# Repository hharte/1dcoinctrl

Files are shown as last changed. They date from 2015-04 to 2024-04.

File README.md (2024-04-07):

# 1dcoinctrl - Issue 4

## Western Electric 1D/2D Payphone Controller Interface for Asterisk

# WARNING - This project involves potentially lethal High-Voltage!

**_The coin relay in most payphones operates using +/- 130VDC.  This project uses a DC-DC converter to boost 12VDC to 130VDC.  Construction and operation of this circuit should only be performed by people familiar with best practices when operating with high voltage, and using extreme caution._**

I WILL NOT BE HELD LIABLE FOR INJURY OR DEATH RESULTING FROM BUILDING OR USING THIS CIRCUIT.   BUILD AND USE THIS CIRCUIT AT YOUR OWN RISK.

THIS HARDWARE AND SOFTWARE IS PROVIDED "AS IS", WITHOUT WARRANTY OF ANY KIND, EXPRESS OR IMPLIED, INCLUDING BUT NOT LIMITED TO THE WARRANTIES OF MERCHANTABILITY, FITNESS FOR A PARTICULAR PURPOSE AND NONINFRINGEMENT.  IN NO EVENT SHALL HOWARD M. HARTE BE LIABLE FOR ANY CLAIM, DAMAGES OR OTHER LIABILITY, WHETHER IN AN ACTION OF CONTRACT, TORT OR OTHERWISE, ARISING FROM, OUT OF OR IN CONNECTION WITH THE HARDWARE AND SOFTWARE OR THE USE OR OTHER DEALINGS IN THE HARDWARE AND SOFTWARE. 

# Overview

This project aims to emulate a coin line as required by the older "dumb" (ie, non-COCOT) payphones such as the Western Electric 1D "Fortress" series.  This coin line interface connects in between an Asterisk PBX and the payphone.  It provides the coin control functionality as well as the ability to determine whether an initial rate has been deposited, and can also perform the "stuck coin" test.

This project is based on another open-source project (see References below) and has the following goals:

1. Real coin-line signaling, while preserving the payphone earth ground.  This requires both +130VDC (coin collect) and -130VDC (coin refund) as well as +25VDC for the "stuck coin" test and -25VDC for the "initial rate" test.
2. The ability to provide up to four coin lines in a single unit.
3. The ability to count dial pulses from Rotary payphones and provide the digits out-of-band to Asterisk.
4. The ability to be [red-boxed](http://en.wikipedia.org/wiki/Red_box_(phreaking)).

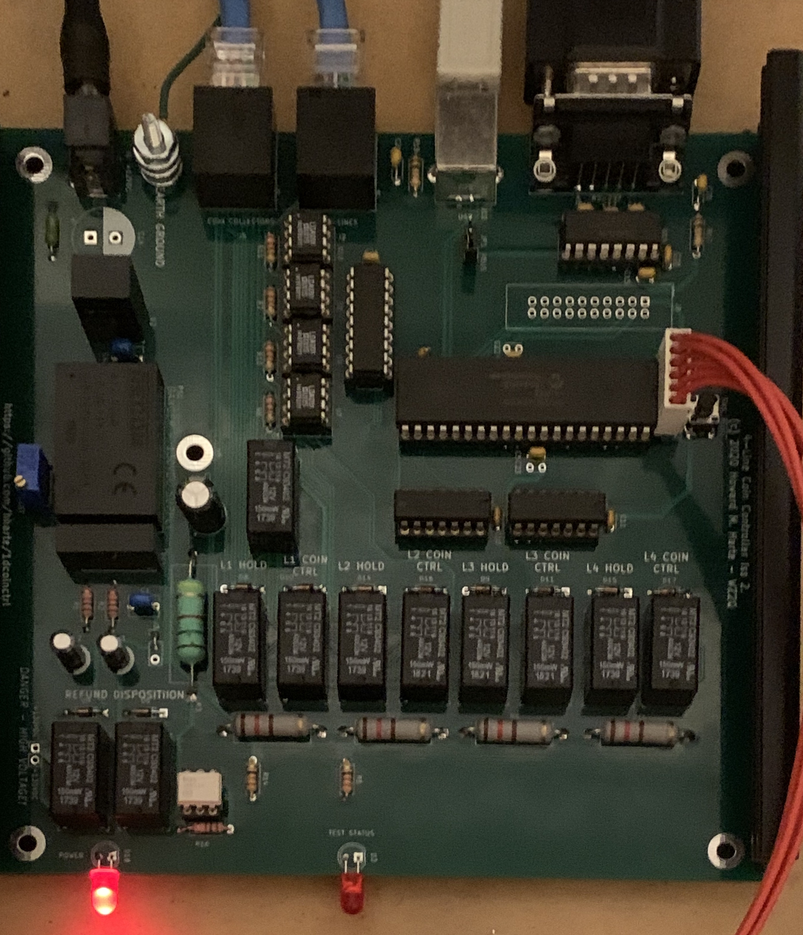
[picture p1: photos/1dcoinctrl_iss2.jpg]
image_tooltip


# Pay phone

The payphone is a standard Western Electric 1D phone with a 32B "dumb" chassis.  I also verified that Western Electric 32A and TeleService 4032C chassis work well with this design.

# Coin Line Signaling

All coin line signaling happens with respect to TIP and Ground with the RING open. For the tests, current flowing when voltage is applied indicates that either a coin is present in the hopper, or the initial rate has been deposited.

<table>
  <tr>
   <td>Voltage
   </td>
   <td>Operation
   </td>
  </tr>
  <tr>
   <td>+130VDC
   </td>
   <td>Collect coins.
   </td>
  </tr>
  <tr>
   <td>-130VDC
   </td>
   <td>Refund coins.
   </td>
  </tr>
  <tr>
   <td>+25VDC
   </td>
   <td>Stuck Coin Test
   </td>
  </tr>
  <tr>
   <td>-25VDC
   </td>
   <td>Initial Rate Test
   </td>
  </tr>
</table>

## Controlling the Coin Line Signaling

Control of the coin lines is handled by a PIC18F47Q84 microcontroller.  This microcontroller can sense the line polarity and ON/OFF hook status, the test status, and can control the relays on the controller.

There are three relays that provide common control, and two additional relays per line.

### Common Control Relays

1. **_REFUND_** Relay: When operated will prepare negative voltage to be applied to the TIP when the selected line's COIN_CONTROL relay is operated.  When this relay is operated, either Coin Refund or Initial Rate Test will be performed based on the state of the DISPOSITION relay.

2. **_DISPOSITION_** Relay: When operated will prepare high voltage (either +130VDC or -130VDC, depending on the state of the REFUND relay) to be applied to the TIP when the selected line's COIN_CONTROL relay is operated.  When the DISPOSITION relay is not operated, low voltage (+25VDC or -25VDC) will be applied in order to perform either the initial rate test or the stuck coin test.

3. **_POLE-CHANGER_** Relay: This relay is used to swap the Vout+ and Vout- on the output of the 130VDC DC-DC converter so that both +130VDC and -130VDC are available depending on whether the coin should be collected or refunded.

### Per-Line Relays, one each per coin line:

1. **_HOLD_** Relay: When operated will shunt the TIP and RING towards the CO (Asterisk PBX in our case) with a 120-ohm resistor.  This will keep the line on hold while coin disposition or rate tests are performed.

2. **_COIN_CONTROL_** Relay: When operated, will apply the coin control voltage to the TIP towards the payphone.  When not operated, the TIP and RING from the CO (Asterisk PBX) will be passed through to the payphone.

### Sensors

There are several opto-isolated sensors in the design to provide status to the microcontroller.

1. **_TEST_STATUS_** sensor will go low when current is flowing during a test.  It will be high when current is not flowing.

2. Per-line **_OFF_HOOK_F and OFF_HOOK_R_** sensors (one per line) will go low when current is flowing through the loop to the CO (Asterisk PBX) and can detect forward and reverse polarity.  This current will be flowing either when the payphone is off-hook or when the line is on hold.  Polarity reversal answer supervision, if provided by your telephone line, can be used to determine whether coins should be collected or refunded.  These LEDs will blink rapidly while a rotary payphone is being dialed.

# Microcontroller Firmware

The microcontroller firmware uses the [Arduino](https://www.arduino.cc/) development environment with the [DxCore library](https://github.com/SpenceKonde/DxCore) for ease of development.  The firmware provides a command-line interface via the serial port that uses a command set modeled after the familiar Hayes AT command set.

The command syntax is AT followed by a single character command, and an optional number [1-4] for the coin line to operate on.  If the coin line is omitted, the previously used coin line is assumed.

Commands are as follows:

<table>
  <tr>
   <td><strong><em>Command</em></strong>
   </td>
   <td><strong><em>Description</em></strong>
   </td>
   <td><strong><em>Response</em></strong>
   </td>
  </tr>
  <tr>
   <td>AT
   </td>
   <td>Attention
   </td>
   <td>OK
   </td>
  </tr>
  <tr>
   <td>ATZ
   </td>
   <td>Reset
   </td>
   <td>OK
   </td>
  </tr>
  <tr>
   <td>ATC
   </td>
   <td>Collect coin
   </td>
   <td>OK
   </td>
  </tr>
  <tr>
   <td>ATR
   </td>
   <td>Refund coin
   </td>
   <td>OK
   </td>
  </tr>
  <tr>
   <td>ATI
   </td>
   <td>Initial rate test
   </td>
   <td>0 = Initial rate not deposited
<p>
1 = Initial rate deposited
   </td>
  </tr>
  <tr>
   <td>ATS
   </td>
   <td>Stuck coin test
   </td>
   <td>0 = No coin in escrow.
<p>
1 = Coin in escrow.
   </td>
  </tr>
  <tr>
   <td>ATQ
   </td>
   <td>Query hook state
   </td>
   <td>0 = On hook
<p>
1 = Off hook (normal polarity)
<p>
2 = Off hook (reversed polarity)
   </td>
  </tr>
  <tr>
   <td>ATL
   </td>
   <td>Query selected coin line
   </td>
   <td>1-4
   </td>
  </tr>
  <tr>
   <td>ATH
   </td>
   <td>Hold CO line
   </td>
   <td>OK
   </td>
  </tr>
  <tr>
   <td>ATU
   </td>
   <td>Un-hold CO line
   </td>
   <td>OK
   </td>
  </tr>
  <tr>
   <td>ATD
   </td>
   <td>Dump current controller state
   </td>
   <td>OK
   </td>
  </tr>
  <tr>
   <td>ATE
   </td>
   <td>Stress test 100 refunds (1s apart)
   </td>
   <td>OK
   </td>
  </tr>
  <tr>
   <td>ATT
   </td>
   <td>Coin line simulation
   </td>
   <td>Need hard reset to exit.
   </td>
  </tr>
  <tr>
   <td>ATV
   </td>
   <td>Display firmware version
   </td>
   <td>OK
   </td>
  </tr>
  <tr>
   <td>AT?
   </td>
   <td>Help
   </td>
   <td>Display command help
   </td>
  </tr>
</table>

# Building the Hardware

## Components

The components for this board can be ordered from Digi-Key using [this parts list](https://www.digikey.com/en/mylists/list/BGQKKBOZGS).  The list includes all components and accessories to build the full board supporting all four coin lines.  The user will need to provide their own 12VDC power supply.

There is an [interactive Bill of Materials here](https://html-preview.github.io/?url=https://github.com/hharte/1dcoinctrl/blob/main/hardware/bom/ibom.html).

## Stuffing Options

### Relay Coil Voltage and DC-DC Converters

The schematic/BOM supports either 5V or 12V coil relays.  Alternatively, the board may be built to support a 24VDC input voltage and the user may use 24V coil relays.  In this case, PS1 and PS2 need to change:

<table>
  <tr>
   <td>Power Supply Voltage
   </td>
   <td>Relay Coil Voltage
   </td>
   <td>J8 Setting
   </td>
   <td>PS1 Part
   </td>
   <td>PS2 Part
   </td>
  </tr>
  <tr>
   <td>+12VDC*
   </td>
   <td>12V*
   </td>
   <td>1-2
   </td>
   <td>R12-100B
   </td>
   <td>IA1224S
   </td>
  </tr>
  <tr>
   <td>+12VDC
   </td>
   <td>5V
   </td>
   <td>2-3
   </td>
   <td>R12-100B
   </td>
   <td>IA1224S
   </td>
  </tr>
  <tr>
   <td>+24VDC
   </td>
   <td>5V
   </td>
   <td>2-3
   </td>
   <td>R24-100B
   </td>
   <td>IA2424S
   </td>
  </tr>
  <tr>
   <td>+24VDC
   </td>
   <td>24V
   </td>
   <td>1-2
   </td>
   <td>R24-100B
   </td>
   <td>IA2424S
   </td>
  </tr>
</table>

### Serial Port - RS-232 or 5V TTL-level UART

Communication with the host computer is either via RS-232 or 5V TTL-level UART.

<table>
  <tr>
   <td><strong><em>Reference Designator</em></strong>
   </td>
   <td><strong><em>RS-232</em></strong>
   </td>
   <td><strong><em>TTL UART </em></strong>
   </td>
   <td><strong><em>Notes</em></strong>
   </td>
  </tr>
  <tr>
   <td>U2
   </td>
   <td>✔
   </td>
   <td>
   </td>
   <td>MAX202 or equivalent.
   </td>
  </tr>
  <tr>
   <td>C3,C4,C5,C6,C8
   </td>
   <td>✔
   </td>
   <td>
   </td>
   <td>0.1uF Capacitor
   </td>
  </tr>
  <tr>
   <td>R2
   </td>
   <td>✔
   </td>
   <td>
   </td>
   <td>
   </td>
  </tr>
  <tr>
   <td>C7
   </td>
   <td>✔
   </td>
   <td>
   </td>
   <td>4700pF Capacitor
   </td>
  </tr>
  <tr>
   <td>JP1
   </td>
   <td>✔
   </td>
   <td>
   </td>
   <td>Programming Enable (to program Microcontroller)
<p>
Remove jumper from JP1 when using a standard FTDI 5V TTL UART cable.
   </td>
  </tr>
  <tr>
   <td>JP2, JP3
   </td>
   <td>1-2
   </td>
   <td>2-3
   </td>
   <td>Jumper 1-2 for RS-232 or 2-3 for TTL UART.
   </td>
  </tr>
  <tr>
   <td>J5
   </td>
   <td>✔
   </td>
   <td>✔
   </td>
   <td>6-pin right angle 0.1” male header.
   </td>
  </tr>
</table>

Note: To switch between RS-232 and TTL UART, U2 can be removed from the socket, and the 5V TTL UART cable attached to J5.  When switching back to the RS-232 port, detach the 5V TTL UART cable from J5 and reinstall U2.  In addition to the TTL UART, J5 is also used to program the microcontroller.

### External +/-130VDC Coin Collect / Refund Supply

The board can accommodate an external +/-130VDC supply with the following assembly changes:

<table>
  <tr>
   <td><strong><em>Reference Designator</em></strong>
   </td>
   <td><strong><em>Populate</em></strong>
   </td>
   <td><strong><em>Do Not Populate</em></strong>
   </td>
   <td><strong><em>Notes</em></strong>
   </td>
  </tr>
  <tr>
   <td>PS1
   </td>
   <td>
   </td>
   <td>✔
   </td>
   <td>
   </td>
  </tr>
  <tr>
   <td>C18
   </td>
   <td>
   </td>
   <td>✔
   </td>
   <td>
   </td>
  </tr>
  <tr>
   <td>D2
   </td>
   <td>
   </td>
   <td>✔
   </td>
   <td>
   </td>
  </tr>
  <tr>
   <td>D1
   </td>
   <td>
   </td>
   <td>✔
   </td>
   <td>V_COIN_RELAY (130VDC) Indicator LED.
   </td>
  </tr>
  <tr>
   <td>K1
   </td>
   <td>
   </td>
   <td>✔
   </td>
   <td>Pole Changer Relay
   </td>
  </tr>
  <tr>
   <td>R15
   </td>
   <td>
   </td>
   <td>✔
   </td>
   <td>
   </td>
  </tr>
  <tr>
   <td>R5
   </td>
   <td>
   </td>
   <td>✔
   </td>
   <td>5K Potentiometer
   </td>
  </tr>
  <tr>
   <td>R9
   </td>
   <td>
   </td>
   <td>✔
   </td>
   <td>V_COIN_RELAY (130VDC) Indicator LED current limit.
   </td>
  </tr>
  <tr>
   <td>F2, F3
   </td>
   <td>✔
   </td>
   <td>
   </td>
   <td>125mA Fuse
   </td>
  </tr>
  <tr>
   <td>R10, R11
   </td>
   <td>✔
   </td>
   <td>
   </td>
   <td>+/- 130VDC LED current limiting.
   </td>
  </tr>
  <tr>
   <td>D3, D13
   </td>
   <td>✔
   </td>
   <td>
   </td>
   <td>+/- 130VDC Indicator LEDs
   </td>
  </tr>
</table>

**_Note:_** To switch between external +/-130 VDC supply and the on-board DC-DC converter:

* At minimum, PS1 and K1 should be removed when using the external supply.  If desired, a socket can be made for PS1 by removing several pins from a 24-pin 0.6” wide, machined-pin DIP socket.  A socket can be made for K1 in a similar fashion, using a 16-pin machined-pin DIP socket.
* At minimum, F2, F3 should be removed when using the on-board DC-DC converter.  This is essential for two reasons:
1. Safety: Prevent V_COIN_RELAY (130VDC) from being present on the +/-130VDC terminals of J1.
2. Protection: to ensure that V_COIN_RELAY is not shorted to the +/-130VDC supply during operation.

**_Warning_**

D1, when illuminated, indicates that 130VDC is present on the board.  While this LED is lit, be very careful not to touch the high-voltage section of the board.

D3, D13, when illuminated, indicates that external +/-130VDC is present on the board.  While either of these LEDs are lit, be very careful not to touch the high-voltage section of the board.

### Less Than Four Coin Lines

The controller can be assembled to support fewer than four pay phones.  If only one pay phone is desired, U3 (7406) can be omitted, as well as components associated with lines 2 through 4.

<table>
  <tr>
   <td><strong><em>Coin Line</em></strong>
   </td>
   <td><strong><em>Reference Designator</em></strong>
   </td>
   <td><strong><em>Do Not Populate</em></strong>
   </td>
   <td><strong><em>Notes</em></strong>
   </td>
  </tr>
  <tr>
   <td rowspan="5" >2
   </td>
   <td>D19
   </td>
   <td>✔
   </td>
   <td>Bi-Color LED
   </td>
  </tr>
  <tr>
   <td>D5, D7
   </td>
   <td>✔
   </td>
   <td>1N4148 Switching Diodes
   </td>
  </tr>
  <tr>
   <td>R4, R16, R24
   </td>
   <td>✔
   </td>
   <td>
   </td>
  </tr>
  <tr>
   <td>K3, K6
   </td>
   <td>✔
   </td>
   <td>Hold / Coin Control Relays
   </td>
  </tr>
  <tr>
   <td>U5
   </td>
   <td>✔
   </td>
   <td>Optoisolator
   </td>
  </tr>
  <tr>
   <td rowspan="5" >3
   </td>
   <td>D20
   </td>
   <td>✔
   </td>
   <td>Bi-Color LED
   </td>
  </tr>
  <tr>
   <td>D8, D10
   </td>
   <td>✔
   </td>
   <td>1N4148 Switching Diodes
   </td>
  </tr>
  <tr>
   <td>R3, R18, R26
   </td>
   <td>✔
   </td>
   <td>
   </td>
  </tr>
  <tr>
   <td>K5, K7
   </td>
   <td>✔
   </td>
   <td>Hold / Coin Control Relays
   </td>
  </tr>
  <tr>
   <td>U4
   </td>
   <td>✔
   </td>
   <td>Optoisolator
   </td>
  </tr>
  <tr>
   <td rowspan="5" >4
   </td>
   <td>D21
   </td>
   <td>✔
   </td>
   <td>Bi-Color LED
   </td>
  </tr>
  <tr>
   <td>D9, D11
   </td>
   <td>✔
   </td>
   <td>1N4148 Switching Diodes
   </td>
  </tr>
  <tr>
   <td>R1, R19, R25
   </td>
   <td>✔
   </td>
   <td>
   </td>
  </tr>
  <tr>
   <td>K8, K9
   </td>
   <td>✔
   </td>
   <td>Hold / Coin Control Relays
   </td>
  </tr>
  <tr>
   <td>U1
   </td>
   <td>✔
   </td>
   <td>Optoisolator
   </td>
  </tr>
</table>

## Enclosure

Included in the parts list is a [Hammond 160mm extruded aluminum enclosure](https://www.hammfg.com/files/parts/pdf/1455R1602BK.pdf).  This enclosure includes end caps that can be cut/drilled for the LEDs in the front of the board, as well as the connectors in the rear.  Alternatively, a design for 3D-printed end caps is included in this project.

## Issue 4 PCB

### Microcontroller Replacement

The PIC microcontroller in previous revisions was replaced with an [AVR128DA28](https://www.microchip.com/en-us/product/avr128da28) in the DIP-28 package.  The firmware uses the [Arduino](https://www.arduino.cc/) development environment with the [DxCore library](https://github.com/SpenceKonde/DxCore) for ease of development and programming.

### Other changes between Issue 3 and Issue 4:

* Additional LED connected to microcontroller pin PA7 under firmware control.

Still need to validate:

1. Coin Lines 2, 3, 4.
2. FTDI 5V TTL UART Connection.
3. 

# Connections

## J3, J4 - Lines

The controller supports four CO lines and four coin collectors via two RJ45 connectors.  Each of these connectors is wired according to [T568A](https://en.wikipedia.org/wiki/ANSI/TIA-568).

<table>
  <tr>
   <td><strong><em>Pin</em></strong>
   </td>
   <td><strong><em>T568A Pair</em></strong>
   </td>
   <td><strong><em>J4</em></strong>
<p>
<strong><em>CO Lines</em></strong>
   </td>
   <td><strong><em>J3</em></strong>
<p>
<strong><em>Coin Phones</em></strong>
   </td>
   <td><strong><em>Color</em></strong>
   </td>
  </tr>
  <tr>
   <td>1
   </td>
   <td>3
   </td>
   <td>L3 Tip
   </td>
   <td>L3 Tip
   </td>
   <td>White/Green
   </td>
  </tr>
  <tr>
   <td>2
   </td>
   <td>3
   </td>
   <td>L3 Ring
   </td>
   <td>L3 Ring
   </td>
   <td>Green/White
   </td>
  </tr>
  <tr>
   <td>3
   </td>
   <td>2
   </td>
   <td>L2 Tip
   </td>
   <td>L2 Tip
   </td>
   <td>White/Orange
   </td>
  </tr>
  <tr>
   <td>4
   </td>
   <td>1
   </td>
   <td>L1 Ring
   </td>
   <td>L1 Ring
   </td>
   <td>Blue/White
   </td>
  </tr>
  <tr>
   <td>5
   </td>
   <td>1
   </td>
   <td>L1 Tip
   </td>
   <td>L1 Tip
   </td>
   <td>White/Blue
   </td>
  </tr>
  <tr>
   <td>6
   </td>
   <td>2
   </td>
   <td>L2 Ring
   </td>
   <td>L2 Ring
   </td>
   <td>Orange/White
   </td>
  </tr>
  <tr>
   <td>7
   </td>
   <td>4
   </td>
   <td>L4 Tip
   </td>
   <td>L4 Tip
   </td>
   <td>White/Brown
   </td>
  </tr>
  <tr>
   <td>8
   </td>
   <td>4
   </td>
   <td>L4 Ring
   </td>
   <td>L4 Ring
   </td>
   <td>Brown/White
   </td>
  </tr>
</table>

## J1 - Power

<table>
  <tr>
   <td>Pin
   </td>
   <td>Description
   </td>
  </tr>
  <tr>
   <td>+12VDC
   </td>
   <td>Positive 12V Input.  This must be positive with respect to GROUND.
   </td>
  </tr>
  <tr>
   <td>GROUND
   </td>
   <td>Power Supply Ground (Must be the same as earth ground.)
   </td>
  </tr>
  <tr>
   <td>+130VDC_IN
   </td>
   <td>Coin voltage + (Optional, board assembly option.)
   </td>
  </tr>
  <tr>
   <td>-130VDC_IN
   </td>
   <td>Coin voltage - (Optional, board assembly option.)
   </td>
  </tr>
</table>

## Earth Ground Lug

Coin control and tests are with respect to earth ground.  All payphones must be grounded and bonded for safety as well as to provide a return path for coin collect/refund as well as the initial rate and stuck coin tests.  If the payphone and coin line controller are not grounded, they will not work properly.

## Serial Port

Communication with the host computer running Asterisk is via an RS-232 serial port at J6.  If the user does not wish to use RS-232 levels to communicate with the computer, then the MAX202 IC at U2 should be removed from the socket.  With the MAX202 removed, a [USB to 5V TTL Serial cable](https://www.digikey.com/en/products/detail/ftdi-future-technology-devices-international-ltd/TTL-232R-5V/2003493) connected to J5 (Ground pin on the left when looking at the rear of the controller) can be used to connect the coin controller to a PC via USB.

# Indicators

The controller includes several indicator LEDs.  Most are on the front panel; however, high-voltage warning LEDs are present inside the enclosure.

<table>
  <tr>
   <td><strong><em>Reference Designator</em></strong>
   </td>
   <td><strong><em>Indicates</em></strong>
   </td>
   <td><strong><em>Notes</em></strong>
   </td>
  </tr>
  <tr>
   <td>D15
   </td>
   <td>Power
   </td>
   <td>Illuminates when +5VDC is present, indicating that the coin controller board is powered.
   </td>
  </tr>
  <tr>
   <td>D16
   </td>
   <td>MCU Status
   </td>
   <td>Illuminated under firmware (PA7) control by the on-board microcontroller.
   </td>
  </tr>
  <tr>
   <td>D17
   </td>
   <td>Test Status
   </td>
   <td>Illuminates during the stuck coin test or the initial rate test if the test result is positive: coin is stuck, initial rate is deposited.  This status is input to the microcontroller on PA6.
   </td>
  </tr>
  <tr>
   <td>D18
   </td>
   <td>L1 Status
   </td>
   <td>Line 1 Hook State:
<ul>

<li>Not illuminated: On-hook

<li>Green: Normal Polarity

<li>Red: Reverse Polarity (Answer supervision.)
</li>
</ul>
   </td>
  </tr>
  <tr>
   <td>D19
   </td>
   <td>L2 Status
   </td>
   <td>Line 2 Hook State
   </td>
  </tr>
  <tr>
   <td>D20
   </td>
   <td>L3 Status
   </td>
   <td>Line 1 Hook State
   </td>
  </tr>
  <tr>
   <td>D21
   </td>
   <td>L4 Status
   </td>
   <td>Line 1 Hook State
   </td>
  </tr>
  <tr>
   <td>D1
   </td>
   <td>V_COIN_RELAY
   </td>
   <td>(Internal) 130VDC produced by the on-board DC-DC converter.
   </td>
  </tr>
  <tr>
   <td>D3
   </td>
   <td>+130VDC
   </td>
   <td>(Internal) Indicates +130VDC from the external supply is present.
   </td>
  </tr>
  <tr>
   <td>D13
   </td>
   <td>-130VDC
   </td>
   <td>(Internal) Indicates -130VDC from the external supply is present.
   </td>
  </tr>
</table>

# Asterisk PBX Modifications

Modifications to Asterisk in order to recognize the 1700/2200Hz coin tones is based on [Joshua Stein's project](https://github.com/jcs/payphone) although I modified them to treat the 1700/2200Hz tones as a 5th row/column in the standard [DTMF](http://en.wikipedia.org/wiki/Dual-tone_multi-frequency_signaling) decoding routine in Asterisk's main/dsp.c.

The Asterisk AGI script is not complete, but at present it will prompt for money and can recognize the coin tones.  It will complete the call after 25 cents has been deposited.

## References

* [https://github.com/jcs/payphone](https://github.com/jcs/payphone)
* [Bell System Public Services Crafts' Manual for Station, Network, and Testboard](http://wedophones.com/TheBellSystem/pdf/bsp/coin/PublicServices1.pdf)

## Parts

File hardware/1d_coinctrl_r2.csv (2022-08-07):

Source: | C:\Users\hharte\source\repos\1dcoinctrl\hardware\1d_coinctrl_r2.kicad_sch
Date: | 8/7/2022 11:28:44 AM
Tool: | Eeschema (6.0.6)
Generator: | C:\Program Files\KiCad\6.0\bin\scripting\plugins/bom_csv_grouped_by_value.py
Component Count: | 100
Individual Components:
Item | Qty | Reference(s) | Value | LibPart | Footprint | Datasheet | Category | DK_Datasheet_Link | DK_Detail_Page | Description | Digi-Key_PN | Family | Field4 | Field5 | Field6 | MANUFACTURER | MPN | Manufacturer | STANDARD | Status
 |  | C1 | 4700pF | Device:C | Capacitor_THT:C_Disc_D4.3mm_W1.9mm_P5.00mm | https://www.digikey.com/product-detail/en/kemet/C317C472K1R5TA7301/399-13937-1-ND/6562530
 |  | C2 | 0.1uF | Device:C | Capacitor_THT:C_Disc_D3.0mm_W2.0mm_P2.50mm | https://www.digikey.com/product-detail/en/vishay-bc-components/K104Z15Y5VE5TL2/BC1148CT-ND/286770
 |  | C3 | 0.1uF | Device:C | Capacitor_THT:C_Disc_D3.0mm_W2.0mm_P2.50mm | https://www.digikey.com/product-detail/en/vishay-bc-components/K104Z15Y5VE5TL2/BC1148CT-ND/286770
 |  | C4 | 0.01uF | Device:C | Capacitor_THT:C_Disc_D3.0mm_W1.6mm_P2.50mm | ~
 |  | C5 | 0.1uF | Device:C | Capacitor_THT:C_Disc_D3.0mm_W2.0mm_P2.50mm | https://www.digikey.com/product-detail/en/vishay-bc-components/K104Z15Y5VE5TL2/BC1148CT-ND/286770
 |  | C6 | 0.1uF | Device:C | Capacitor_THT:C_Disc_D3.0mm_W2.0mm_P2.50mm | https://www.digikey.com/product-detail/en/vishay-bc-components/K104Z15Y5VE5TL2/BC1148CT-ND/286770
 |  | C7 | 0.1uF | Device:C | Capacitor_THT:C_Disc_D3.0mm_W2.0mm_P2.50mm | https://www.digikey.com/product-detail/en/vishay-bc-components/K104Z15Y5VE5TL2/BC1148CT-ND/286770
 |  | C8 | 0.1uF | Device:C | Capacitor_THT:C_Disc_D3.0mm_W2.0mm_P2.50mm | ~
 |  | C9 | 0.001uF | Device:C | Capacitor_THT:C_Disc_D3.0mm_W2.0mm_P2.50mm | ~
 |  | C10 | 0.1uF | Device:C | Capacitor_THT:C_Disc_D3.0mm_W2.0mm_P2.50mm | ~
 |  | C11 | 0.1uF | Device:C | Capacitor_THT:C_Disc_D3.0mm_W2.0mm_P2.50mm | ~
 |  | C12 | 0.001uF | Device:C | Capacitor_THT:C_Disc_D3.0mm_W2.0mm_P2.50mm | ~
 |  | C13 | 0.1uF | Device:C | Capacitor_THT:C_Disc_D3.0mm_W2.0mm_P2.50mm | ~
 |  | C14 | 4.7uF 250V | Device:C_Polarized_US | Capacitor_THT:CP_Radial_D8.0mm_P3.50mm | ~
 |  | C15 | 10uF 25V | Device:C_Polarized_US | Capacitor_THT:C_Disc_D6.0mm_W4.4mm_P5.00mm | ~
 |  | C16 | 1000uF 25V | Device:C_Polarized_US | Capacitor_THT:CP_Radial_D12.5mm_P5.00mm | ~
 |  | C17 | 0.1uF | Device:C | Capacitor_THT:C_Disc_D3.0mm_W2.0mm_P2.50mm | ~
 |  | C18 | 22uF 16V | Device:C_Polarized_US | Capacitor_THT:C_Disc_D6.0mm_W4.4mm_P5.00mm | ~
 |  | C19 | 10uF 25V | Device:C_Polarized_US | Capacitor_THT:C_Disc_D6.0mm_W4.4mm_P5.00mm | ~
 |  | C20 | 10uF 50V | Device:C_Polarized_US | Capacitor_THT:CP_Radial_D6.3mm_P2.50mm | ~
 |  | C21 | 10uF 50V | Device:C_Polarized_US | Capacitor_THT:CP_Radial_D6.3mm_P2.50mm | ~
 |  | D1 | 1N4148 | Diode:1N4148 | Diode_THT:D_DO-35_SOD27_P7.62mm_Horizontal | http://www.nxp.com/documents/data_sheet/1N4148_1N4448.pdf
 |  | D2 | LED_Dual_KAK | Device:LED_Dual_KAK | LED_THT:LED_D5.0mm-3 | https://www.sunledusa.com/products/spec/XLMDKVG59MCA.pdf
 |  | D3 | 1N4148 | Diode:1N4148 | Diode_THT:D_DO-35_SOD27_P7.62mm_Horizontal | http://www.nxp.com/documents/data_sheet/1N4148_1N4448.pdf
 |  | D4 | 1N4148 | Diode:1N4148 | Diode_THT:D_DO-35_SOD27_P7.62mm_Horizontal | http://www.nxp.com/documents/data_sheet/1N4148_1N4448.pdf
 |  | D5 | LED_Dual_KAK | Device:LED_Dual_KAK | LED_THT:LED_D5.0mm-3 | https://www.sunledusa.com/products/spec/XLMDKVG59MCA.pdf
 |  | D6 | LED_Dual_KAK | Device:LED_Dual_KAK | LED_THT:LED_D5.0mm-3 | https://www.sunledusa.com/products/spec/XLMDKVG59MCA.pdf
 |  | D7 | 1N4148 | Diode:1N4148 | Diode_THT:D_DO-35_SOD27_P7.62mm_Horizontal | http://www.nxp.com/documents/data_sheet/1N4148_1N4448.pdf
 |  | D8 | 1N4148 | Diode:1N4148 | Diode_THT:D_DO-35_SOD27_P7.62mm_Horizontal | http://www.nxp.com/documents/data_sheet/1N4148_1N4448.pdf
 |  | D9 | LED_Dual_KAK | Device:LED_Dual_KAK | LED_THT:LED_D5.0mm-3 | https://www.sunledusa.com/products/spec/XLMDKVG59MCA.pdf
 |  | D10 | 1N4148 | Diode:1N4148 | Diode_THT:D_DO-35_SOD27_P7.62mm_Horizontal | http://www.nxp.com/documents/data_sheet/1N4148_1N4448.pdf
 |  | D11 | 1N4148 | Diode:1N4148 | Diode_THT:D_DO-35_SOD27_P7.62mm_Horizontal | http://www.nxp.com/documents/data_sheet/1N4148_1N4448.pdf
 |  | D12 | 1N4148 | Diode:1N4148 | Diode_THT:D_DO-35_SOD27_P7.62mm_Horizontal | http://www.nxp.com/documents/data_sheet/1N4148_1N4448.pdf
 |  | D13 | LED | Device:LED | LED_THT:LED_D5.0mm | ~
 |  | D14 | 1N4148 | Diode:1N4148 | Diode_THT:D_DO-35_SOD27_P7.62mm_Horizontal | http://www.nxp.com/documents/data_sheet/1N4148_1N4448.pdf
 |  | D15 | 1N4148 | Diode:1N4148 | Diode_THT:D_DO-35_SOD27_P7.62mm_Horizontal | http://www.nxp.com/documents/data_sheet/1N4148_1N4448.pdf
 |  | D16 | 1N4148 | Diode:1N4148 | Diode_THT:D_DO-35_SOD27_P7.62mm_Horizontal | http://www.nxp.com/documents/data_sheet/1N4148_1N4448.pdf
 |  | D17 | POWER_LED | Device:LED | LED_THT:LED_D5.0mm | ~
 |  | F1 | Fuse | Device:Fuse | Resistor_THT:R_Axial_DIN0207_L6.3mm_D2.5mm_P10.16mm_Horizontal | ~
 |  | F2 | Fuse 100mA | Device:Fuse | Resistor_THT:R_Axial_DIN0309_L9.0mm_D3.2mm_P12.70mm_Horizontal | https://www.digikey.com/product-detail/en/littelfuse-inc/0251-630MXL/F2312-ND/700711
 |  | F3 | Fuse 100mA | Device:Fuse | Resistor_THT:R_Axial_DIN0309_L9.0mm_D3.2mm_P12.70mm_Horizontal | https://www.digikey.com/product-detail/en/littelfuse-inc/0251-630MXL/F2312-ND/700711
 |  | H1 | MountingHole | Mechanical:MountingHole | MountingHole:MountingHole_3.7mm_Pad | ~
 |  | H2 | MountingHole | Mechanical:MountingHole | MountingHole:MountingHole_3.7mm_Pad | ~
 |  | H3 | MountingHole_Pad | Mechanical:MountingHole_Pad | MountingHole:MountingHole_3.7mm_Pad | ~
 |  | H4 | MountingHole | Mechanical:MountingHole | MountingHole:MountingHole_3.7mm_Pad | ~
 |  | H5 | MountingHole_Pad | Mechanical:MountingHole_Pad | MountingHole:MountingHole_3.7mm_Pad | ~
 |  | H6 | MountingHole | Mechanical:MountingHole | MountingHole:MountingHole_3.7mm_Pad | ~
 |  | J1 | Conn_01x06_Male | Connector:Conn_01x06_Male | Connector_PinHeader_2.54mm:PinHeader_1x06_P2.54mm_Vertical | ~
 |  | J2 | DB9_Female_MountingHoles | Connector:DB9_Female_MountingHoles | Connector_Dsub:DSUB-9_Female_Horizontal_P2.77x2.84mm_EdgePinOffset7.70mm_Housed_MountingHolesOffset9.12mm | ~
 |  | J3 | Conn_02x10_Odd_Even | Connector_Generic:Conn_02x10_Odd_Even | Connector_IDC:IDC-Header_2x10_P2.54mm_Vertical | ~
 |  | J4 | Conn_01x06_Male | Connector:Conn_01x06_Male | Connector_PinHeader_2.54mm:PinHeader_1x06_P2.54mm_Horizontal | ~
 |  | J5 | CO LINE | Connector:8P8C | Connector_RJ:RJ45_Amphenol_54602-x08_Horizontal | ~
 |  | J6 | COIN LINE | Connector:8P8C | Connector_RJ:RJ45_Amphenol_54602-x08_Horizontal | ~
 |  | J7 | V_RLY_SEL | Connector_Generic:Conn_01x03 | Connector_PinHeader_2.54mm:PinHeader_1x03_P2.54mm_Vertical | ~
 |  | J8 | TBP01R1-508-04BE | TBP01R1-508-04BE:TBP01R1-508-04BE | hardware:CUI_TBP01R1-508-04BE |  |  |  |  |  |  |  |  |  |  | CUI |  |  | Manufacturer Recommendations
 |  | K1 | L4_COIN_CTRL | 1d_coinctrl_r2-rescue:G5V-2-DC12-dk_Signal-Relays-Up-to-2-Amps | digikey-footprints:Relay_THT_G5V-2 | http://omronfs.omron.com/en_US/ecb/products/pdf/en-g5v_2.pdf | Relays | http://omronfs.omron.com/en_US/ecb/products/pdf/en-g5v_2.pdf | /product-detail/en/omron-electronics-inc-emc-div/G5V-2-DC12/Z768-ND/87821 | RELAY GEN PURPOSE DPDT 2A 12V | PB1125-ND | Signal Relays, Up to 2 Amps |  |  |  |  | G5V-2-DC12 | Omron Electronics Inc-EMC Div |  | Active
 |  | K2 | L4_HOLD | 1d_coinctrl_r2-rescue:G5V-2-DC12-dk_Signal-Relays-Up-to-2-Amps | digikey-footprints:Relay_THT_G5V-2 | http://omronfs.omron.com/en_US/ecb/products/pdf/en-g5v_2.pdf | Relays | http://omronfs.omron.com/en_US/ecb/products/pdf/en-g5v_2.pdf | /product-detail/en/omron-electronics-inc-emc-div/G5V-2-DC12/Z768-ND/87821 | RELAY GEN PURPOSE DPDT 2A 12V | PB1125-ND | Signal Relays, Up to 2 Amps |  |  |  |  | G5V-2-DC12 | Omron Electronics Inc-EMC Div |  | Active
 |  | K3 | L3_COIN_CTRL | 1d_coinctrl_r2-rescue:G5V-2-DC12-dk_Signal-Relays-Up-to-2-Amps | digikey-footprints:Relay_THT_G5V-2 | http://omronfs.omron.com/en_US/ecb/products/pdf/en-g5v_2.pdf | Relays | http://omronfs.omron.com/en_US/ecb/products/pdf/en-g5v_2.pdf | /product-detail/en/omron-electronics-inc-emc-div/G5V-2-DC12/Z768-ND/87821 | RELAY GEN PURPOSE DPDT 2A 12V | PB1125-ND | Signal Relays, Up to 2 Amps |  |  |  |  | G5V-2-DC12 | Omron Electronics Inc-EMC Div |  | Active
 |  | K4 | L3_HOLD | 1d_coinctrl_r2-rescue:G5V-2-DC12-dk_Signal-Relays-Up-to-2-Amps | digikey-footprints:Relay_THT_G5V-2 | http://omronfs.omron.com/en_US/ecb/products/pdf/en-g5v_2.pdf | Relays | http://omronfs.omron.com/en_US/ecb/products/pdf/en-g5v_2.pdf | /product-detail/en/omron-electronics-inc-emc-div/G5V-2-DC12/Z768-ND/87821 | RELAY GEN PURPOSE DPDT 2A 12V | PB1125-ND | Signal Relays, Up to 2 Amps |  |  |  |  | G5V-2-DC12 | Omron Electronics Inc-EMC Div |  | Active
 |  | K5 | L2_COIN_CTRL | 1d_coinctrl_r2-rescue:G5V-2-DC12-dk_Signal-Relays-Up-to-2-Amps | digikey-footprints:Relay_THT_G5V-2 | http://omronfs.omron.com/en_US/ecb/products/pdf/en-g5v_2.pdf | Relays | http://omronfs.omron.com/en_US/ecb/products/pdf/en-g5v_2.pdf | /product-detail/en/omron-electronics-inc-emc-div/G5V-2-DC12/Z768-ND/87821 | RELAY GEN PURPOSE DPDT 2A 12V | PB1125-ND | Signal Relays, Up to 2 Amps |  |  |  |  | G5V-2-DC12 | Omron Electronics Inc-EMC Div |  | Active
 |  | K6 | L2_HOLD | 1d_coinctrl_r2-rescue:G5V-2-DC12-dk_Signal-Relays-Up-to-2-Amps | digikey-footprints:Relay_THT_G5V-2 | http://omronfs.omron.com/en_US/ecb/products/pdf/en-g5v_2.pdf | Relays | http://omronfs.omron.com/en_US/ecb/products/pdf/en-g5v_2.pdf | /product-detail/en/omron-electronics-inc-emc-div/G5V-2-DC12/Z768-ND/87821 | RELAY GEN PURPOSE DPDT 2A 12V | PB1125-ND | Signal Relays, Up to 2 Amps |  |  |  |  | G5V-2-DC12 | Omron Electronics Inc-EMC Div |  | Active
 |  | K7 | L1_COIN_CTRL | 1d_coinctrl_r2-rescue:G5V-2-DC12-dk_Signal-Relays-Up-to-2-Amps | digikey-footprints:Relay_THT_G5V-2 | http://omronfs.omron.com/en_US/ecb/products/pdf/en-g5v_2.pdf | Relays | http://omronfs.omron.com/en_US/ecb/products/pdf/en-g5v_2.pdf | /product-detail/en/omron-electronics-inc-emc-div/G5V-2-DC12/Z768-ND/87821 | RELAY GEN PURPOSE DPDT 2A 12V | PB1125-ND | Signal Relays, Up to 2 Amps |  |  |  |  | G5V-2-DC12 | Omron Electronics Inc-EMC Div |  | Active
 |  | K8 | G5V-2-DC12 | 1d_coinctrl_r2-rescue:G5V-2-DC12-dk_Signal-Relays-Up-to-2-Amps | digikey-footprints:Relay_THT_G5V-2 | http://omronfs.omron.com/en_US/ecb/products/pdf/en-g5v_2.pdf | Relays | http://omronfs.omron.com/en_US/ecb/products/pdf/en-g5v_2.pdf | /product-detail/en/omron-electronics-inc-emc-div/G5V-2-DC12/Z768-ND/87821 | RELAY GEN PURPOSE DPDT 2A 12V | PB1125-ND | Signal Relays, Up to 2 Amps |  |  |  |  | G5V-2-DC12 | Omron Electronics Inc-EMC Div |  | Active
 |  | K9 | L1_HOLD | 1d_coinctrl_r2-rescue:G5V-2-DC12-dk_Signal-Relays-Up-to-2-Amps | digikey-footprints:Relay_THT_G5V-2 | http://omronfs.omron.com/en_US/ecb/products/pdf/en-g5v_2.pdf | Relays | http://omronfs.omron.com/en_US/ecb/products/pdf/en-g5v_2.pdf | /product-detail/en/omron-electronics-inc-emc-div/G5V-2-DC12/Z768-ND/87821 | RELAY GEN PURPOSE DPDT 2A 12V | PB1125-ND | Signal Relays, Up to 2 Amps |  |  |  |  | G5V-2-DC12 | Omron Electronics Inc-EMC Div |  | Active
 |  | K10 | G5V-2-DC12 | 1d_coinctrl_r2-rescue:G5V-2-DC12-dk_Signal-Relays-Up-to-2-Amps | digikey-footprints:Relay_THT_G5V-2 | http://omronfs.omron.com/en_US/ecb/products/pdf/en-g5v_2.pdf | Relays | http://omronfs.omron.com/en_US/ecb/products/pdf/en-g5v_2.pdf | /product-detail/en/omron-electronics-inc-emc-div/G5V-2-DC12/Z768-ND/87821 | RELAY GEN PURPOSE DPDT 2A 12V | Z768-ND | Signal Relays, Up to 2 Amps |  |  |  |  | G5V-2-DC12 | Omron Electronics Inc-EMC Div |  | Active
 |  | K11 | G5V-2-DC12 | 1d_coinctrl_r2-rescue:G5V-2-DC12-dk_Signal-Relays-Up-to-2-Amps | digikey-footprints:Relay_THT_G5V-2 | http://omronfs.omron.com/en_US/ecb/products/pdf/en-g5v_2.pdf | Relays | http://omronfs.omron.com/en_US/ecb/products/pdf/en-g5v_2.pdf | /product-detail/en/omron-electronics-inc-emc-div/G5V-2-DC12/Z768-ND/87821 | RELAY GEN PURPOSE DPDT 2A 12V | Z768-ND | Signal Relays, Up to 2 Amps |  |  |  |  | G5V-2-DC12 | Omron Electronics Inc-EMC Div |  | Active
 |  | PS1 | IA1224S | 1d_coinctrl_r2-rescue:IA1224S-dk_DC-DC-Converters | 1dcoinctrl_r2:IA1224S | https://www.cui.com/product/resource/digikeypdf/v78-500.pdf | Power Supplies - Board Mount | https://www.cui.com/product/resource/digikeypdf/v78-500.pdf | /product-detail/en/cui-inc/V7805-500/102-1709-ND/1828602 | DC DC CONVERTER 5V 2.5W | 102-1709-ND | DC DC Converters |  |  |  |  | V7805-500 | CUI Inc. |  | Active
 |  | PS2 | R12-100B | 1d_coinctrl_r2-rescue:R12-100B-R12-100B | kicad-snapeda:CONV_R12-100B | 7 |  |  |  |  |  |  | Recom | 9.4mm | Manufacturer Recommendations
 |  | R1 | 1M | Device:R_US | Resistor_THT:R_Axial_DIN0207_L6.3mm_D2.5mm_P7.62mm_Horizontal | ~
 |  | R2 | 10K | Device:R_US | Resistor_THT:R_Axial_DIN0207_L6.3mm_D2.5mm_P7.62mm_Horizontal | ~
 |  | R3 | 120 2W | Device:R_US | Resistor_THT:R_Axial_DIN0516_L15.5mm_D5.0mm_P20.32mm_Horizontal | ~
 |  | R4 | 220 | Device:R_US | Resistor_THT:R_Axial_DIN0207_L6.3mm_D2.5mm_P7.62mm_Horizontal | ~
 |  | R5 | 220 | Device:R_US | Resistor_THT:R_Axial_DIN0207_L6.3mm_D2.5mm_P7.62mm_Horizontal | ~
 |  | R6 | 120 2W | Device:R_US | Resistor_THT:R_Axial_DIN0516_L15.5mm_D5.0mm_P20.32mm_Horizontal | ~
 |  | R7 | 220 | Device:R_US | Resistor_THT:R_Axial_DIN0207_L6.3mm_D2.5mm_P7.62mm_Horizontal | ~
 |  | R8 | 220 | Device:R_US | Resistor_THT:R_Axial_DIN0207_L6.3mm_D2.5mm_P7.62mm_Horizontal | ~
 |  | R9 | 220 | Device:R_US | Resistor_THT:R_Axial_DIN0207_L6.3mm_D2.5mm_P7.62mm_Horizontal | ~
 |  | R10 | 120 2W | Device:R_US | Resistor_THT:R_Axial_DIN0516_L15.5mm_D5.0mm_P20.32mm_Horizontal | ~
 |  | R11 | 120 | Device:R_US | Resistor_THT:R_Axial_DIN0207_L6.3mm_D2.5mm_P7.62mm_Horizontal | ~
 |  | R12 | 120 | Device:R_US | Resistor_THT:R_Axial_DIN0207_L6.3mm_D2.5mm_P7.62mm_Horizontal | ~
 |  | R13 | 120 | Device:R_US | Resistor_THT:R_Axial_DIN0207_L6.3mm_D2.5mm_P7.62mm_Horizontal | ~
 |  | R14 | 120 | Device:R_US | Resistor_THT:R_Axial_DIN0207_L6.3mm_D2.5mm_P7.62mm_Horizontal | ~
 |  | R15 | 120 2W | Device:R_US | Resistor_THT:R_Axial_DIN0516_L15.5mm_D5.0mm_P20.32mm_Horizontal | ~
 |  | R16 | 1.5K 5W | Device:R_US | Resistor_THT:R_Axial_Power_L25.0mm_W9.0mm_P30.48mm | ~
 |  | R17 | 220 | Device:R_US | Resistor_THT:R_Axial_DIN0207_L6.3mm_D2.5mm_P7.62mm_Horizontal | ~
 |  | R18 | 1.5K 1W | Device:R_US | Resistor_THT:R_Axial_DIN0207_L6.3mm_D2.5mm_P10.16mm_Horizontal | ~
 |  | R19 | 5K | Device:R_Potentiometer_US | Potentiometer_THT:Potentiometer_Bourns_3266W_Vertical | ~
 |  | R20 | 1.5K 1W | Device:R_US | Resistor_THT:R_Axial_DIN0207_L6.3mm_D2.5mm_P10.16mm_Horizontal | ~
 |  | R21 | 1.5K 1W | Device:R_US | Resistor_THT:R_Axial_DIN0207_L6.3mm_D2.5mm_P10.16mm_Horizontal | ~
 |  | SW1 | SW_Push | Switch:SW_Push | Button_Switch_THT:SW_PUSH_6mm | ~
 |  | U1 | MAX202 | Interface_UART:MAX202 | Package_DIP:DIP-16_W7.62mm | http://www.ti.com/lit/ds/symlink/max202.pdf
 |  | U2 | PIC18F47Q84-IP | MCU_Microchip_PIC18:PIC18F4550-IP | Package_DIP:DIP-40_W15.24mm | http://ww1.microchip.com/downloads/en/DeviceDoc/39760d.pdf
 |  | U3 | 74LS06 | 74xx:74LS06 | Package_DIP:DIP-14_W7.62mm | http://www.ti.com/lit/gpn/sn74LS06
 |  | U4 | 74LS06 | 74xx:74LS06 | Package_DIP:DIP-14_W7.62mm | http://www.ti.com/lit/gpn/sn74LS06
 |  | U5 | ILD74 | Isolator:ILD74 | Package_DIP:DIP-8_W7.62mm_Socket | https://www.vishay.com/docs/83640/ild74.pdf
 |  | U6 | ILD74 | Isolator:ILD74 | Package_DIP:DIP-8_W7.62mm_Socket | https://www.vishay.com/docs/83640/ild74.pdf
 |  | U7 | ILD74 | Isolator:ILD74 | Package_DIP:DIP-8_W7.62mm_Socket | https://www.vishay.com/docs/83640/ild74.pdf
 |  | U8 | ILD74 | Isolator:ILD74 | Package_DIP:DIP-8_W7.62mm_Socket | https://www.vishay.com/docs/83640/ild74.pdf
 |  | U9 | ILD74 | Isolator:ILD74 | Package_DIP:DIP-8_W7.62mm_Socket | https://www.vishay.com/docs/83640/ild74.pdf
 |  | U10 | V7805-1000 | 1d_coinctrl_r2-rescue:V7805-1000-dk_DC-DC-Converters | digikey-footprints:3-SIP_Module_V7805-1000 | https://www.cui.com/product/resource/digikeypdf/v78xx-1000.pdf | Power Supplies - Board Mount | https://www.cui.com/product/resource/digikeypdf/v78xx-1000.pdf | /product-detail/en/cui-inc/V7805-1000/102-1715-ND/1828608 | DC DC CONVERTER 5V 5W | 102-1715-ND | DC DC Converters |  |  |  |  | V7805-1000 | CUI Inc. |  | Active
Collated Components:
Item | Qty | Reference(s) | Value | LibPart | Footprint | Datasheet | Category | DK_Datasheet_Link | DK_Detail_Page | Description | Digi-Key_PN | Family | Field4 | Field5 | Field6 | MANUFACTURER | MPN | Manufacturer | STANDARD | Status
1 | 1 | C1 | 4700pF | Device:C | Capacitor_THT:C_Disc_D4.3mm_W1.9mm_P5.00mm | https://www.digikey.com/product-detail/en/kemet/C317C472K1R5TA7301/399-13937-1-ND/6562530
2 | 10 | C2, C3, C5, C6, C7, C8, C10, C11, C13, C17 | 0.1uF | Device:C | Capacitor_THT:C_Disc_D3.0mm_W2.0mm_P2.50mm | https://www.digikey.com/product-detail/en/vishay-bc-components/K104Z15Y5VE5TL2/BC1148CT-ND/286770
3 | 1 | C4 | 0.01uF | Device:C | Capacitor_THT:C_Disc_D3.0mm_W1.6mm_P2.50mm | ~
4 | 2 | C9, C12 | 0.001uF | Device:C | Capacitor_THT:C_Disc_D3.0mm_W2.0mm_P2.50mm | ~
5 | 1 | C14 | 4.7uF 250V | Device:C_Polarized_US | Capacitor_THT:CP_Radial_D8.0mm_P3.50mm | ~
6 | 2 | C15, C19 | 10uF 25V | Device:C_Polarized_US | Capacitor_THT:C_Disc_D6.0mm_W4.4mm_P5.00mm | ~
7 | 1 | C16 | 1000uF 25V | Device:C_Polarized_US | Capacitor_THT:CP_Radial_D12.5mm_P5.00mm | ~
8 | 1 | C18 | 22uF 16V | Device:C_Polarized_US | Capacitor_THT:C_Disc_D6.0mm_W4.4mm_P5.00mm | ~
9 | 2 | C20, C21 | 10uF 50V | Device:C_Polarized_US | Capacitor_THT:CP_Radial_D6.3mm_P2.50mm | ~
10 | 11 | D1, D3, D4, D7, D8, D10, D11, D12, D14, D15, D16 | 1N4148 | Diode:1N4148 | Diode_THT:D_DO-35_SOD27_P7.62mm_Horizontal | http://www.nxp.com/documents/data_sheet/1N4148_1N4448.pdf
11 | 4 | D2, D5, D6, D9 | LED_Dual_KAK | Device:LED_Dual_KAK | LED_THT:LED_D5.0mm-3 | https://www.sunledusa.com/products/spec/XLMDKVG59MCA.pdf
12 | 1 | D13 | LED | Device:LED | LED_THT:LED_D5.0mm | ~
13 | 1 | D17 | POWER_LED | Device:LED | LED_THT:LED_D5.0mm | ~
14 | 1 | F1 | Fuse | Device:Fuse | Resistor_THT:R_Axial_DIN0207_L6.3mm_D2.5mm_P10.16mm_Horizontal | ~
15 | 2 | F2, F3 | Fuse 100mA | Device:Fuse | Resistor_THT:R_Axial_DIN0309_L9.0mm_D3.2mm_P12.70mm_Horizontal | https://www.digikey.com/product-detail/en/littelfuse-inc/0251-630MXL/F2312-ND/700711
16 | 4 | H1, H2, H4, H6 | MountingHole | Mechanical:MountingHole | MountingHole:MountingHole_3.7mm_Pad | ~
17 | 2 | H3, H5 | MountingHole_Pad | Mechanical:MountingHole_Pad | MountingHole:MountingHole_3.7mm_Pad | ~
18 | 1 | J1 | Conn_01x06_Male | Connector:Conn_01x06_Male | Connector_PinHeader_2.54mm:PinHeader_1x06_P2.54mm_Vertical | ~
19 | 1 | J2 | DB9_Female_MountingHoles | Connector:DB9_Female_MountingHoles | Connector_Dsub:DSUB-9_Female_Horizontal_P2.77x2.84mm_EdgePinOffset7.70mm_Housed_MountingHolesOffset9.12mm | ~
20 | 1 | J3 | Conn_02x10_Odd_Even | Connector_Generic:Conn_02x10_Odd_Even | Connector_IDC:IDC-Header_2x10_P2.54mm_Vertical | ~
21 | 1 | J4 | Conn_01x06_Male | Connector:Conn_01x06_Male | Connector_PinHeader_2.54mm:PinHeader_1x06_P2.54mm_Horizontal | ~
22 | 1 | J5 | CO LINE | Connector:8P8C | Connector_RJ:RJ45_Amphenol_54602-x08_Horizontal | ~
23 | 1 | J6 | COIN LINE | Connector:8P8C | Connector_RJ:RJ45_Amphenol_54602-x08_Horizontal | ~
24 | 1 | J7 | V_RLY_SEL | Connector_Generic:Conn_01x03 | Connector_PinHeader_2.54mm:PinHeader_1x03_P2.54mm_Vertical | ~
25 | 1 | J8 | TBP01R1-508-04BE | TBP01R1-508-04BE:TBP01R1-508-04BE | hardware:CUI_TBP01R1-508-04BE |  |  |  |  |  |  |  |  |  |  | CUI |  |  | Manufacturer Recommendations
26 | 1 | K1 | L4_COIN_CTRL | 1d_coinctrl_r2-rescue:G5V-2-DC12-dk_Signal-Relays-Up-to-2-Amps | digikey-footprints:Relay_THT_G5V-2 | http://omronfs.omron.com/en_US/ecb/products/pdf/en-g5v_2.pdf | Relays | http://omronfs.omron.com/en_US/ecb/products/pdf/en-g5v_2.pdf | /product-detail/en/omron-electronics-inc-emc-div/G5V-2-DC12/Z768-ND/87821 | RELAY GEN PURPOSE DPDT 2A 12V | PB1125-ND | Signal Relays, Up to 2 Amps |  |  |  |  | G5V-2-DC12 | Omron Electronics Inc-EMC Div |  | Active
27 | 1 | K2 | L4_HOLD | 1d_coinctrl_r2-rescue:G5V-2-DC12-dk_Signal-Relays-Up-to-2-Amps | digikey-footprints:Relay_THT_G5V-2 | http://omronfs.omron.com/en_US/ecb/products/pdf/en-g5v_2.pdf | Relays | http://omronfs.omron.com/en_US/ecb/products/pdf/en-g5v_2.pdf | /product-detail/en/omron-electronics-inc-emc-div/G5V-2-DC12/Z768-ND/87821 | RELAY GEN PURPOSE DPDT 2A 12V | PB1125-ND | Signal Relays, Up to 2 Amps |  |  |  |  | G5V-2-DC12 | Omron Electronics Inc-EMC Div |  | Active
28 | 1 | K3 | L3_COIN_CTRL | 1d_coinctrl_r2-rescue:G5V-2-DC12-dk_Signal-Relays-Up-to-2-Amps | digikey-footprints:Relay_THT_G5V-2 | http://omronfs.omron.com/en_US/ecb/products/pdf/en-g5v_2.pdf | Relays | http://omronfs.omron.com/en_US/ecb/products/pdf/en-g5v_2.pdf | /product-detail/en/omron-electronics-inc-emc-div/G5V-2-DC12/Z768-ND/87821 | RELAY GEN PURPOSE DPDT 2A 12V | PB1125-ND | Signal Relays, Up to 2 Amps |  |  |  |  | G5V-2-DC12 | Omron Electronics Inc-EMC Div |  | Active
29 | 1 | K4 | L3_HOLD | 1d_coinctrl_r2-rescue:G5V-2-DC12-dk_Signal-Relays-Up-to-2-Amps | digikey-footprints:Relay_THT_G5V-2 | http://omronfs.omron.com/en_US/ecb/products/pdf/en-g5v_2.pdf | Relays | http://omronfs.omron.com/en_US/ecb/products/pdf/en-g5v_2.pdf | /product-detail/en/omron-electronics-inc-emc-div/G5V-2-DC12/Z768-ND/87821 | RELAY GEN PURPOSE DPDT 2A 12V | PB1125-ND | Signal Relays, Up to 2 Amps |  |  |  |  | G5V-2-DC12 | Omron Electronics Inc-EMC Div |  | Active
30 | 1 | K5 | L2_COIN_CTRL | 1d_coinctrl_r2-rescue:G5V-2-DC12-dk_Signal-Relays-Up-to-2-Amps | digikey-footprints:Relay_THT_G5V-2 | http://omronfs.omron.com/en_US/ecb/products/pdf/en-g5v_2.pdf | Relays | http://omronfs.omron.com/en_US/ecb/products/pdf/en-g5v_2.pdf | /product-detail/en/omron-electronics-inc-emc-div/G5V-2-DC12/Z768-ND/87821 | RELAY GEN PURPOSE DPDT 2A 12V | PB1125-ND | Signal Relays, Up to 2 Amps |  |  |  |  | G5V-2-DC12 | Omron Electronics Inc-EMC Div |  | Active
31 | 1 | K6 | L2_HOLD | 1d_coinctrl_r2-rescue:G5V-2-DC12-dk_Signal-Relays-Up-to-2-Amps | digikey-footprints:Relay_THT_G5V-2 | http://omronfs.omron.com/en_US/ecb/products/pdf/en-g5v_2.pdf | Relays | http://omronfs.omron.com/en_US/ecb/products/pdf/en-g5v_2.pdf | /product-detail/en/omron-electronics-inc-emc-div/G5V-2-DC12/Z768-ND/87821 | RELAY GEN PURPOSE DPDT 2A 12V | PB1125-ND | Signal Relays, Up to 2 Amps |  |  |  |  | G5V-2-DC12 | Omron Electronics Inc-EMC Div |  | Active
32 | 1 | K7 | L1_COIN_CTRL | 1d_coinctrl_r2-rescue:G5V-2-DC12-dk_Signal-Relays-Up-to-2-Amps | digikey-footprints:Relay_THT_G5V-2 | http://omronfs.omron.com/en_US/ecb/products/pdf/en-g5v_2.pdf | Relays | http://omronfs.omron.com/en_US/ecb/products/pdf/en-g5v_2.pdf | /product-detail/en/omron-electronics-inc-emc-div/G5V-2-DC12/Z768-ND/87821 | RELAY GEN PURPOSE DPDT 2A 12V | PB1125-ND | Signal Relays, Up to 2 Amps |  |  |  |  | G5V-2-DC12 | Omron Electronics Inc-EMC Div |  | Active
33 | 3 | K8, K10, K11 | G5V-2-DC12 | 1d_coinctrl_r2-rescue:G5V-2-DC12-dk_Signal-Relays-Up-to-2-Amps | digikey-footprints:Relay_THT_G5V-2 | http://omronfs.omron.com/en_US/ecb/products/pdf/en-g5v_2.pdf | Relays | http://omronfs.omron.com/en_US/ecb/products/pdf/en-g5v_2.pdf | /product-detail/en/omron-electronics-inc-emc-div/G5V-2-DC12/Z768-ND/87821 | RELAY GEN PURPOSE DPDT 2A 12V | PB1125-ND | Signal Relays, Up to 2 Amps |  |  |  |  | G5V-2-DC12 | Omron Electronics Inc-EMC Div |  | Active
34 | 1 | K9 | L1_HOLD | 1d_coinctrl_r2-rescue:G5V-2-DC12-dk_Signal-Relays-Up-to-2-Amps | digikey-footprints:Relay_THT_G5V-2 | http://omronfs.omron.com/en_US/ecb/products/pdf/en-g5v_2.pdf | Relays | http://omronfs.omron.com/en_US/ecb/products/pdf/en-g5v_2.pdf | /product-detail/en/omron-electronics-inc-emc-div/G5V-2-DC12/Z768-ND/87821 | RELAY GEN PURPOSE DPDT 2A 12V | PB1125-ND | Signal Relays, Up to 2 Amps |  |  |  |  | G5V-2-DC12 | Omron Electronics Inc-EMC Div |  | Active
35 | 1 | PS1 | IA1224S | 1d_coinctrl_r2-rescue:IA1224S-dk_DC-DC-Converters | 1dcoinctrl_r2:IA1224S | https://www.cui.com/product/resource/digikeypdf/v78-500.pdf | Power Supplies - Board Mount | https://www.cui.com/product/resource/digikeypdf/v78-500.pdf | /product-detail/en/cui-inc/V7805-500/102-1709-ND/1828602 | DC DC CONVERTER 5V 2.5W | 102-1709-ND | DC DC Converters |  |  |  |  | V7805-500 | CUI Inc. |  | Active
36 | 1 | PS2 | R12-100B | 1d_coinctrl_r2-rescue:R12-100B-R12-100B | kicad-snapeda:CONV_R12-100B | 7 |  |  |  |  |  |  | Recom | 9.4mm | Manufacturer Recommendations
37 | 1 | R1 | 1M | Device:R_US | Resistor_THT:R_Axial_DIN0207_L6.3mm_D2.5mm_P7.62mm_Horizontal | ~
38 | 1 | R2 | 10K | Device:R_US | Resistor_THT:R_Axial_DIN0207_L6.3mm_D2.5mm_P7.62mm_Horizontal | ~
39 | 4 | R3, R6, R10, R15 | 120 2W | Device:R_US | Resistor_THT:R_Axial_DIN0516_L15.5mm_D5.0mm_P20.32mm_Horizontal | ~
40 | 6 | R4, R5, R7, R8, R9, R17 | 220 | Device:R_US | Resistor_THT:R_Axial_DIN0207_L6.3mm_D2.5mm_P7.62mm_Horizontal | ~
41 | 4 | R11, R12, R13, R14 | 120 | Device:R_US | Resistor_THT:R_Axial_DIN0207_L6.3mm_D2.5mm_P7.62mm_Horizontal | ~
42 | 1 | R16 | 1.5K 5W | Device:R_US | Resistor_THT:R_Axial_Power_L25.0mm_W9.0mm_P30.48mm | ~
43 | 3 | R18, R20, R21 | 1.5K 1W | Device:R_US | Resistor_THT:R_Axial_DIN0207_L6.3mm_D2.5mm_P10.16mm_Horizontal | ~
44 | 1 | R19 | 5K | Device:R_Potentiometer_US | Potentiometer_THT:Potentiometer_Bourns_3266W_Vertical | ~
45 | 1 | SW1 | SW_Push | Switch:SW_Push | Button_Switch_THT:SW_PUSH_6mm | ~
46 | 1 | U1 | MAX202 | Interface_UART:MAX202 | Package_DIP:DIP-16_W7.62mm | http://www.ti.com/lit/ds/symlink/max202.pdf
47 | 1 | U2 | PIC18F47Q84-IP | MCU_Microchip_PIC18:PIC18F4550-IP | Package_DIP:DIP-40_W15.24mm | http://ww1.microchip.com/downloads/en/DeviceDoc/39760d.pdf
48 | 2 | U3, U4 | 74LS06 | 74xx:74LS06 | Package_DIP:DIP-14_W7.62mm | http://www.ti.com/lit/gpn/sn74LS06
49 | 5 | U5, U6, U7, U8, U9 | ILD74 | Isolator:ILD74 | Package_DIP:DIP-8_W7.62mm_Socket | https://www.vishay.com/docs/83640/ild74.pdf
50 | 1 | U10 | V7805-1000 | 1d_coinctrl_r2-rescue:V7805-1000-dk_DC-DC-Converters | digikey-footprints:3-SIP_Module_V7805-1000 | https://www.cui.com/product/resource/digikeypdf/v78xx-1000.pdf | Power Supplies - Board Mount | https://www.cui.com/product/resource/digikeypdf/v78xx-1000.pdf | /product-detail/en/cui-inc/V7805-1000/102-1715-ND/1828608 | DC DC CONVERTER 5V 5W | 102-1715-ND | DC DC Converters |  |  |  |  | V7805-1000 | CUI Inc. |  | Active

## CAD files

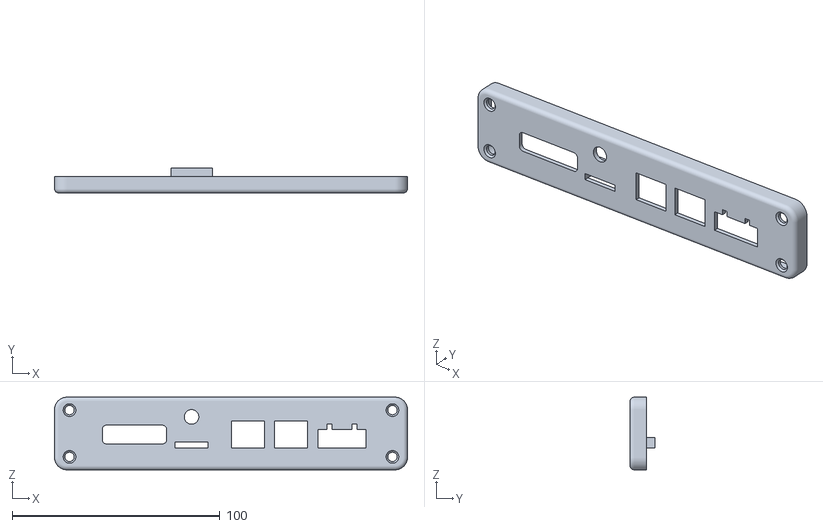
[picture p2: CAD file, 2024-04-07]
enclosure/Hammond_160mm_Extrusion_Rear_Panel.stl
170.0 x 12.0 x 35.0

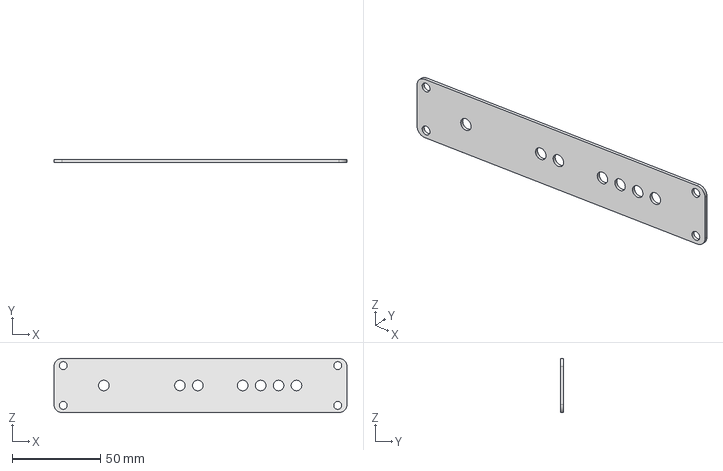
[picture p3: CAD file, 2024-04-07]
enclosure/Hammond_End_Panel.FCStd
166.0 x 1.50 x 30.6 mm

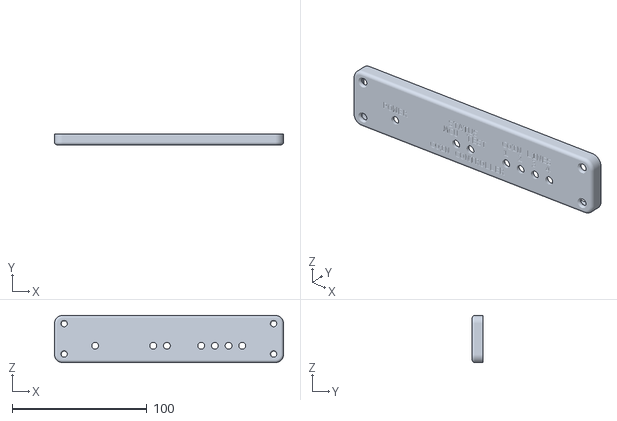
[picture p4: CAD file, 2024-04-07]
enclosure/Hammond_160mm_Extrusion_Front_Panel.stl
170.0 x 8.00 x 35.0

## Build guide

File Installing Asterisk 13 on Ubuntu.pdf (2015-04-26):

# Installing Asterisk 13 from source (Ubuntu 15.04)

## Prerequisites

Install Ubuntu 15.04 LTS

If unstalling on a virtual machine, make sure the network adapter is configured in “Bridged” mode.

Enable SSH remote access into your Ubuntu system:
sudo aptget install opensshserver

## Build and Install iksemel (if you want to support Google Voice)

### Prerequisites for iksemel

iksemel requires the gnutlsdev package.
sudo aptget install libgnutlsdev

gnutlsconfig is no longer distributed with Ubuntu, but you can make one as follows (reference: https://code.google.com/p/iksemel/issues/detail?id=29):

sudo cat > /usr/bin/libgnutlsconfig
#!/bin/bash

if [ "$1" == "version" ]; then pkgconfig modversion gnutls else
pkgconfig $1 gnutls
fi
^D
sudo chmod 755 /usr/bin/libgnutlsconfig

### Download and install iksemel

sudo wget https://iksemel.googlecode.com/files/iksemel-1.4.tar.gz sudo tar xfvz iksemel-1.4.tar.gz
cd iksemel-1.4/
./configure
make
sudo make install

## Build and Install pjsip

Download pjsip v2.4:
http://www.pjsip.org/download.htm

./configure prefix=/usr enableshared disablesound disableresample disablevideo disableopencoreamr CFLAGS='-O2 -DNDEBUG'
make dep
make
sudo make install
sudo ldconfig
sudo ldconfig p|grep pj

## Build and Install jansson

git clone https://github.com/akheron/jansson.git autoreconf i
cd jansson/
autoreconf i
./configure
make
sudo make install

## Build and Install Asterisk 13:

Download Asterisk 13
http://www.asterisk.org/downloads/asterisk/allasteriskversions

tar xfvz ~/Downloads/asterisk-13-current.tar.gz cd asterisk-13.3.2/
sudo aptget install uuiddev
sudo aptget install libjanssondev
sudo aptget install libncursesdev sudo aptget install libxml2-dev sudo aptget install libsqlite3-dev sudo aptget install subversion
./configure
make menuselect (Note: If you want MP3 support, you need to manually turn on 'format_mp3' on the first page)
contrib/scripts/get_mp3_source.sh
make
sudo make install
sudo make samples
sudo make config
sudo make installlogrotate

## Install Extra Sounds

cd /var/lib/asterisk/sounds
sudo wget http://downloads.asterisk.org/pub/telephony/sounds/asteriskextrasoundsenwavcurrent.tar.gz sudo tar xfz asteriskextrasoundsenwavcurrent.tar.gz
sudo rm f asteriskextrasoundsenwavcurrent.tar.gz
# Wideband Audio download

sudo wget http://downloads.asterisk.org/pub/telephony/sounds/asteriskextrasoundseng722-current.tar.gz sudo tar xfz asteriskextrasoundseng722-current.tar.gz
sudo rm f asteriskextrasoundseng722-current.tar.gz

Configure
http://<server_ip>:<bindport>/static/docs/index.html sudo vi /etc/asterisk/http.conf
sudo /etc/init.d/asterisk status
sudo asterisk r

Build and Install FreePBX: http://wiki.freepbx.org/display/HTGS/Installing+FreePBX+12+on+Ubuntu+Server+14.04+LTS

sudo aptget install y buildessential linuxheaders`uname r` opensshserver apache2 mysqlserver\
mysqlclient bison flex php5 php5-curl php5-cli php5-mysql phppear phpdb php5-gd curl sox\ libncurses5-dev libssldev libmysqlclientdev mpg123 libxml2-dev libnewtdev sqlite3\ libsqlite3-dev pkgconfig automake libtool autoconf git subversion unixodbcdev uuid uuiddev\
libasound2-dev liboggdev libvorbisdev libcurl4-openssldev libicaldev libneon27-dev libsrtp0-dev\
libspandspdev libiksemeldev libiksemelutils libiksemel3

Set password for mysql server root user.

sudo wget http://mirror.freepbx.org/freepbx-12.0.43.tgz sudo tar vxfz freepbx-12.0.43.tgz

sudo i
useradd m asterisk
chown asterisk. /var/run/asterisk
chown -R asterisk. /etc/asterisk
chown -R asterisk. /var/{lib,log,spool}/asterisk chown -R asterisk. /usr/lib/asterisk
rm rf /var/www/html

sed i 's/\(^upload_max_filesize = \).*/\120M/' /etc/php5/apache2/php.ini cp /etc/apache2/apache2.conf /etc/apache2/apache2.conf_orig
sed i 's/^\(User\|Group\).*/\1 asterisk/' /etc/apache2/apache2.conf
service apache2 restart
export ASTERISK_DB_PW=`dd if=/dev/urandom bs=1 count=32 2>/dev/null | base64 | cut
c2-18`
mysqladmin p u root create asterisk
mysqladmin p u root create asteriskcdrdb
mysql p u root e "GRANT ALL PRIVILEGES ON asterisk.* TO asteriskuser@localhost IDENTIFIED BY '${ASTERISK_DB_PW}';"
mysql p u root e "GRANT ALL PRIVILEGES ON asteriskcdrdb.* TO asteriskuser@localhost IDENTIFIED BY '${ASTERISK_DB_PW}';"
mysql p u root e "flush privileges;"

./start_asterisk start
./install_amp installdb username=asteriskuser password=${ASTERISK_DB_PW} amportal chown
amportal a ma installall
amportal a reload
amportal a ma refreshsignatures amportal chown

## Ubuntu Firewall Configuration

sudo ufw allow 5060/tcp
sudo ufw allow 5060/udp
sudo ufw allow 5061/tcp
sudo ufw allow 5061/udp

## Custom Extensions

### Map 555-xxxx, etc to PBX extensions 6xxx

:/etc/asterisk# cat extensions_custom.conf [voicemenuanac-1]
exten = s,1,NoOp(ANI)
exten = s,2,Answer()
exten = s,3,Wait(1)
exten = s,4,SayDigits(555)
exten = s,5,SayDigits(${CALLERID(num)}) exten = s,6,Wait(5)
exten = s,7,SayDigits(555)
exten = s,8,SayDigits(${CALLERID(num)}) exten = s,9,Wait(5)
exten = s,10,Busy()

[frominternalcustom]
exten = _92555599XX,1,Goto(default,60${EXTEN:8},1) exten = _192555599XX,1,Goto(default,60${EXTEN:9},1) exten = _55599XX,1,Goto(default,60${EXTEN:5},1) exten = _925555XXXX,1,Goto(default,${EXTEN:6},1) exten = _1925555XXXX,1,Goto(default,${EXTEN:7},1) exten = _555XXXX,1,Goto(default,${EXTEN:3},1) exten = 9581111,1,Goto(voicemenuanac-1,s,1) exten = 7958,1,Goto(voicemenuanac-1,s,1)
exten = 958,1,Goto(voicemenuanac-1,s,1)

## Securing Asterisk and FreePBX

1. Enable .htaccess: http://wiki.freepbx.org/display/F2/Webserver+Overrides
2. Change Asterisk Manager password (FreePBX->Settings>Advanced)

## Protect your System

### Install fail2ban

sudo aptget install fail2ban https://www.digitalocean.com/community/tutorials/howtoinstallandusefail2banonubuntu-1 4-04 (https://www.digitalocean.com/community/tutorials/how-to-install-and-use-fail2ban-on-ubuntu-14-04)

Install email server and client for Fail2Ban:
sudo aptget install sendmail
sudo aptget install mailutils

Check to make sure fail2ban is working properly:
In one terminal: sudo tail f /var/log/fail2ban.log In another: sudo fail2banclient reload

## Sendmail through gmail

http://linuxconfig.org/configuringgmailassendmailemailrelay (http://linuxconfig.org/configuring-gmail-as-sendmail-email-relay)

## Google Voice Setup

Install Motif module from FreePBX Admin page:
Module Admin, select the “Unsupported” repository and scroll down to install “Google Voice/Chan Motif” from the “Connectivity” section.

### Enable Less Secure Apps

https://www.google.com/settings/u/1/security/lesssecureapps

Make sure you have a Google Voice number associated with your Google Voice account. If you don’t, the caller ID will come up as “GOOGLE,GUY”

## Setting up Asterisk to Work with ACTS Payphones

Common Bell System payphones are of the Automated Coin Toll Service (ACTS) type, and require a special coin line in order for the phone to collect money. Joshua Stein created an interesting project on GitHub by jcs that allows Asterisk to recognize the coin tones. https://github.com/jcs/payphone. I started my own project to add full coin control using a hardware interface between Asterisk and the payphone: https://github.com/hharte/1dcoinctrl

### Install Asterisk-perl

Asteriskperl 1.03 is needed by the AGI scripts in order to support Perl. Information about Asteriskperl can be found here: http://asterisk.gnuinter.net/

Install as follows:
wget http://asterisk.gnuinter.net/files/asteriskperl-1.03.tar.gz tar xfvz asteriskperl-1.03.tar.gz
cd asteriskperl-1.03/
perl Makefile.PL
make all
sudo make install

### Modifying Asterisk to Recognize Coin Tones

Patch per:
https://github.com/hharte/1dcoinctrl/blob/master/asterisk/main/dsp.cpatch

Then rebuild Asterisk:
make
sudo make install
sudo service asterisk restart

### Installing Payphone AGI Script

git clone https://github.com/hharte/1dcoinctrl
cd 1dcoinctrl
sudo cp asterisk/agibin/payphone.agi /var/lib/asterisk/agibin sudo cp asterisk/agibin/invalid_number.sln /var/lib/asterisk/agibin sudo cp asterisk/agibin/not_deposited.sln /var/lib/asterisk/agibin sudo cp asterisk/sounds/* /var/lib/asterisk/agibin/
sudo chown asterisk.asterisk /var/lib/asterisk/agibin/payphone.agi sudo chown asterisk.asterisk /var/lib/asterisk/agibin/invalid_number.sln
sudo chown asterisk.asterisk /var/lib/asterisk/agibin/not_deposited.sln
sudo chmod 744 /var/lib/asterisk/agibin/payphone.agi
sudo chown asterisk.asterisk /var/lib/asterisk/agibin/*.wav

in /etc/asterisk/extensions_custom.conf:
[payphonetotalizer]
exten => 6200,1,Answer
exten => 6200,2,AGI(payphone.agi) exten => 6200,3,Hangup

#include pjsip.endpoint_custom.conf

[6001]
type=endpoint
aors=6001
auth=6001-auth
disallow=all
allow=ulaw,alaw
dtmf_mode=inband
context=payphonetotalizer callerid=device <6001>
mailboxes=6001@device
use_avpf=no
ice_support=no
media_use_received_transport=no trust_id_inbound=yes
rtp_symmetric=yes
rewrite_contact=yes

### Coin Collect / Refund Controller Interface

In order to actually collect and refund coins deposited into the coin hopper, a hardware interface is required to supply +130VDC and -130VDC to the coin relay at the appropriate times.

1D Coin Controller Project
https://github.com/hharte/1dcoinctrl

Coin Control details:

+/-130VDC minimum 41mA (Collect/Refund)
+/-48VDC maximum 20mA (Stuck Coin/Initial Rate Tests)

+48VDC also for 5c overtime test (same as stuck coin test.)

Coin Relay operate pulse is 600ms.
After coin control function is complete, the system will make one recycle attempt if coin ground (stuck coin test) is still present.

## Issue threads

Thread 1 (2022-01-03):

typographical error on board

MadManMarkAu, 2022-01-03:
"REFUND DISPOSITIION" has a doubled "I".
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

hharte, 2022-08-06:
Thank you, fixed in the iss2 branch.

Closed 2022-08-06.

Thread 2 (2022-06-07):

Anyone have a Mouser/Digikey parts list for this?

timmerk, 2022-06-07:
I didn't see a parts list in the hardware folder, but if anyone can share a Mouser/Digikey parts list, I'd appreciate it!

rpk2012, 2022-09-27:
Same, looking for more information on this as well.

rpk2012, 2022-09-27:
Just saw it, 1d_coinctrl_r2.csv has it

timmerk, 2022-09-27:
> Just saw it, 1d_coinctrl_r2.csv has it

Thank you!

hharte, 2024-03-24:
For issue 4, there is an interactive BOM, and a fairly complete Digi-Key parts list: https://github.com/hharte/1dcoinctrl/tree/main?tab=readme-ov-file#components

timmerk, 2024-03-24:
Thank you, this is great!

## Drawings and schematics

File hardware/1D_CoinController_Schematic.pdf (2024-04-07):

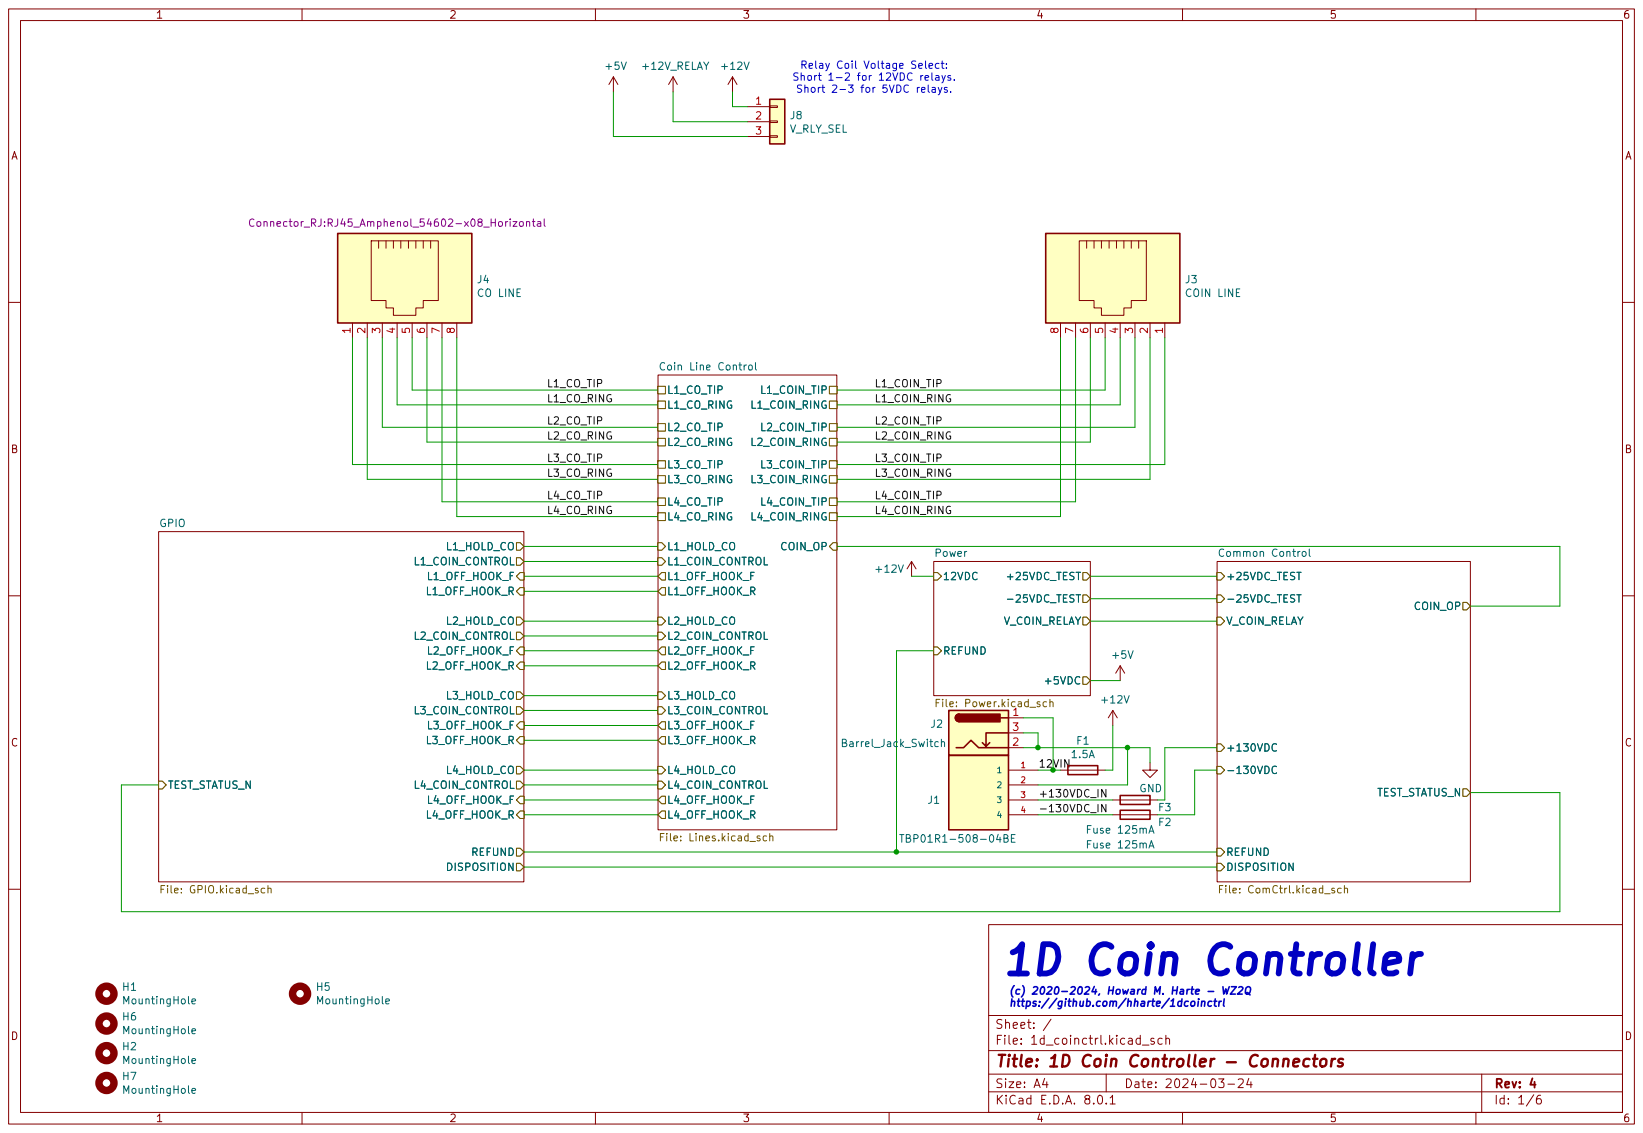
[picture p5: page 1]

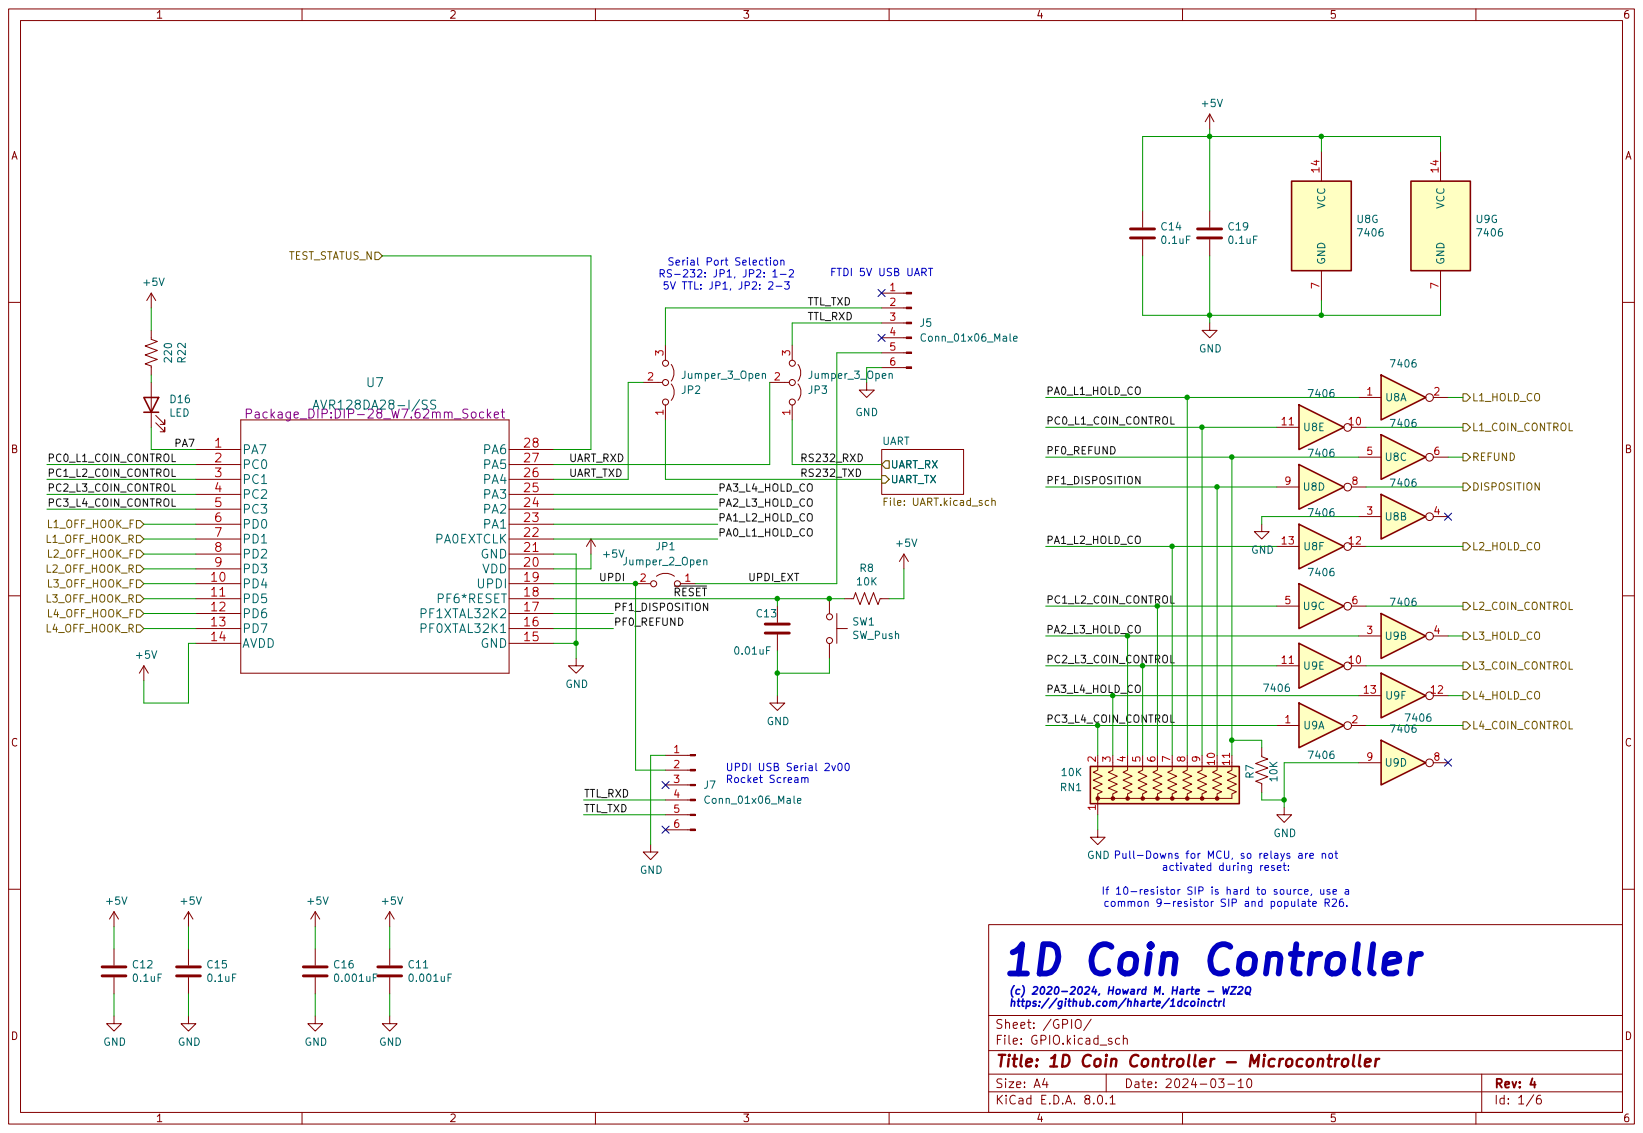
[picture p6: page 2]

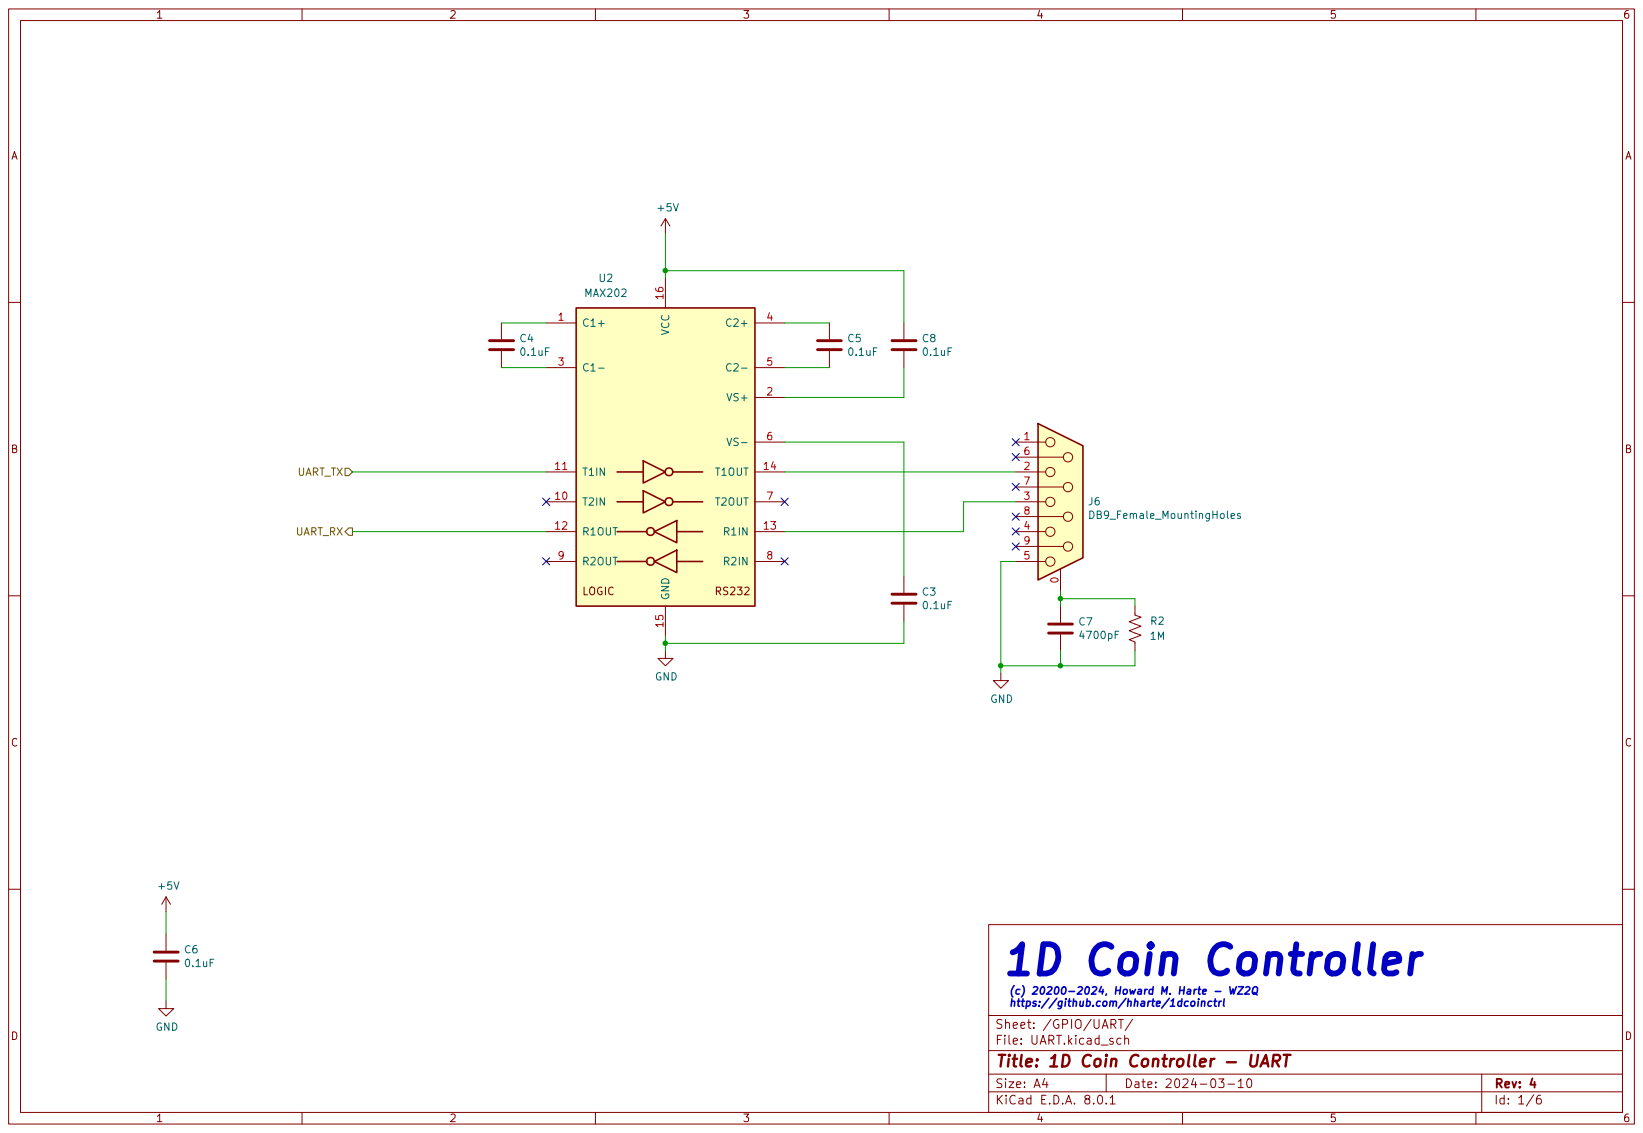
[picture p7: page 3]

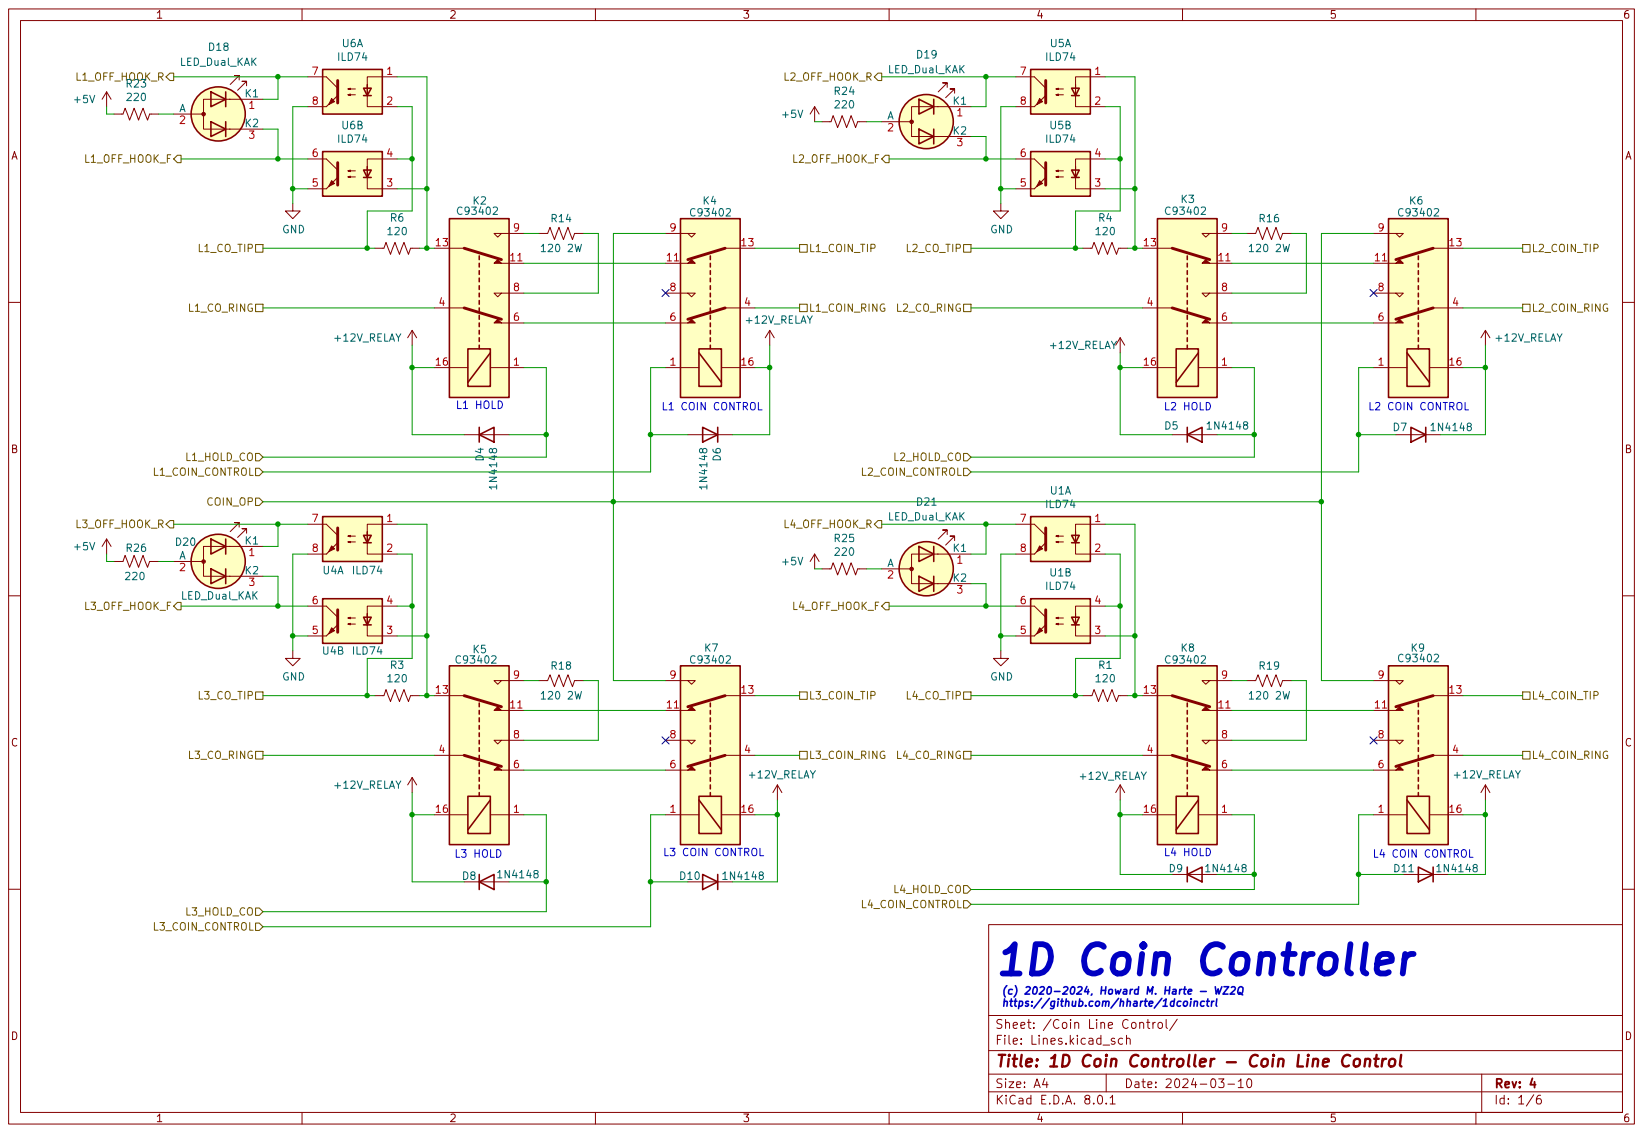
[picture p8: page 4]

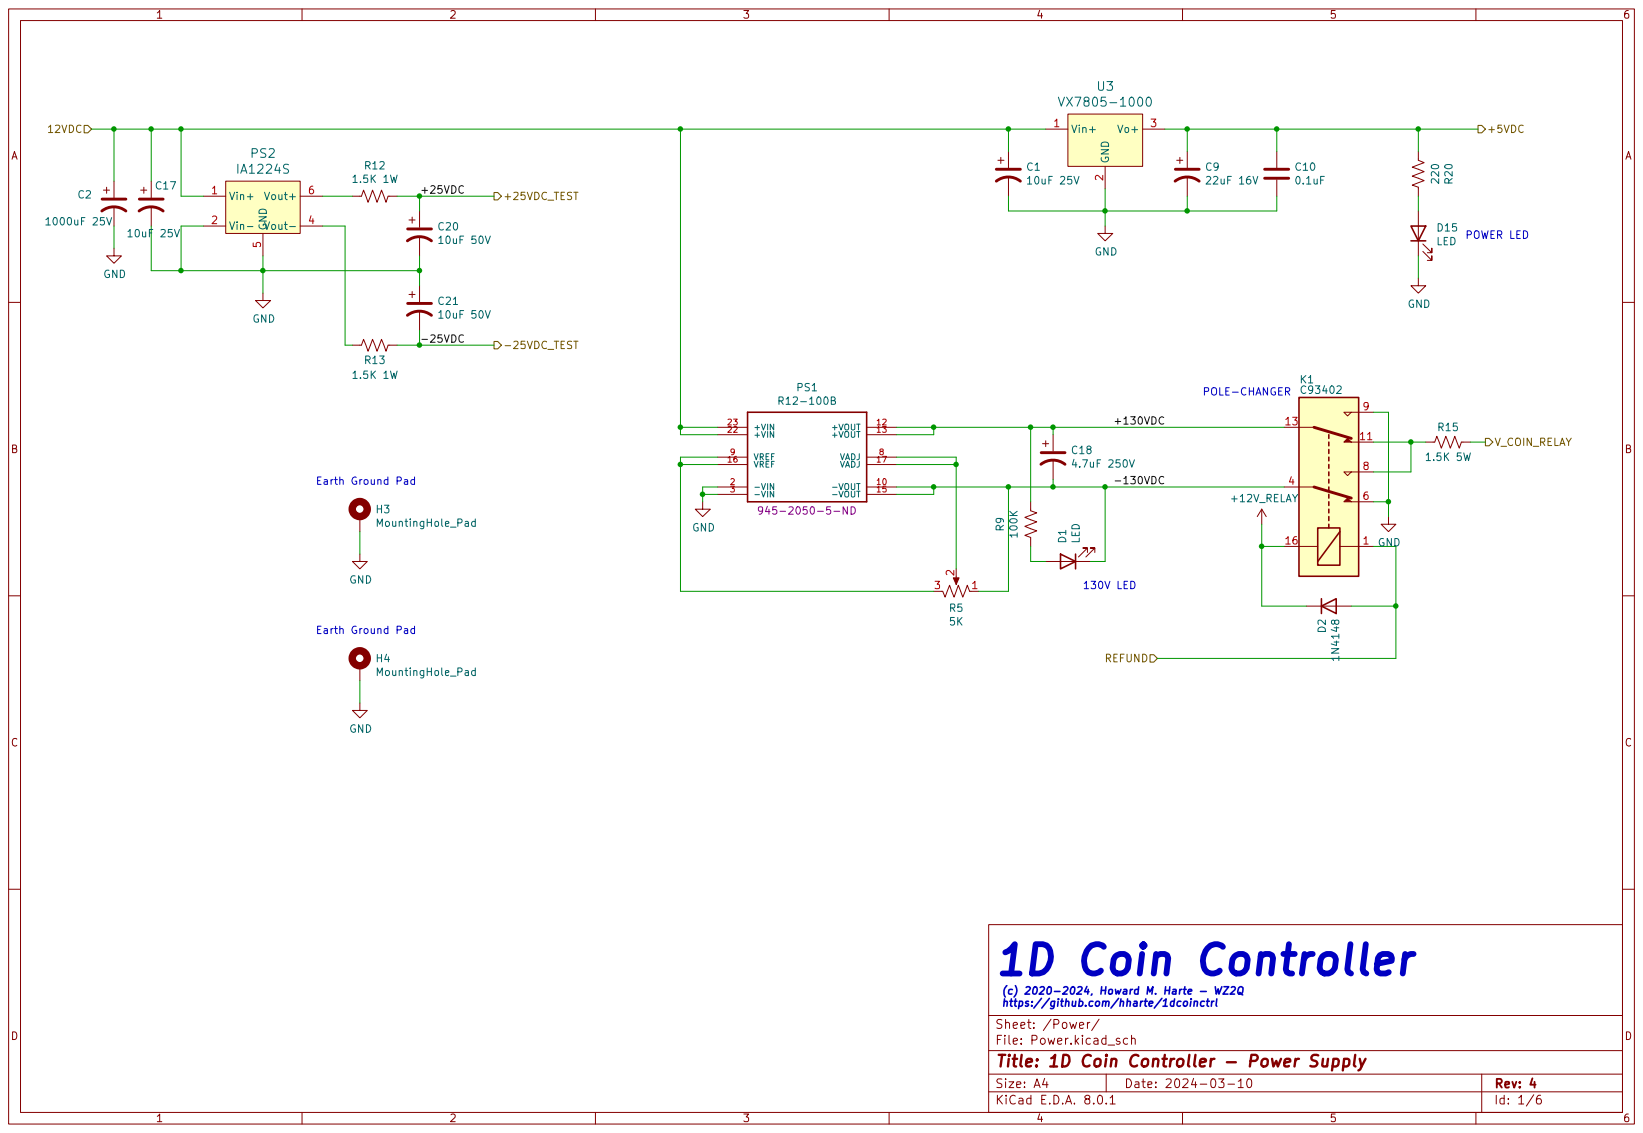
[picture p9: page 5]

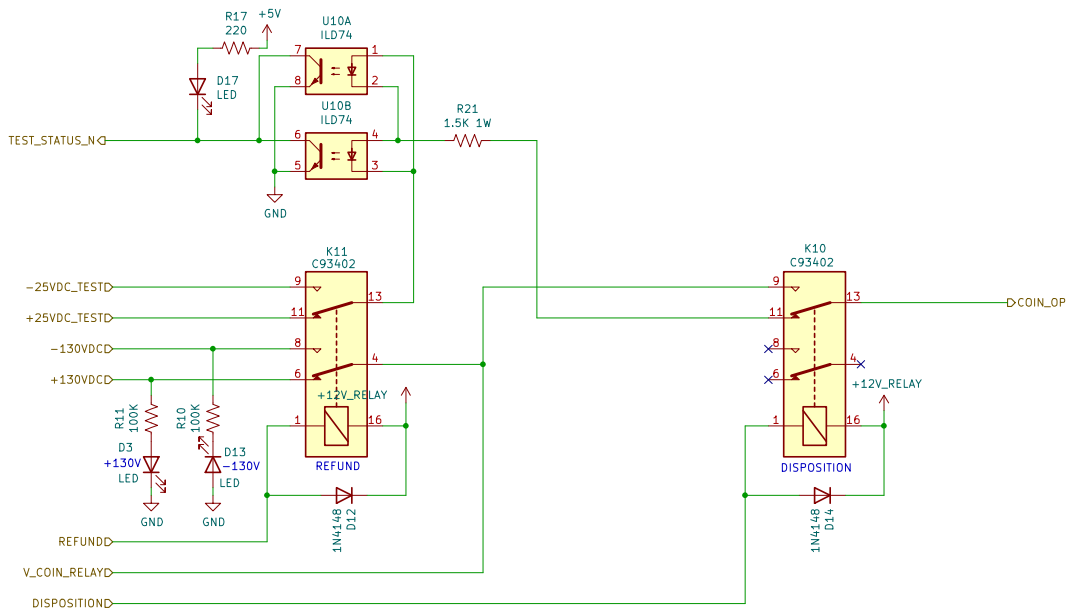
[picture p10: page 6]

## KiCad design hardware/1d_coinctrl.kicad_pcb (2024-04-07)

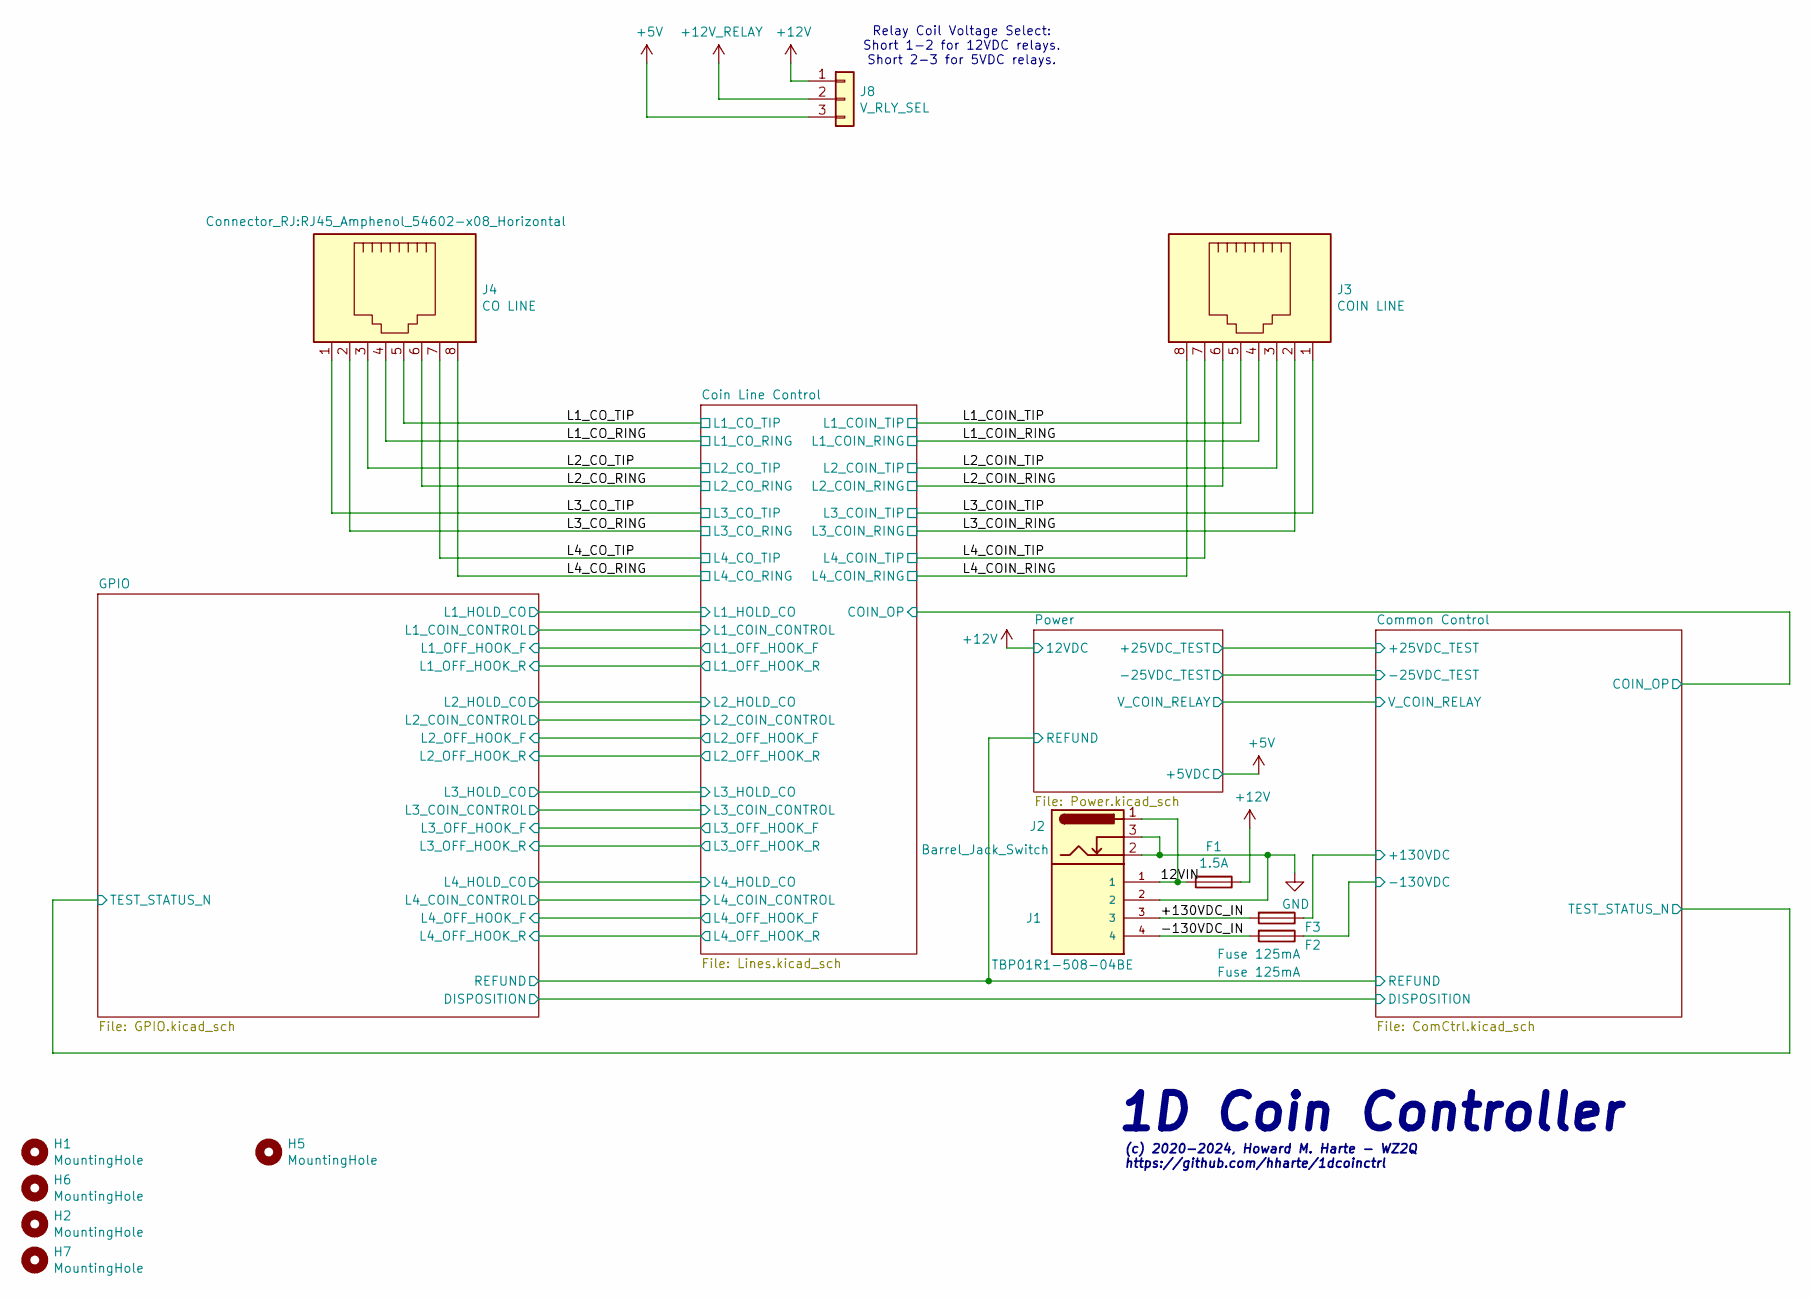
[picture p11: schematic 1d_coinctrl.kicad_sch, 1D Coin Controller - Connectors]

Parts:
F1: 1.5A; R_Axial_DIN0207_L6.3mm_D2.5mm_P10.16mm_Horizontal; MPN 025101.5MXL; Digi-Key_PN F2319-ND
F2, F3: Fuse 125mA; R_Axial_DIN0207_L6.3mm_D2.5mm_P10.16mm_Horizontal; MPN 0251.125NAT1L; Digi-Key_PN F10763CT-ND
H1, H2, H5, H6, H7: MountingHole; MountingHole_3.7mm_Pad
J1: TBP01R1-508-04BE; CUI_TBP01R1-508-04BE; MPN TBP01R1-508-04BE; Digi-Key_PN 102-6408-ND
J2: Barrel_Jack_Switch; BarrelJack_Horizontal; MPN RAPC722BK
J3: COIN LINE; RJ45_Amphenol_54602-x08_Horizontal; MPN 54602-908LF; Digi-Key_PN 609-1046-ND
J4: CO LINE; RJ45_Amphenol_54602-x08_Horizontal; MPN 54602-908LF; Digi-Key_PN 609-1046-ND
J8: V_RLY_SEL; PinHeader_1x03_P2.54mm_Vertical

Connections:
+5V: J8.3; also elsewhere on the board
+12V: F1.1, J8.1; also elsewhere on the board
+12V_RELAY: J8.2; also elsewhere on the board
/12VIN: F1.2, J1.1, J2.1
/+130VDC_IN: F3.2, J1.3
/-130VDC_IN: F2.2, J1.4
/Common Control/+130VDC: F3.1; also elsewhere on the board
/Common Control/-130VDC: F2.1; also elsewhere on the board
/L1_COIN_RING: J3.4; also elsewhere on the board
/L1_COIN_TIP: J3.5; also elsewhere on the board
/L1_CO_RING: J4.4; also elsewhere on the board
/L1_CO_TIP: J4.5; also elsewhere on the board
/L2_COIN_RING: J3.6; also elsewhere on the board
/L2_COIN_TIP: J3.3; also elsewhere on the board
/L2_CO_RING: J4.6; also elsewhere on the board
/L2_CO_TIP: J4.3; also elsewhere on the board
/L3_COIN_RING: J3.2; also elsewhere on the board
/L3_COIN_TIP: J3.1; also elsewhere on the board
/L3_CO_RING: J4.2; also elsewhere on the board
/L3_CO_TIP: J4.1; also elsewhere on the board
/L4_COIN_RING: J3.8; also elsewhere on the board
/L4_COIN_TIP: J3.7; also elsewhere on the board
/L4_CO_RING: J4.8; also elsewhere on the board
/L4_CO_TIP: J4.7; also elsewhere on the board
GND: J1.2, J2.2, J2.3; also elsewhere on the board

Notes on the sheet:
(c) 2020-2024, Howard M. Harte - WZ2Q https://github.com/hharte/1dcoinctrl
Relay Coil Voltage Select: Short 1-2 for 12VDC relays. Short 2-3 for 5VDC relays.
1D Coin Controller

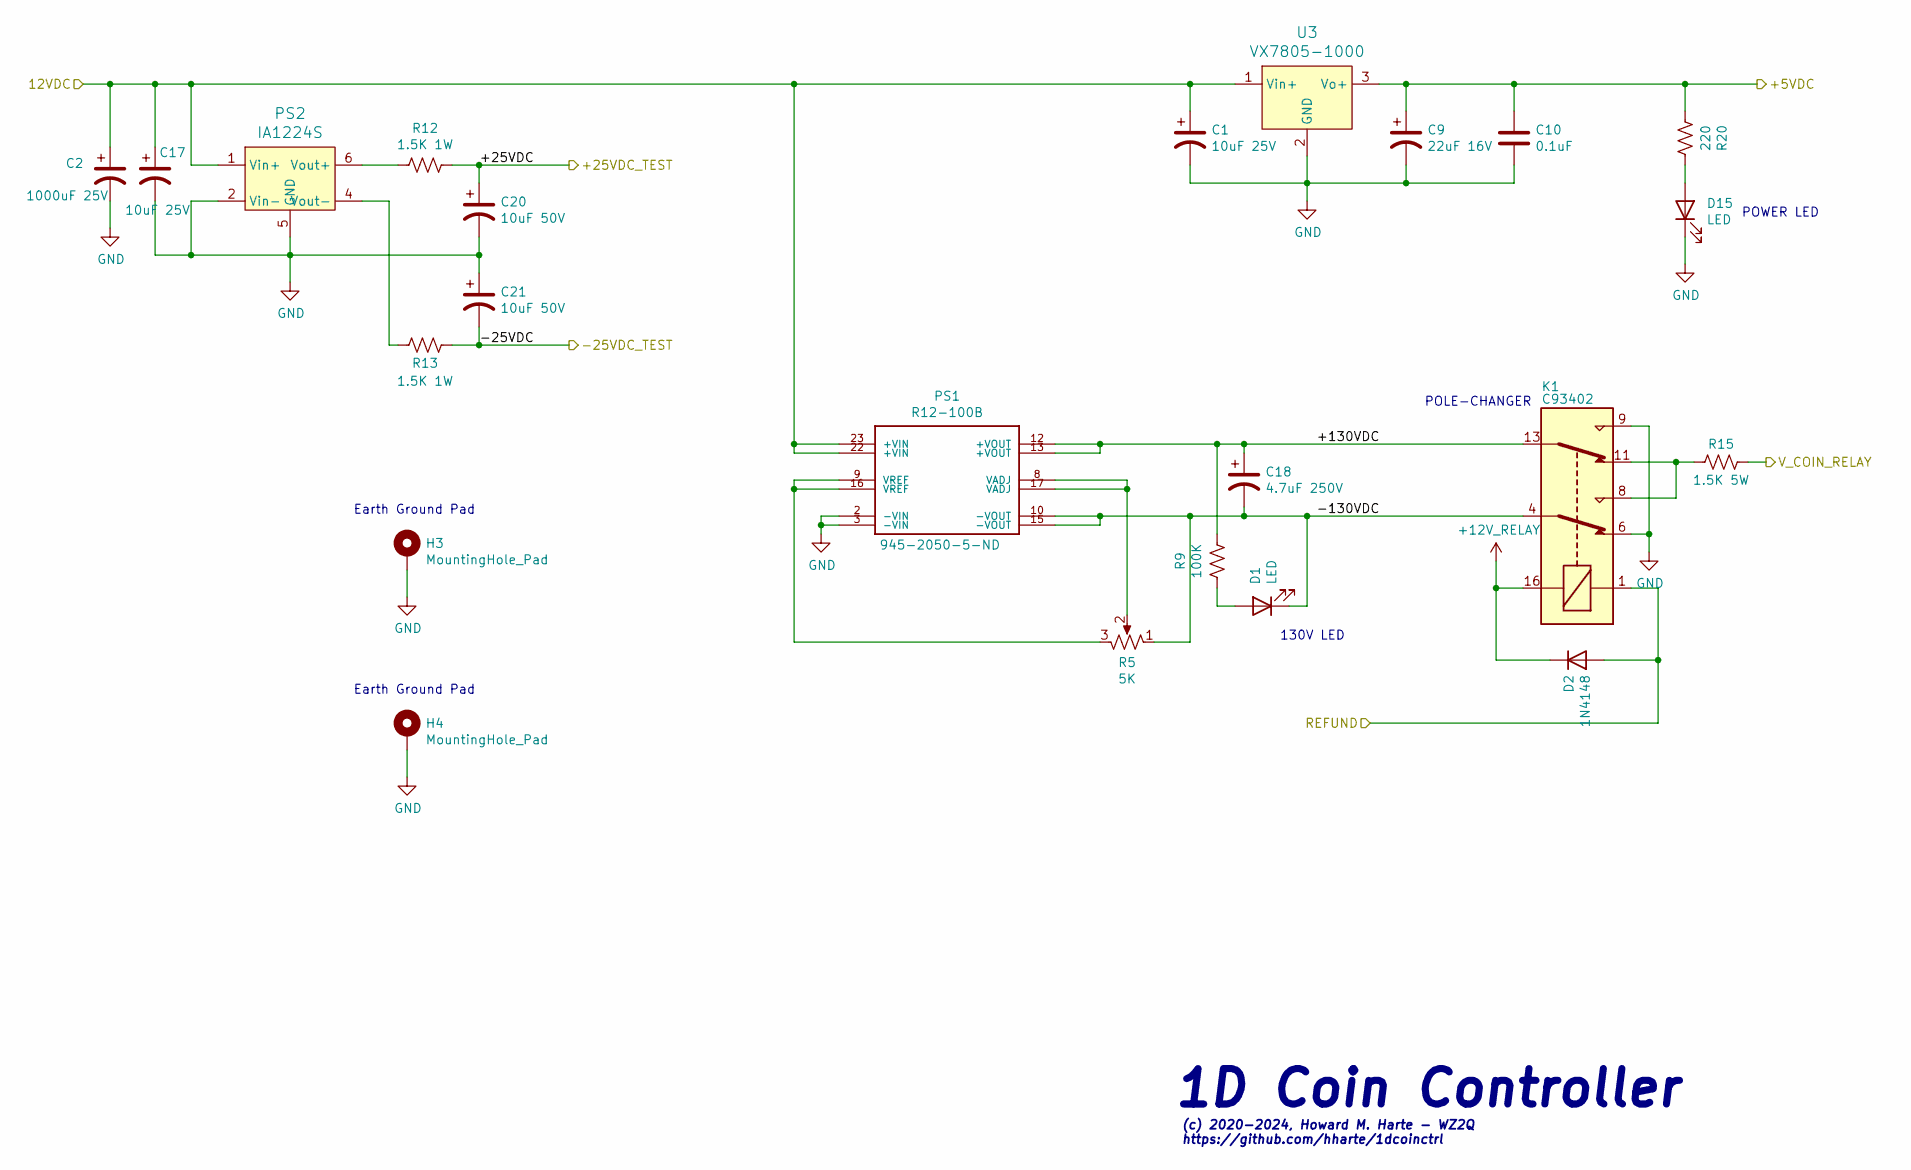
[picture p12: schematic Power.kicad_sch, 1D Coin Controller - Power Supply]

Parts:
C1, C17: 10uF 25V; C_Disc_D6.0mm_W4.4mm_P5.00mm; MPN FA26X7R1E106KRU06; Digi-Key_PN 445-180683-1-ND
C2: 1000uF 25V; CP_Radial_D12.5mm_P5.00mm; MPN ECA-1HHG102; Digi-Key_PN P5575-ND
C9: 22uF 16V; C_Disc_D6.0mm_W4.4mm_P5.00mm; MPN FK20X7R1C226MR000; Digi-Key_PN 445-FK20X7R1C226MR000-ND
C10: 0.1uF; C_Disc_D3.0mm_W2.0mm_P2.50mm; MPN K104M15X7RF5TL2; Digi-Key_PN 56-K104M15X7RF5TL2CT-ND
C18: 4.7uF 250V; CP_Radial_D8.0mm_P3.50mm; MPN SEK4R7M250ST; Digi-Key_PN 338-2361-ND
C20, C21: 10uF 50V; CP_Radial_D6.3mm_P2.50mm; MPN ECA-1JM100I; Digi-Key_PN P19534CT-ND
D1, D15: LED; LED_D5.0mm; MPN XLUR12D; Digi-Key_PN 1497-1031-ND
D2: 1N4148; D_DO-35_SOD27_P7.62mm_Horizontal; MPN 1N4148TA; Digi-Key_PN 1N4148TACT-ND
H3, H4: MountingHole_Pad; MountingHole_3.7mm_Pad
K1: C93402; Relay_DPDT_Omron_G5V-2; MPN C93402; Digi-Key_PN PB1125-ND
PS1: R12-100B; CONV_R12-100B; MPN R12-100B; Digi-Key_PN 945-2050-5-ND
PS2: IA1224S; MPN IA1224S; Digi-Key_PN 1470-1364-5-ND
R5: 5K; Potentiometer_Bourns_3266W_Vertical; MPN 64WR5KLF; Digi-Key_PN 987-1067-ND
R9: 100K; R_Axial_DIN0207_L6.3mm_D2.5mm_P7.62mm_Horizontal; MPN CFM12JT100K; Digi-Key_PN S100KHCT-ND
R12, R13: 1.5K 1W; R_Axial_DIN0207_L6.3mm_D2.5mm_P10.16mm_Horizontal; MPN PR01000101501JR500; Digi-Key_PN PPC1.5KW-1CT-ND
R15: 1.5K 5W; R_Axial_Power_L25.0mm_W9.0mm_P30.48mm; MPN EP5WS1K5J; Digi-Key_PN A131371CT-ND
R20: 220; R_Axial_DIN0207_L6.3mm_D2.5mm_P7.62mm_Horizontal; MPN CFM12JT220R; Digi-Key_PN S220HCT-ND
U3: VX7805-1000; MPN VX7805-1000; Digi-Key_PN 102-4253-ND

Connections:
+5V: C9.1, C10.1, R20.2, U3.3 (Vo+); also elsewhere on the board
+12V: C1.1, C2.1, C17.1, PS1.22 (+VIN), PS1.23 (+VIN), PS2.1 (Vin+), U3.1 (Vin+); also elsewhere on the board
+12V_RELAY: D2.1 (K), K1.16; also elsewhere on the board
/Common Control/REFUND: D2.2 (A), K1.1; also elsewhere on the board
/Common Control/V_COIN_RELAY: R15.1; also elsewhere on the board
/Power/+25VDC: C20.1, R12.1; also elsewhere on the board
/Power/+130VDC: C18.1, K1.13, PS1.12 (+VOUT), PS1.13 (+VOUT), R9.1
/Power/-25VDC: C21.2, R13.1; also elsewhere on the board
/Power/-130VDC: C18.2, D1.1 (K), K1.4, PS1.10 (-VOUT), PS1.15 (-VOUT), R5.1
GND: C1.2, C2.2, C9.2, C10.2, C17.2, C20.2, C21.1, D15.1 (K), H3.1, H4.1, K1.6, K1.9, PS1.2 (-VIN), PS1.3 (-VIN), PS2.2 (Vin-), PS2.5 (GND), U3.2 (GND); also elsewhere on the board
unnamed: D1.2 (A), R9.2
unnamed: D15.2 (A), R20.1
unnamed: K1.8, K1.11, R15.2
unnamed: PS1.8 (VADJ), PS1.17 (VADJ), R5.2
unnamed: PS1.9 (VREF), PS1.16 (VREF), R5.3
unnamed: PS2.6 (Vout+), R12.2
unnamed: PS2.4 (Vout-), R13.2

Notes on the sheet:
(c) 2020-2024, Howard M. Harte - WZ2Q https://github.com/hharte/1dcoinctrl
POLE-CHANGER
Earth Ground Pad
1D Coin Controller
130V LED
POWER LED

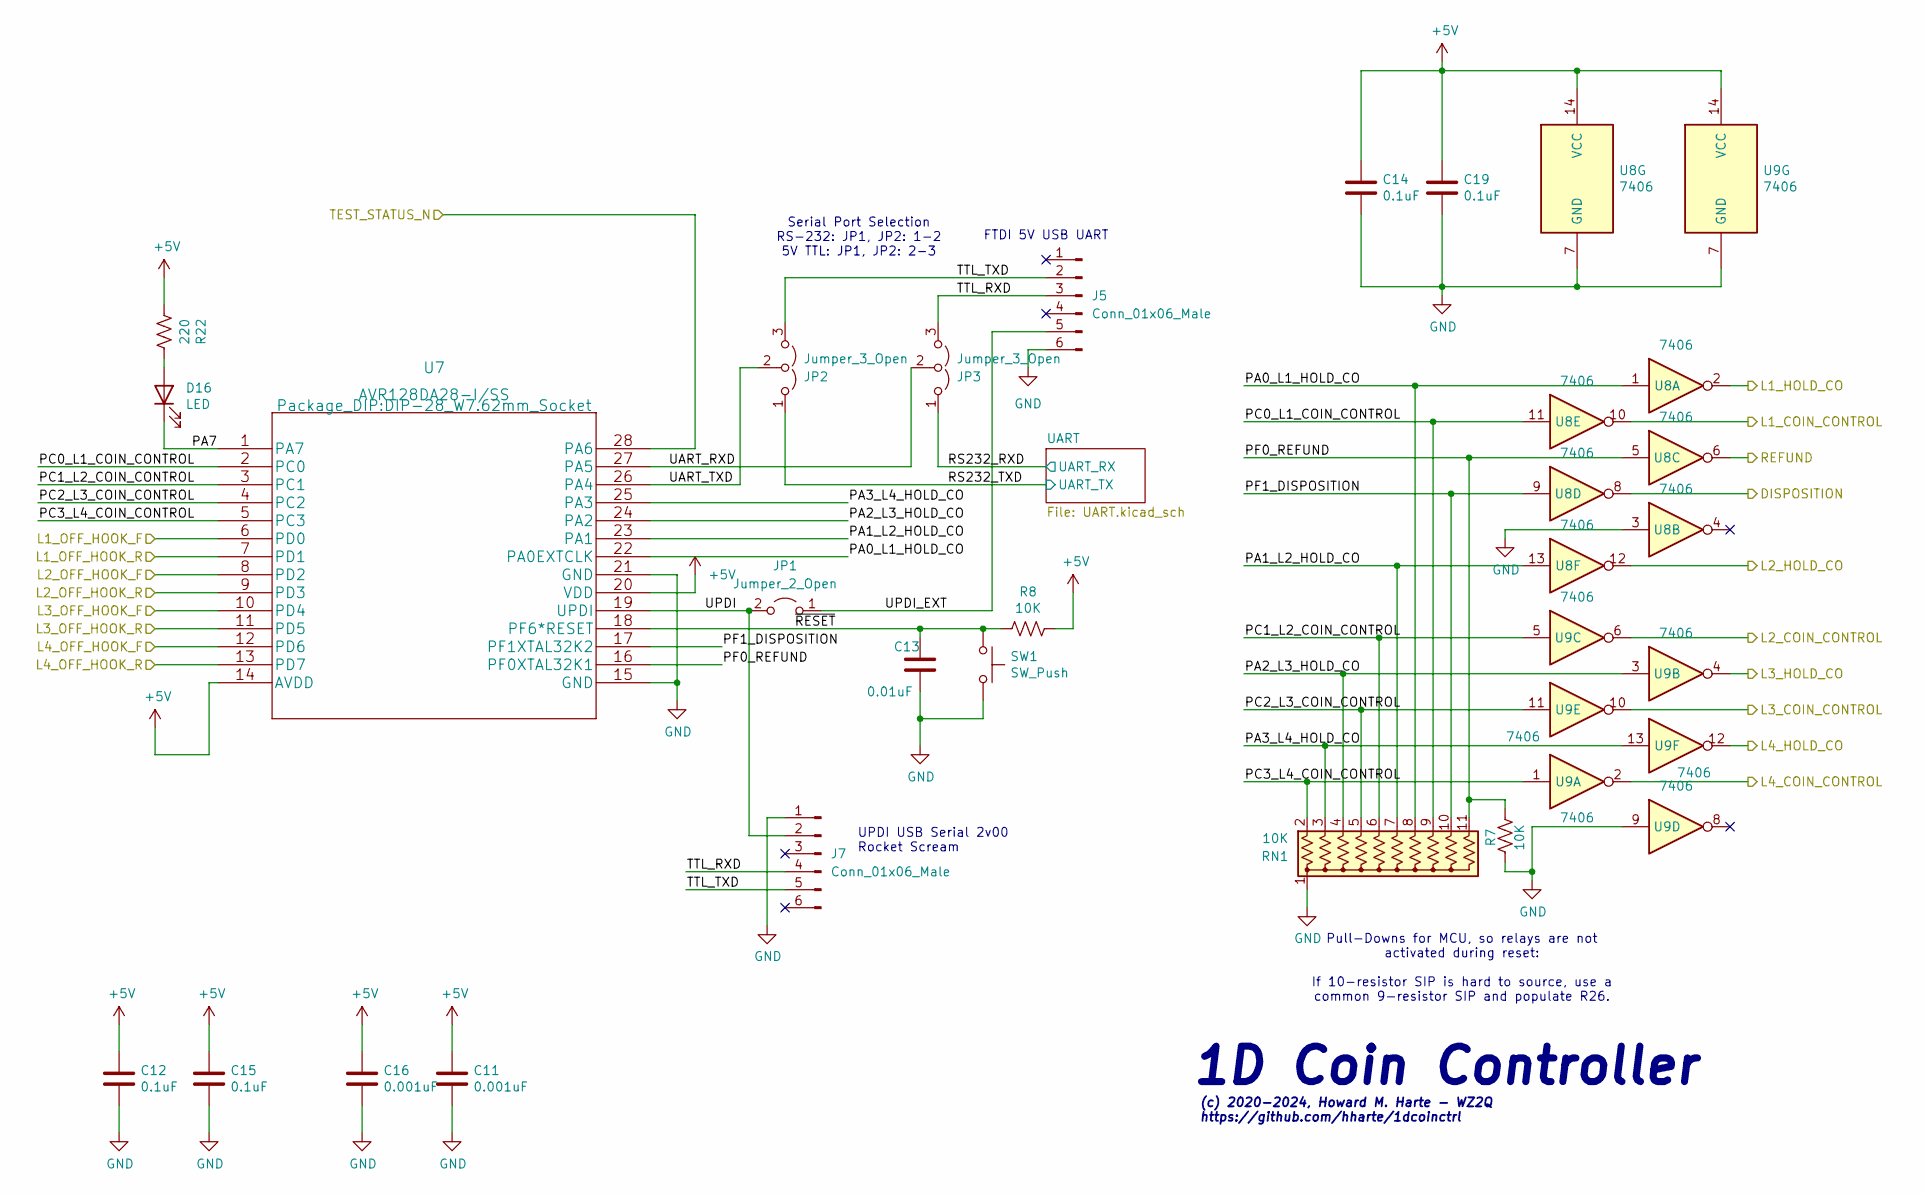
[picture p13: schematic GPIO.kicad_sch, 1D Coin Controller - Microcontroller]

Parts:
C11, C16: 0.001uF; C_Disc_D3.0mm_W2.0mm_P2.50mm; MPN K102M15X7RF5UL2; Digi-Key_PN 56-K102M15X7RF5UL2CT-ND
C12, C14, C15, C19: 0.1uF; C_Disc_D3.0mm_W2.0mm_P2.50mm; MPN K104M15X7RF5TL2; Digi-Key_PN 56-K104M15X7RF5TL2CT-ND
C13: 0.01uF; C_Disc_D3.0mm_W1.6mm_P2.50mm; MPN K103K15X7RF5UL2; Digi-Key_PN BC5227CT-ND
D16: LED; LED_D5.0mm; MPN XLUR12D; Digi-Key_PN 1497-1031-ND
J5: Conn_01x06_Male; PinHeader_1x06_P2.54mm_Horizontal; MPN 61300611021; Digi-Key_PN 732-5339-ND
J7: Conn_01x06_Male; PinHeader_1x06_P2.54mm_Vertical; MPN 61300611121; Digi-Key_PN 732-5319-ND
JP1: Jumper_2_Open; PinHeader_1x02_P2.54mm_Vertical
JP2, JP3: Jumper_3_Open; PinHeader_1x03_P2.54mm_Vertical
R7, R8: 10K; R_Axial_DIN0207_L6.3mm_D2.5mm_P7.62mm_Horizontal; MPN CFM12JT10K0; Digi-Key_PN S10KHCT-ND
R22: 220; R_Axial_DIN0207_L6.3mm_D2.5mm_P7.62mm_Horizontal; MPN CFM12JT220R; Digi-Key_PN S220HCT-ND
RN1: 10K; R_Array_SIP11; MPN 4611X-101-103LF; Digi-Key_PN 4611X-101-103LF-ND
SW1: SW_Push; SW_PUSH_6mm; MPN 1301.9302; Digi-Key_PN 486-3458-ND
U7: AVR128DA28-I/SS; DIP-28_W7.62mm_Socket; MPN AVR128DA28-E/SP; Digi-Key_PN 150-AVR128DA28-E/SP-ND
U8, U9: 7406; DIP-14_W7.62mm; MPN SN7406N; Digi-Key_PN 296-1435-5-ND

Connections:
+5V: C11.1, C12.1, C14.1, C15.1, C16.1, C19.1, R8.1, R22.2, U7.14 (AVDD), U7.20 (VDD), U8.14 (VCC), U9.14 (VCC); also elsewhere on the board
/Coin Line Control/L1_COIN_CONTROL: U8.10; also elsewhere on the board
/Coin Line Control/L1_HOLD_CO: U8.2; also elsewhere on the board
/Coin Line Control/L1_OFF_HOOK_F: U7.6 (PD0); also elsewhere on the board
/Coin Line Control/L1_OFF_HOOK_R: U7.7 (PD1); also elsewhere on the board
/Coin Line Control/L2_COIN_CONTROL: U9.6; also elsewhere on the board
/Coin Line Control/L2_HOLD_CO: U8.12; also elsewhere on the board
/Coin Line Control/L2_OFF_HOOK_F: U7.8 (PD2); also elsewhere on the board
/Coin Line Control/L2_OFF_HOOK_R: U7.9 (PD3); also elsewhere on the board
/Coin Line Control/L3_COIN_CONTROL: U9.10; also elsewhere on the board
/Coin Line Control/L3_HOLD_CO: U9.4; also elsewhere on the board
/Coin Line Control/L3_OFF_HOOK_F: U7.10 (PD4); also elsewhere on the board
/Coin Line Control/L3_OFF_HOOK_R: U7.11 (PD5); also elsewhere on the board
/Coin Line Control/L4_COIN_CONTROL: U9.2; also elsewhere on the board
/Coin Line Control/L4_HOLD_CO: U9.12; also elsewhere on the board
/Coin Line Control/L4_OFF_HOOK_F: U7.12 (PD6); also elsewhere on the board
/Coin Line Control/L4_OFF_HOOK_R: U7.13 (PD7); also elsewhere on the board
/Common Control/DISPOSITION: U8.8; also elsewhere on the board
/Common Control/REFUND: U8.6; also elsewhere on the board
/Common Control/TEST_STATUS_N: U7.28 (PA6); also elsewhere on the board
/GPIO/PA0_L1_HOLD_CO: RN1.8 (R7), U7.22 (PA0EXTCLK), U8.1
/GPIO/PA1_L2_HOLD_CO: RN1.7 (R6), U7.23 (PA1), U8.13
/GPIO/PA2_L3_HOLD_CO: RN1.4 (R3), U7.24 (PA2), U9.3
/GPIO/PA3_L4_HOLD_CO: RN1.3 (R2), U7.25 (PA3), U9.13
/GPIO/PA7: D16.1 (K), U7.1 (PA7)
/GPIO/PC0_L1_COIN_CONTROL: RN1.9 (R8), U7.2 (PC0), U8.11
/GPIO/PC1_L2_COIN_CONTROL: RN1.6 (R5), U7.3 (PC1), U9.5
/GPIO/PC2_L3_COIN_CONTROL: RN1.5 (R4), U7.4 (PC2), U9.11
/GPIO/PC3_L4_COIN_CONTROL: RN1.2 (R1), U7.5 (PC3), U9.1
/GPIO/PF0_REFUND: R7.1, RN1.11 (R10), U7.16 (PF0XTAL32K1), U8.5
/GPIO/PF1_DISPOSITION: RN1.10 (R9), U7.17 (PF1XTAL32K2), U8.9
/GPIO/RS232_RXD: JP3.1 (A); also elsewhere on the board
/GPIO/RS232_TXD: JP2.1 (A); also elsewhere on the board
/GPIO/TTL_RXD: J5.3, J7.4, JP3.3 (B)
/GPIO/TTL_TXD: J5.2, J7.5, JP2.3 (B)
/GPIO/UART_RXD: JP3.2 (C), U7.27 (PA5)
/GPIO/UART_TXD: JP2.2 (C), U7.26 (PA4)
/GPIO/UPDI: J7.2, JP1.2 (B), U7.19 (UPDI)
/GPIO/UPDI_EXT: J5.5, JP1.1 (A)
/GPIO/~RESET: C13.1, R8.2, SW1.1, U7.18 (PF6*RESET)
GND: C11.2, C12.2, C13.2, C14.2, C15.2, C16.2, C19.2, J5.6, J7.1, R7.2, RN1.1 (common), SW1.2, U7.15 (GND), U7.21 (GND), U8.3, U8.7 (GND), U9.7 (GND), U9.9; also elsewhere on the board
unnamed: D16.2 (A), R22.1

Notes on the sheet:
UPDI USB Serial 2v00 Rocket Scream
Serial Port Selection RS-232: JP1, JP2: 1-2 5V TTL: JP1, JP2: 2-3
1D Coin Controller
(c) 2020-2024, Howard M. Harte - WZ2Q https://github.com/hharte/1dcoinctrl
FTDI 5V USB UART
Pull-Downs for MCU, so relays are not activated during reset: If 10-resistor SIP is hard to source, use a common 9-resistor SIP and populate R26.

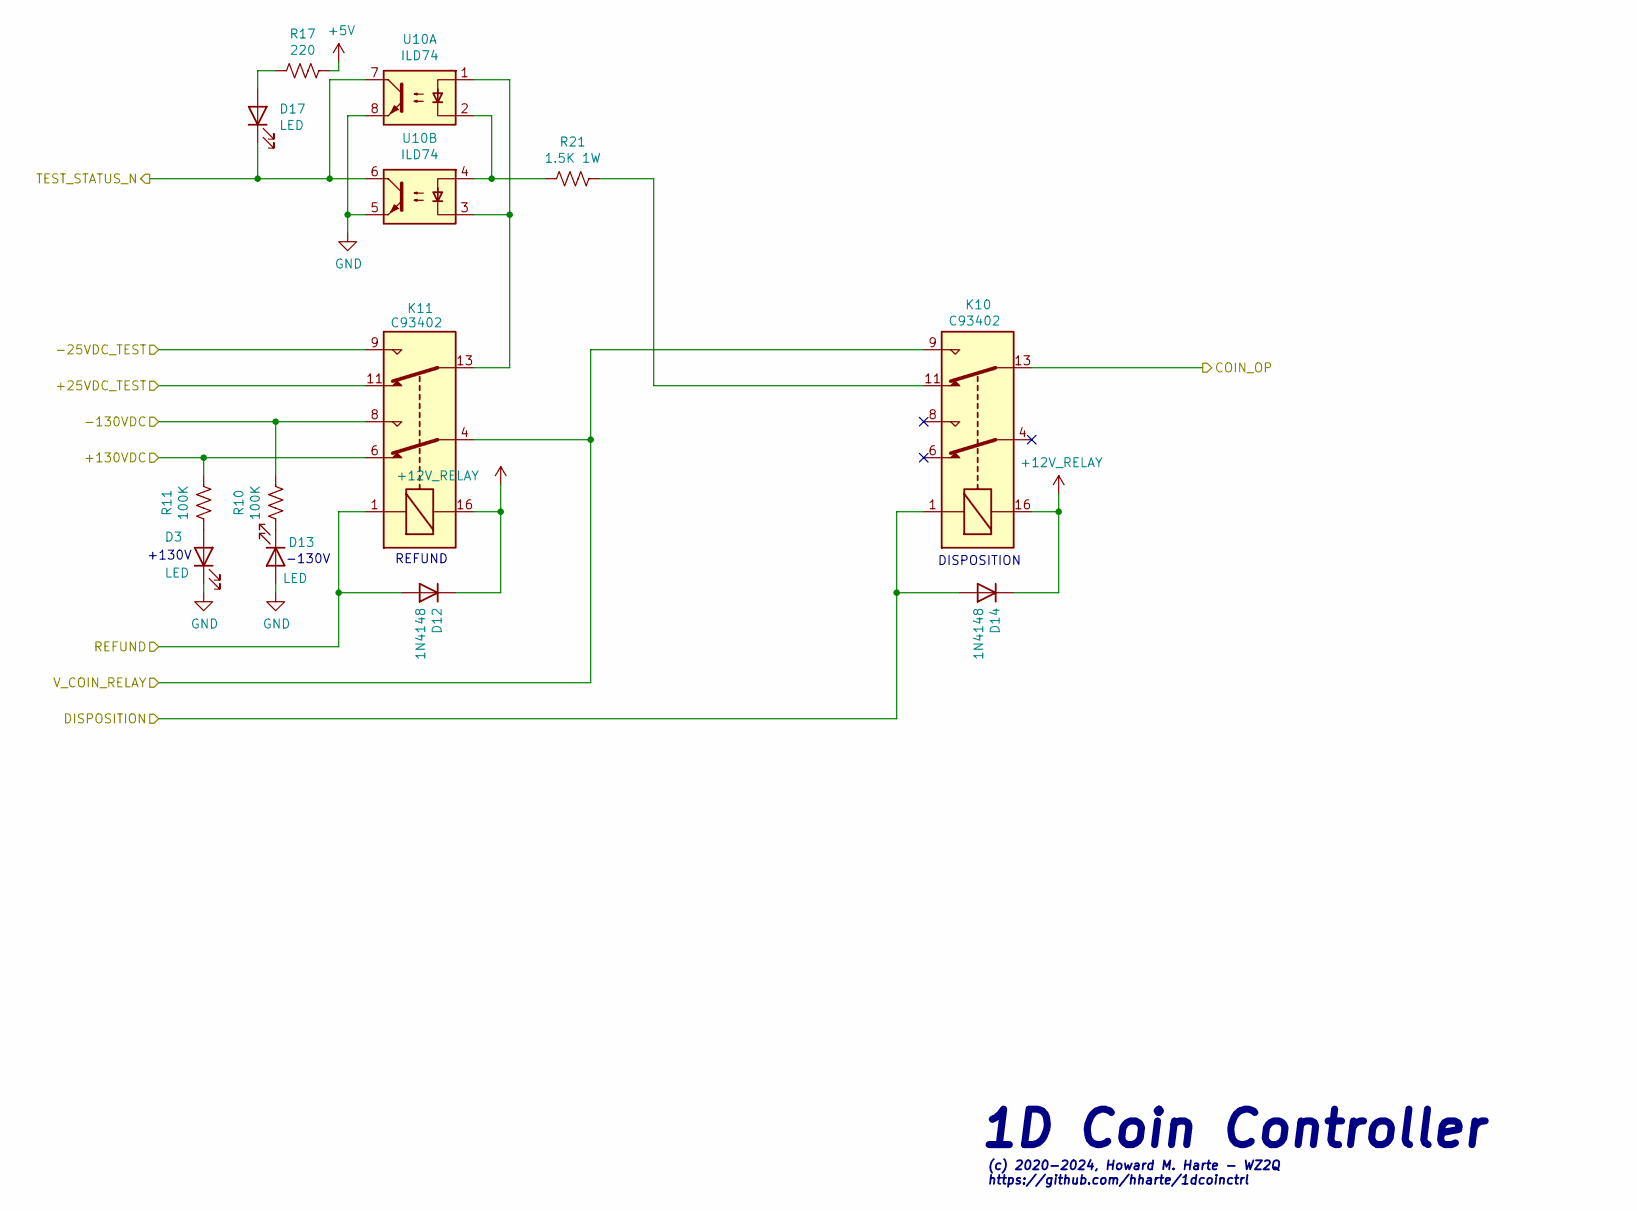
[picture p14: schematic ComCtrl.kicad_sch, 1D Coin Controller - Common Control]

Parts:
D3, D13, D17: LED; LED_D5.0mm; MPN XLUR12D; Digi-Key_PN 1497-1031-ND
D12, D14: 1N4148; D_DO-35_SOD27_P7.62mm_Horizontal; MPN 1N4148TA; Digi-Key_PN 1N4148TACT-ND
K10, K11: C93402; Relay_DPDT_Omron_G5V-2; MPN C93402; Digi-Key_PN PB1125-ND
R10, R11: 100K; R_Axial_DIN0207_L6.3mm_D2.5mm_P7.62mm_Horizontal; MPN CFM12JT100K; Digi-Key_PN S100KHCT-ND
R17: 220; R_Axial_DIN0207_L6.3mm_D2.5mm_P7.62mm_Horizontal; MPN CFM12JT220R; Digi-Key_PN S220HCT-ND
R21: 1.5K 1W; R_Axial_DIN0207_L6.3mm_D2.5mm_P10.16mm_Horizontal; MPN PR01000101501JR500; Digi-Key_PN PPC1.5KW-1CT-ND
U10: ILD74; DIP-8_W7.62mm_Socket; MPN CNY74-2H; Digi-Key_PN CNY74-2H-ND

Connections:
+5V: R17.1; also elsewhere on the board
+12V_RELAY: D12.1 (K), D14.1 (K), K10.16, K11.16; also elsewhere on the board
/Coin Line Control/COIN_OP: K10.13; also elsewhere on the board
/Common Control/+130VDC: K11.6, R11.1; also elsewhere on the board
/Common Control/-130VDC: K11.8, R10.1; also elsewhere on the board
/Common Control/DISPOSITION: D14.2 (A), K10.1; also elsewhere on the board
/Common Control/REFUND: D12.2 (A), K11.1; also elsewhere on the board
/Common Control/TEST_STATUS_N: D17.1 (K), U10.6, U10.7; also elsewhere on the board
/Common Control/V_COIN_RELAY: K10.9, K11.4; also elsewhere on the board
/Power/+25VDC: K11.11; also elsewhere on the board
/Power/-25VDC: K11.9; also elsewhere on the board
GND: D3.1 (K), D13.2 (A), U10.5, U10.8; also elsewhere on the board
unnamed: D3.2 (A), R11.2
unnamed: D13.1 (K), R10.2
unnamed: D17.2 (A), R17.2
unnamed: K10.11, R21.1
unnamed: K11.13, U10.1, U10.3
unnamed: R21.2, U10.2, U10.4

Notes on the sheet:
1D Coin Controller
DISPOSITION
+130V
REFUND
(c) 2020-2024, Howard M. Harte - WZ2Q https://github.com/hharte/1dcoinctrl
-130V

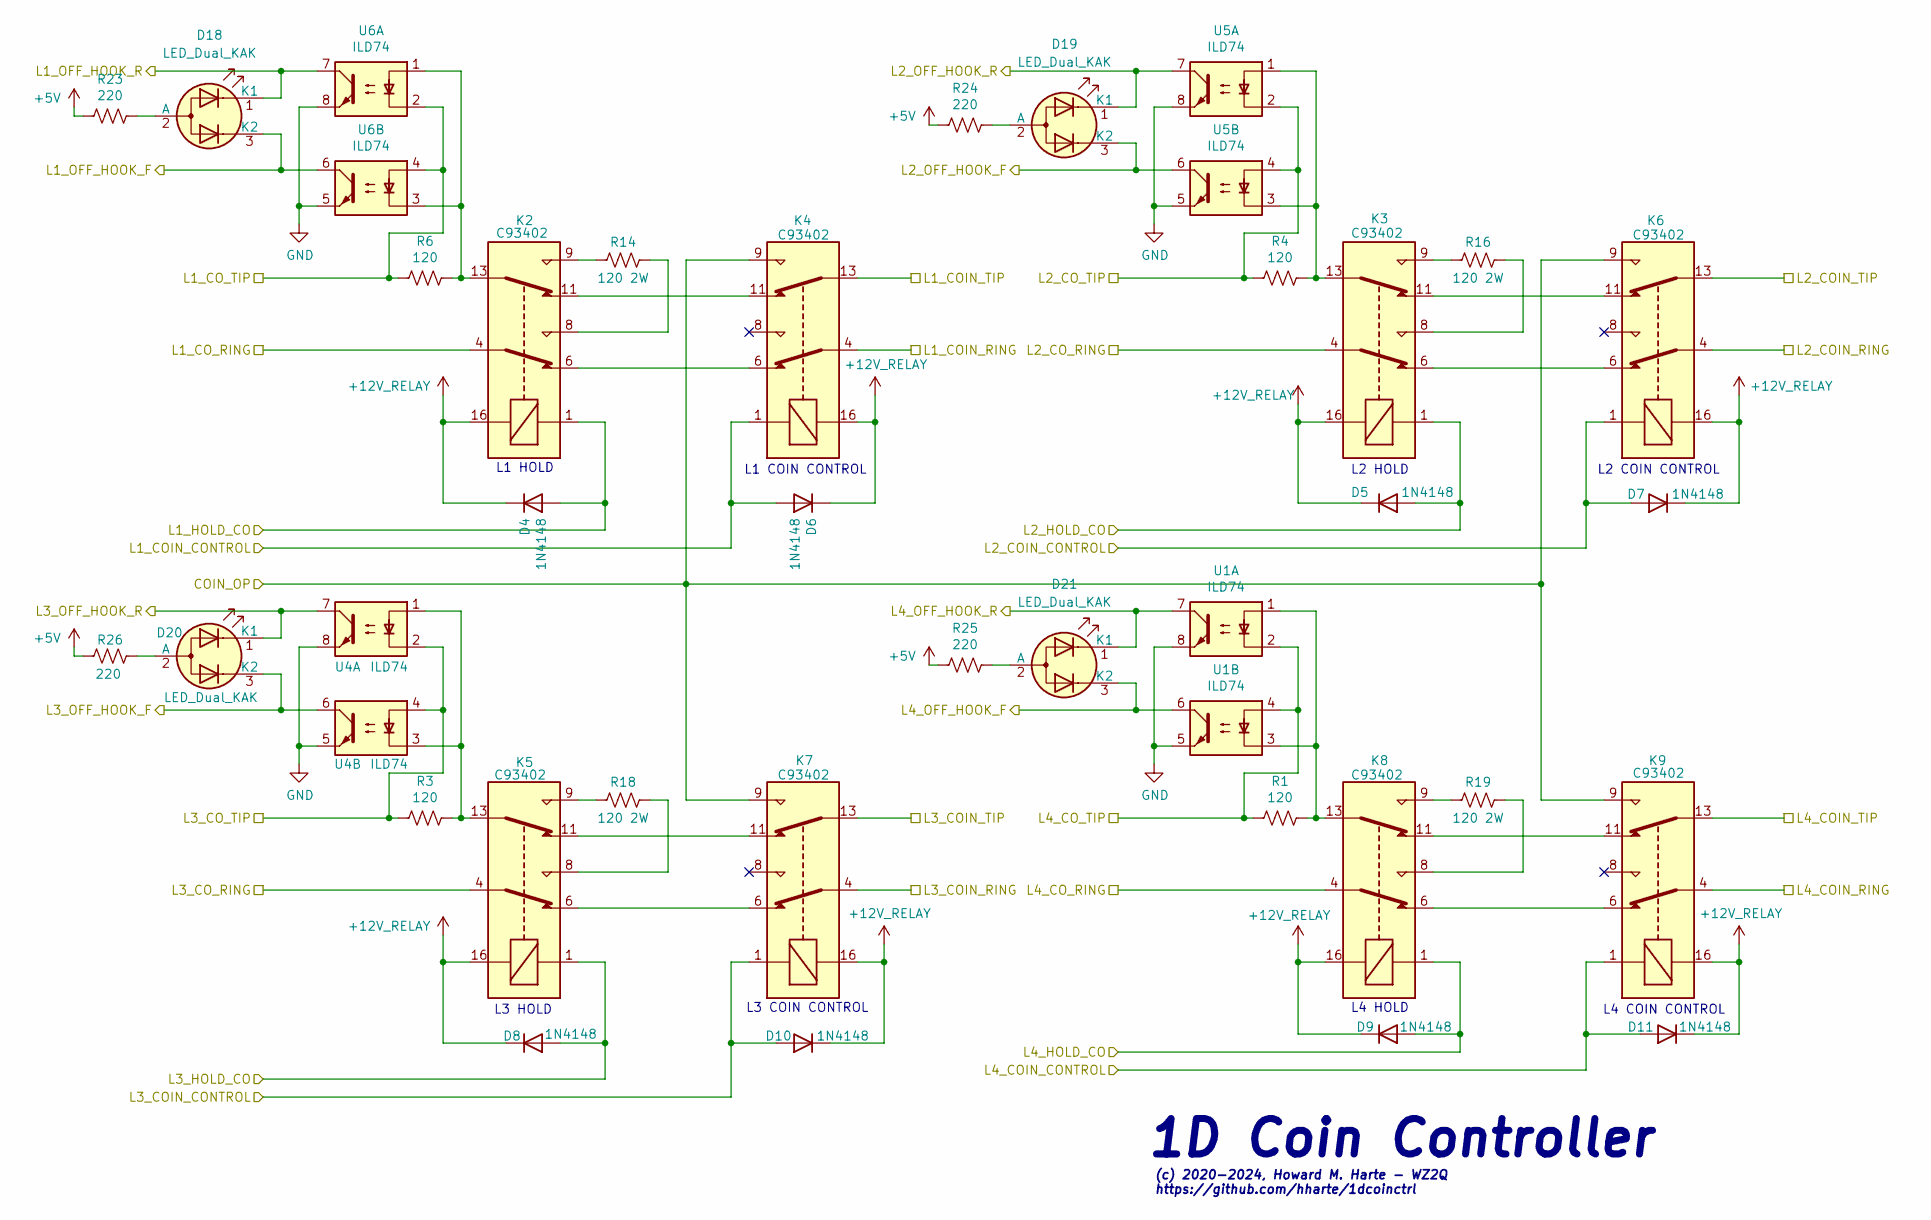
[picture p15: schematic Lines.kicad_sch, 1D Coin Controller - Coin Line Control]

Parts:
D4, D5, D6, D7, D8, D9, D10, D11: 1N4148; D_DO-35_SOD27_P7.62mm_Horizontal; MPN 1N4148TA; Digi-Key_PN 1N4148TACT-ND
D18, D19, D20, D21: LED_Dual_KAK; LED_D5.0mm-3; MPN XLMDKVG59MCA; Digi-Key_PN 1497-1357-ND
K2, K3, K4, K5, K6, K7, K8, K9: C93402; Relay_DPDT_Omron_G5V-2; MPN C93402; Digi-Key_PN PB1125-ND
R1, R3, R4, R6: 120; R_Axial_DIN0207_L6.3mm_D2.5mm_P7.62mm_Horizontal; MPN CFM12JT120R; Digi-Key_PN S120HCT-ND
R14, R16, R18, R19: 120 2W; R_Axial_DIN0516_L15.5mm_D5.0mm_P20.32mm_Horizontal; MPN FMP200JR-52-120R; Digi-Key_PN 120ZCT-ND
R23, R24, R25, R26: 220; R_Axial_DIN0207_L6.3mm_D2.5mm_P7.62mm_Horizontal; MPN CFM12JT220R; Digi-Key_PN S220HCT-ND
U1, U4, U5, U6: ILD74; DIP-8_W7.62mm_Socket; MPN CNY74-2H; Digi-Key_PN CNY74-2H-ND

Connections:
+5V: R23.2, R24.2, R25.2, R26.2; also elsewhere on the board
+12V_RELAY: D4.1 (K), D5.1 (K), D6.1 (K), D7.1 (K), D8.1 (K), D9.1 (K), D10.1 (K), D11.1 (K), K2.16, K3.16, K4.16, K5.16, K6.16, K7.16, K8.16, K9.16; also elsewhere on the board
/Coin Line Control/COIN_OP: K4.9, K6.9, K7.9, K9.9; also elsewhere on the board
/Coin Line Control/L1_COIN_CONTROL: D6.2 (A), K4.1; also elsewhere on the board
/Coin Line Control/L1_HOLD_CO: D4.2 (A), K2.1; also elsewhere on the board
/Coin Line Control/L1_OFF_HOOK_F: D18.3 (K2), U6.6; also elsewhere on the board
/Coin Line Control/L1_OFF_HOOK_R: D18.1 (K1), U6.7; also elsewhere on the board
/Coin Line Control/L2_COIN_CONTROL: D7.2 (A), K6.1; also elsewhere on the board
/Coin Line Control/L2_HOLD_CO: D5.2 (A), K3.1; also elsewhere on the board
/Coin Line Control/L2_OFF_HOOK_F: D19.3 (K2), U5.6; also elsewhere on the board
/Coin Line Control/L2_OFF_HOOK_R: D19.1 (K1), U5.7; also elsewhere on the board
/Coin Line Control/L3_COIN_CONTROL: D10.2 (A), K7.1; also elsewhere on the board
/Coin Line Control/L3_HOLD_CO: D8.2 (A), K5.1; also elsewhere on the board
/Coin Line Control/L3_OFF_HOOK_F: D20.3 (K2), U4.6; also elsewhere on the board
/Coin Line Control/L3_OFF_HOOK_R: D20.1 (K1), U4.7; also elsewhere on the board
/Coin Line Control/L4_COIN_CONTROL: D11.2 (A), K9.1; also elsewhere on the board
/Coin Line Control/L4_HOLD_CO: D9.2 (A), K8.1; also elsewhere on the board
/Coin Line Control/L4_OFF_HOOK_F: D21.3 (K2), U1.6; also elsewhere on the board
/Coin Line Control/L4_OFF_HOOK_R: D21.1 (K1), U1.7; also elsewhere on the board
/L1_COIN_RING: K4.4; also elsewhere on the board
/L1_COIN_TIP: K4.13; also elsewhere on the board
/L1_CO_RING: K2.4; also elsewhere on the board
/L1_CO_TIP: R6.2, U6.2, U6.4; also elsewhere on the board
/L2_COIN_RING: K6.4; also elsewhere on the board
/L2_COIN_TIP: K6.13; also elsewhere on the board
/L2_CO_RING: K3.4; also elsewhere on the board
/L2_CO_TIP: R4.2, U5.2, U5.4; also elsewhere on the board
/L3_COIN_RING: K7.4; also elsewhere on the board
/L3_COIN_TIP: K7.13; also elsewhere on the board
/L3_CO_RING: K5.4; also elsewhere on the board
/L3_CO_TIP: R3.2, U4.2, U4.4; also elsewhere on the board
/L4_COIN_RING: K9.4; also elsewhere on the board
/L4_COIN_TIP: K9.13; also elsewhere on the board
/L4_CO_RING: K8.4; also elsewhere on the board
/L4_CO_TIP: R1.2, U1.2, U1.4; also elsewhere on the board
GND: U1.5, U1.8, U4.5, U4.8, U5.5, U5.8, U6.5, U6.8; also elsewhere on the board
unnamed: D18.2 (A), R23.1
unnamed: D19.2 (A), R24.1
unnamed: D20.2 (A), R26.1
unnamed: D21.2 (A), R25.1
unnamed: K2.6, K4.6
unnamed: K2.8, R14.1
unnamed: K2.9, R14.2
unnamed: K2.11, K4.11
unnamed: K2.13, R6.1, U6.1, U6.3
unnamed: K3.6, K6.6
unnamed: K3.8, R16.1
unnamed: K3.9, R16.2
unnamed: K3.11, K6.11
unnamed: K3.13, R4.1, U5.1, U5.3
unnamed: K5.6, K7.6
unnamed: K5.8, R18.1
unnamed: K5.9, R18.2
unnamed: K5.11, K7.11
unnamed: K5.13, R3.1, U4.1, U4.3
unnamed: K8.6, K9.6
unnamed: K8.8, R19.1
unnamed: K8.9, R19.2
unnamed: K8.11, K9.11
unnamed: K8.13, R1.1, U1.1, U1.3

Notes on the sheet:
L2 HOLD
L4 COIN CONTROL
L1 COIN CONTROL
L2 COIN CONTROL
L3 HOLD
1D Coin Controller
L1 HOLD
L3 COIN CONTROL
L4 HOLD
(c) 2020-2024, Howard M. Harte - WZ2Q https://github.com/hharte/1dcoinctrl

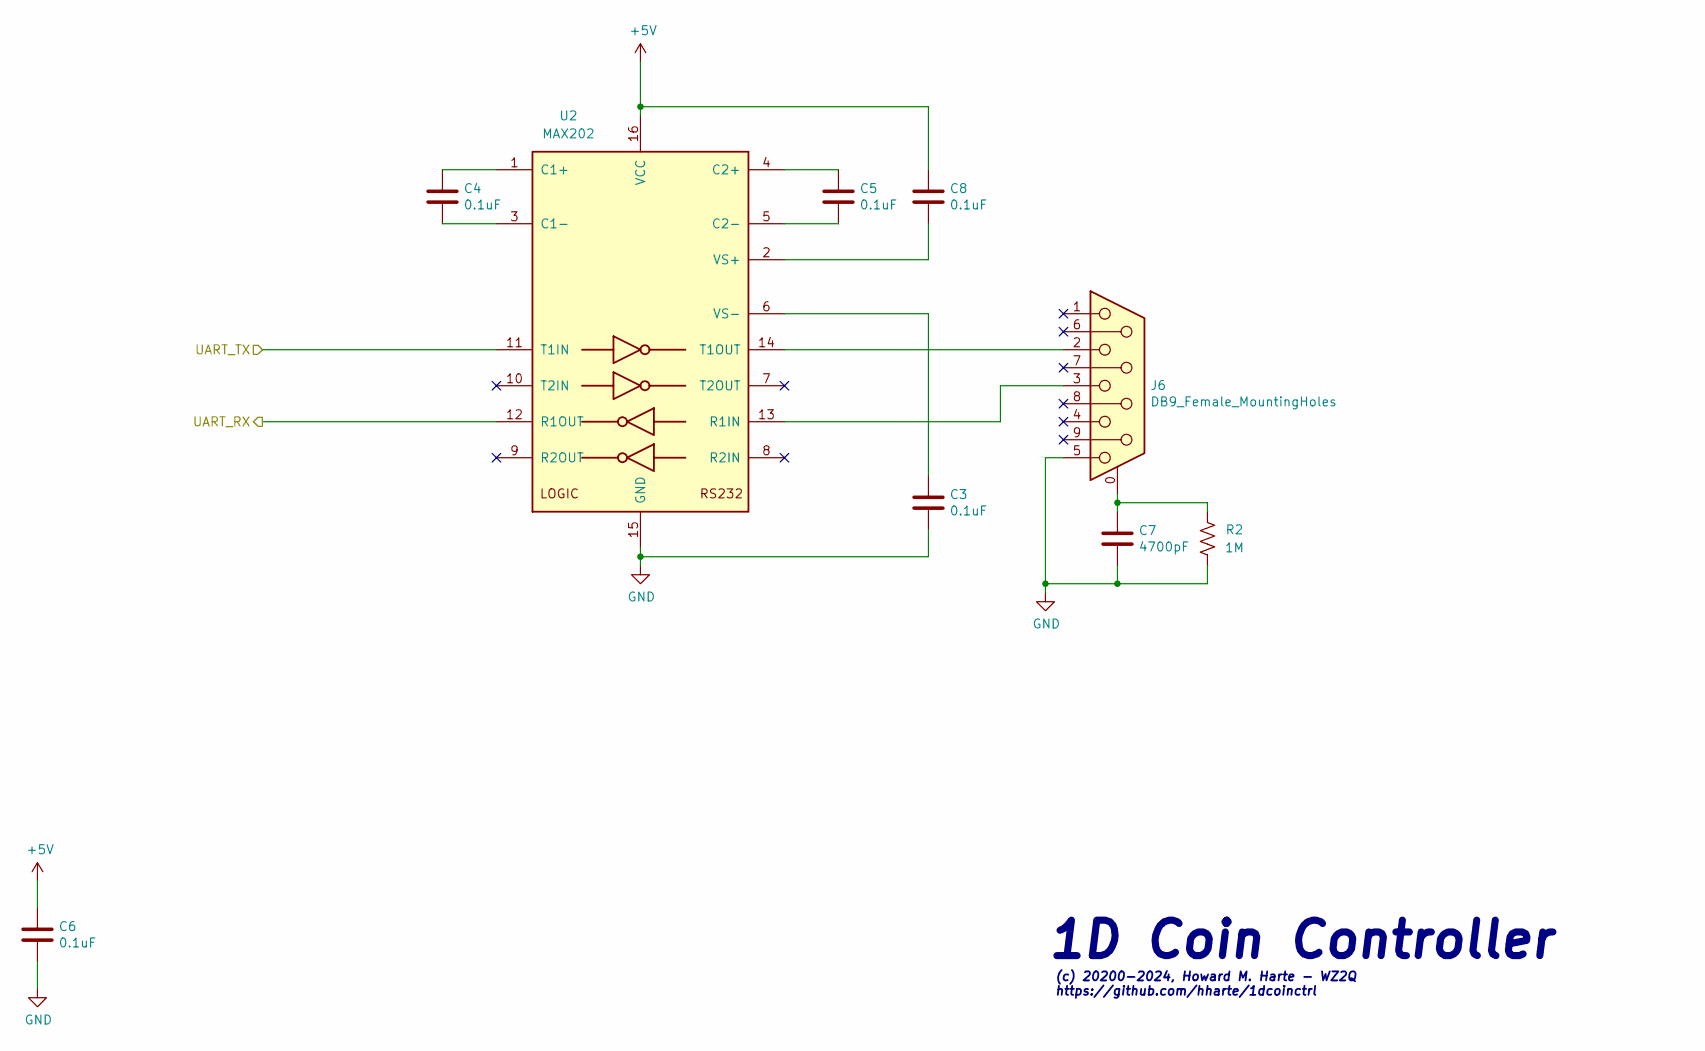
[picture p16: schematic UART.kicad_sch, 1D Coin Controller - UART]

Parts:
C3, C4, C5, C6, C8: 0.1uF; C_Disc_D3.0mm_W2.0mm_P2.50mm; MPN K104M15X7RF5TL2; Digi-Key_PN 56-K104M15X7RF5TL2CT-ND
C7: 4700pF; C_Disc_D4.3mm_W1.9mm_P5.00mm; MPN S472M39Z5UN63J5R; Digi-Key_PN 1288PH-ND
J6: DB9_Female_MountingHoles; DSUB-9_Female_Horizontal_P2.77x2.84mm_EdgePinOffset7.70mm_H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; MPN 747844-4; Digi-Key_PN A23303-ND
R2: 1M; R_Axial_DIN0207_L6.3mm_D2.5mm_P7.62mm_Horizontal; MPN CFM12JT1M00; Digi-Key_PN S1MHCT-ND
U2: MAX202; DIP-16_W7.62mm; MPN HIN232CPZ; Digi-Key_PN HIN232CPZ-ND

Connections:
+5V: C6.1, C8.1, U2.16 (VCC); also elsewhere on the board
/GPIO/RS232_RXD: U2.12 (R1OUT); also elsewhere on the board
/GPIO/RS232_TXD: U2.11 (T1IN); also elsewhere on the board
GND: C3.2, C6.2, C7.2, J6.5, R2.2, U2.15 (GND); also elsewhere on the board
unnamed: C7.1, J6.0 (PAD), R2.1
unnamed: C4.1, U2.1 (C1+)
unnamed: C4.2, U2.3 (C1-)
unnamed: C5.1, U2.4 (C2+)
unnamed: C5.2, U2.5 (C2-)
unnamed: J6.3, U2.13 (R1IN)
unnamed: J6.2, U2.14 (T1OUT)
unnamed: C8.2, U2.2 (VS+)
unnamed: C3.1, U2.6 (VS-)

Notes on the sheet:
(c) 20200-2024, Howard M. Harte - WZ2Q https://github.com/hharte/1dcoinctrl
1D Coin Controller

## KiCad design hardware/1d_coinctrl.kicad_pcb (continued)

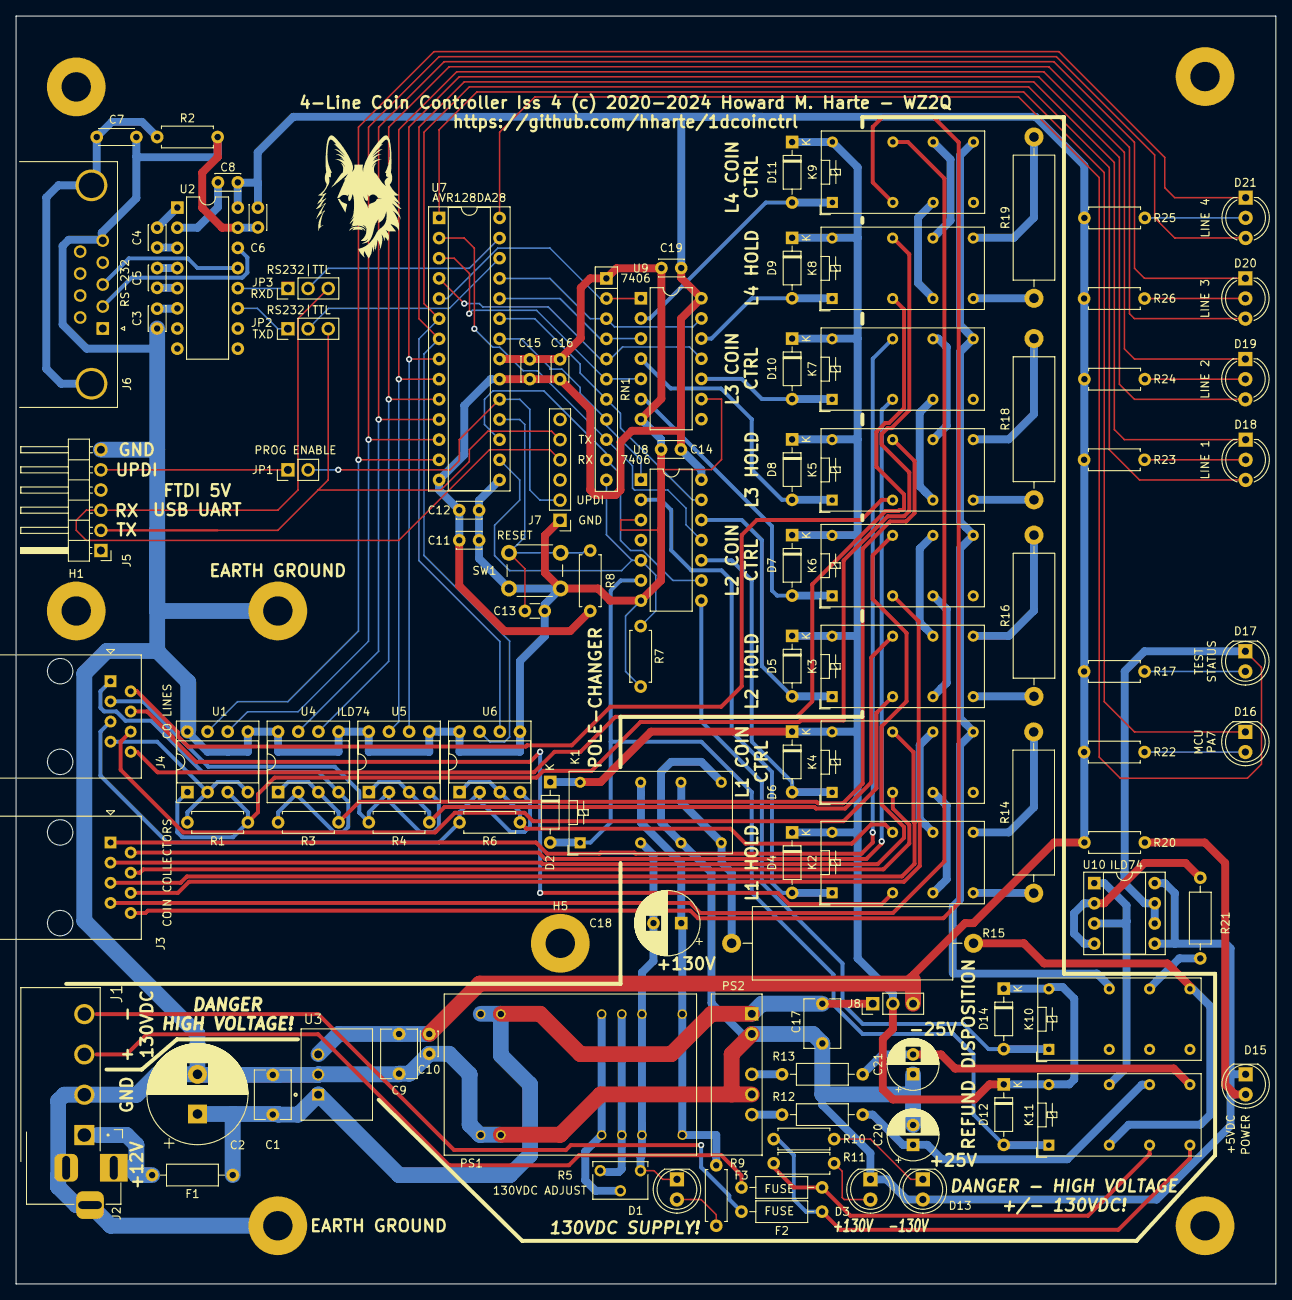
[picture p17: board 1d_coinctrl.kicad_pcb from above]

Board: 2 copper layers, 158.8 x 159.8 mm, 115 parts (0 on the bottom side), 117 nets.

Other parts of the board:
Deena: LOGO; Deena

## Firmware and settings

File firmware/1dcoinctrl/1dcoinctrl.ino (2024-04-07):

/*************************************************************************
 *                                                                       *
 * https://github.com/hharte/ky11lb                                      *
 *                                                                       *
 * MIT License                                                           *
 *                                                                       *
 * Copyright (c) 2024 Howard M. Harte                                    *
 *                                                                       *
 * Permission is hereby granted, free of charge, to any person obtaining *
 * a copy of this software and associated documentation files (the       *
 * "Software"), to deal in the Software without restriction, including   *
 * without limitation the rights to use, copy, modify, merge, publish,   *
 * distribute, sublicense, and/or sell copies of the Software, and to    *
 * permit persons to whom the Software is furnished to do so, subject    *
 * to the following conditions:                                          *
 *                                                                       *
 * The above copyright notice and this permission notice shall be        *
 * included in all copies or substantial portions of the Software.       *
 *                                                                       *
 * THE SOFTWARE IS PROVIDED "AS IS", WITHOUT WARRANTY OF ANY KIND,       *
 * EXPRESS OR IMPLIED, INCLUDING BUT NOT LIMITED TO THE WARRANTIES OF    *
 * MERCHANTABILITY, FITNESS FOR A PARTICULAR PURPOSE AND                 *
 * NONINFRINGEMENT. IN NO EVENT SHALL THE AUTHORS OR COPYRIGHT HOLDERS   *
 * BE LIABLE FOR ANY CLAIM, DAMAGES OR OTHER LIABILITY, WHETHER IN AN    *
 * ACTION OF CONTRACT, TORT OR OTHERWISE, ARISING FROM, OUT OF OR IN     *
 * CONNECTION WITH THE SOFTWARE OR THE USE OR OTHER DEALINGS IN THE      *
 * SOFTWARE.                                                             *
 *                                                                       *
 * Module Description:                                                   *
 * Coin Controller for Single-slot payphones.                            *
 *                                                                       *
 * Arduino 1.8.19 or later with DxCore 1.5.11.                           *
 *                                                                       *
 *************************************************************************/

#include <stdarg.h>

#define BAUD_RATE           115200
#define MS_PER_TICK         1
#define COUNT_PER_MS        93.6

#define COIN_LINE_MAX       4 /* Number of coin lines */

/* Pin assignments:
 * ref: https://github.com/SpenceKonde/DxCore/blob/master/megaavr/extras/DA28.md
 */

/* Port A */
#define L1_HOLD_CO          0   /* PA0 L1_HOLD_CO */
#define L2_HOLD_CO          1   /* PA1 L2_HOLD_CO */
#define L3_HOLD_CO          2   /* PA2 L3_HOLD_CO */
#define L4_HOLD_CO          3   /* PA3 L4_HOLD_CO */
//#define UART_TXD          4   /* PA4 UART TXD */
//#define UART_RXD          5   /* PA5 UART RXD */
#define TEST_STATUS_IN      6   /* PA6 */
#define STATUS_LED          7   /* PA7 */
#define STATUS_LED_B        (1 << 7)  /* PA7 */

/* Port C */
#define L1_COIN_CONTROL     8   /* PC0 */
#define L2_COIN_CONTROL     9   /* PC1 */
#define L3_COIN_CONTROL     10  /* PC2 */
#define L4_COIN_CONTROL     11  /* PC3 */

/* Port D: Hook State Inputs */
#define L1_OFF_HOOK_F       12  /* PD0 */
#define L1_OFF_HOOK_R       13  /* PD1 */
#define L2_OFF_HOOK_F       14  /* PD2 */
#define L2_OFF_HOOK_R       15  /* PD3 */
#define L3_OFF_HOOK_F       16  /* PD4 */
#define L3_OFF_HOOK_R       17  /* PD5 */
#define L4_OFF_HOOK_F       18  /* PD6 */
#define L4_OFF_HOOK_R       19  /* PD7 */

/* Port F: REFUND and DISPOSITION relay control. */
#define REFUND              20  /* PF0 */
#define DISPOSITION         21  /* PF1 */

#define LED_ON(x)           VPORTA.OUT &= ~STATUS_LED_B;
#define LED_OFF(x)          VPORTA.OUT |=  STATUS_LED_B;

#define RELEASE             false
#define HOLD                true
#define REFUND_COINS        false
#define COLLECT_COINS       true
#define INITIAL_RATE        true
#define STUCK_COIN          false

#define ON_HOOK             (0)
#define OFF_HOOK_F          (1)
#define OFF_HOOK_R          (2)

#define REFUND_ON           digitalWrite(REFUND, HIGH)
#define REFUND_OFF          digitalWrite(REFUND, LOW)
#define DISPOSITION_ON      digitalWrite(DISPOSITION, HIGH)
#define DISPOSITION_OFF     digitalWrite(DISPOSITION, LOW)
#define L1_HOLD_ON          digitalWrite(L1_HOLD_CO, HIGH)
#define L1_HOLD_OFF         digitalWrite(L1_HOLD_CO, LOW)
#define L2_HOLD_ON          digitalWrite(L2_HOLD_CO, HIGH)
#define L2_HOLD_OFF         digitalWrite(L2_HOLD_CO, LOW)
#define L3_HOLD_ON          digitalWrite(L3_HOLD_CO, HIGH)
#define L3_HOLD_OFF         digitalWrite(L3_HOLD_CO, LOW)
#define L4_HOLD_ON          digitalWrite(L4_HOLD_CO, HIGH)
#define L4_HOLD_OFF         digitalWrite(L4_HOLD_CO, LOW)

#define L1_COIN_CTRL_ON     digitalWrite(L1_COIN_CONTROL, HIGH)
#define L1_COIN_CTRL_OFF    digitalWrite(L1_COIN_CONTROL, LOW)
#define L2_COIN_CTRL_ON     digitalWrite(L2_COIN_CONTROL, HIGH)
#define L2_COIN_CTRL_OFF    digitalWrite(L2_COIN_CONTROL, LOW)
#define L3_COIN_CTRL_ON     digitalWrite(L3_COIN_CONTROL, HIGH)
#define L3_COIN_CTRL_OFF    digitalWrite(L3_COIN_CONTROL, LOW)
#define L4_COIN_CTRL_ON     digitalWrite(L4_COIN_CONTROL, HIGH)
#define L4_COIN_CTRL_OFF    digitalWrite(L4_COIN_CONTROL, LOW)

#define TEST_STATUS(x)      digitalRead(TEST_STATUS_IN)

#define INTERRUPT_GlobalInterruptLowDisable(x)
#define INTERRUPT_GlobalInterruptLowEnable(x)

#define wdt_reset() __asm__ __volatile__ ("wdr"::)  /* reset watchdog timer. */

//#define RELAY_DEBUG

const char menu[] = "\n\rCommands:\n\r" \
    "ATC Collect coin\n\r" \
    "ATR Refund coin\n\r" \
    "ATI Initial rate test\n\r" \
    "ATS Stuck coin test\n\r" \
    "ATQ Query hook state\n\r" \
    "ATL Query selected line\n\r" \
    "ATH Hold CO line\n\r" \
    "ATU Un-hold CO line\n\r" \
    "ATZ Reset controller\n\r" \
    "ATD Dump current state\n\r" \
    "ATE Test 100 refunds.\n\r" \
    "ATT Test (needs hard reset to exit.)\n\r" \
    "ATV Display version information\n\r" \
    "AT? Help\n\n\r"
#ifdef RELAY_DEBUG
    "Debugging commands:\n\r" \
    "ATO DISPOSITION Relay ON\r\n" \
    "ATP DISPOSITION Relay OFF\r\n" \
    "ATX COIN_CONTROL Relay ON\r\n" \
    "ATX COIN_CONTROL Relay OFF\r\n\n"
#endif /* RELAY_DEBUG */
    "Line number (1-4) may be specified after the AT command,\n\r" \
    "for example: ATC2 will collect line 2.\n\r";

bool debug = false;
bool pet_watchdog = true;
volatile uint32_t timer_tick = 0;
unsigned long millis1, millis2, timedelta = 0;
char outstr[255];

typedef struct ky11lb_state {
  uint32_t adrs_reg;    /* UNIBUS Address Register */
  uint32_t temp_reg;    /* Temporary Register */
} ky11lb_state_t;

typedef struct pulse_entry {
    uint16_t pulse_duration;
    uint8_t hook_state;
} pulse_entry_t;

#define PULSE_LIST_ENTRIES_MAX  32  /* Must be a power of 2! */
#define DIGIT_LIST_ENTRIES_MAX  16  /* Must be a power of 2! */

typedef struct digit_fifo {
    uint8_t wptr;
    uint8_t rptr;
    uint8_t dialed_digit[DIGIT_LIST_ENTRIES_MAX];
    uint8_t current_digit;
    uint16_t digit_start_time;
    uint16_t digit_duration;
} digit_fifo_t;

typedef struct hook_switch_context {
    uint32_t last_tick;
    uint8_t wptr;
    uint8_t rptr;
#ifdef DEBUG_PULSES
    pulse_entry_t pulse_list[PULSE_LIST_ENTRIES_MAX];
#endif /* DEBUG_FIFO */
    digit_fifo_t digits;
    volatile uint8_t dial_in_progress;
    uint8_t coin_op_in_progress;
    volatile uint8_t hook_state;
    uint8_t hook_state_delayed;
    uint8_t prev_hook_state;
} hook_switch_context_t;

hook_switch_context_t hs_context[COIN_LINE_MAX] = { 0 };

uint8_t coin_line;
uint32_t ioc_count;

typedef int (kp_func_ptr_t)(bool, uint8_t);

typedef struct kp_def {
  const char *str;    /* Name of the key */
  uint8_t kevent;     /* Key Event(s) desired (KEY_DOWN, KEY_UP, KEY_BOTH) */
  uint8_t value;      /* Value of numerical keys */
  bool intr;          /* Whether or not to generate an interrupt to the host. */
  kp_func_ptr_t *fn;  /* Handler function */
} kp_def_t;

ky11lb_state_t fp;

void print_fp_status(void);
static void delay_ms(uint16_t ms);
void hook_state_ISR(void);
void process_coin_lines(void);
static void set_line_hold(uint8_t coin_line, uint8_t state);
static void set_line_hold_cmd(uint8_t coin_line, uint8_t state);
static void do_coin_ctrl(uint8_t coin_line, uint8_t state);
static void collect_coin(uint8_t coin_line, uint8_t collect);
static uint8_t test_coin(uint8_t coin_line, uint8_t initial_rate);
static void print_version(void);
static void coinctrl_reset(void);
void clear_ioc_per_line(uint8_t coin_line);

void DEBUG_ERROR(char const * fmt, ...)
{
  char buf[80] = {0};

  va_list args;
  va_start(args, fmt);
  vsnprintf(buf, 80, fmt, args);
  va_end(args);
  Serial.println(buf);
}

#define DEBUG_INFO  DEBUG_ERROR

static void print_version(void)
{
    DEBUG_ERROR("Western Electric 1D Coin Controller Iss 4 Firmware v1.1\n\r" \
                "(c) 2020-2024 Howard M. Harte, WZ2Q\n\r" \
                "http://github.com/hharte/1dcoinctrl\n\r");
}

/* Runs once during boot. */
void setup(void) {

  /* Initialize serial port */
  Serial.swap(1); /* Use PA4/PA5 for UART */
  Serial.begin(BAUD_RATE);

  VPORTC.OUT = 0xFF;
  VPORTD.OUT = 0xFF;

  /* Initialize GPIO Pins */
  pinMode (L1_COIN_CONTROL, OUTPUT);
  pinMode (L2_COIN_CONTROL, OUTPUT);
  pinMode (L3_COIN_CONTROL, OUTPUT);
  pinMode (L4_COIN_CONTROL, OUTPUT);
  pinMode (L1_HOLD_CO,      OUTPUT);
  pinMode (L2_HOLD_CO,      OUTPUT);
  pinMode (L3_HOLD_CO,      OUTPUT);
  pinMode (L4_HOLD_CO,      OUTPUT);
  pinMode (STATUS_LED,      OUTPUT);
  pinMode (REFUND,          OUTPUT);
  pinMode (DISPOSITION,     OUTPUT);

  pinMode (TEST_STATUS_IN,  INPUT_PULLUP);
  pinMode (L1_OFF_HOOK_F,   INPUT_PULLUP);
  pinMode (L1_OFF_HOOK_R,   INPUT_PULLUP);
  pinMode (L2_OFF_HOOK_F,   INPUT_PULLUP);
  pinMode (L2_OFF_HOOK_R,   INPUT_PULLUP);
  pinMode (L3_OFF_HOOK_F,   INPUT_PULLUP);
  pinMode (L3_OFF_HOOK_R,   INPUT_PULLUP);
  pinMode (L4_OFF_HOOK_F,   INPUT_PULLUP);
  pinMode (L4_OFF_HOOK_R,   INPUT_PULLUP);

  takeOverTCA0();
  TCA0.SINGLE.CTRLB = TCA_SINGLE_WGMODE_NORMAL_gc;
  TCA0.SINGLE.EVCTRL &= ~(TCA_SINGLE_CNTEI_bm);
  TCA0.SINGLE.PER = MS_PER_TICK * COUNT_PER_MS;
  TCA0.SINGLE.INTCTRL = TCA_SINGLE_OVF_bm; /* Enable timer overflow interrupt */
  TCA0.SINGLE.CTRLA = TCA_SINGLE_CLKSEL_DIV256_gc | TCA_SINGLE_ENABLE_bm;

  /* Enable Interrupt on Change for Port D (Hook State) */
  PORTD.PIN0CTRL &= ~(0b00000111);
  PORTD.PIN0CTRL |= PORT_ISC_BOTHEDGES_gc;
  PORTD.PIN1CTRL &= ~(0b00000111);
  PORTD.PIN1CTRL |= PORT_ISC_BOTHEDGES_gc;
  PORTD.PIN2CTRL &= ~(0b00000111);
  PORTD.PIN2CTRL |= PORT_ISC_BOTHEDGES_gc;
  PORTD.PIN3CTRL &= ~(0b00000111);
  PORTD.PIN3CTRL |= PORT_ISC_BOTHEDGES_gc;
  PORTD.PIN4CTRL &= ~(0b00000111);
  PORTD.PIN4CTRL |= PORT_ISC_BOTHEDGES_gc;
  PORTD.PIN5CTRL &= ~(0b00000111);
  PORTD.PIN5CTRL |= PORT_ISC_BOTHEDGES_gc;
  PORTD.PIN6CTRL &= ~(0b00000111);
  PORTD.PIN6CTRL |= PORT_ISC_BOTHEDGES_gc;
  PORTD.PIN7CTRL &= ~(0b00000111);
  PORTD.PIN7CTRL |= PORT_ISC_BOTHEDGES_gc;

  print_version();

  coinctrl_reset();
  coin_line = 0;                      // Set default coin_line

  DEBUG_ERROR("\r\nOK\r\n");
}

/* Main loop: Process serial console and board inputs */
void loop() {
  hook_switch_context_t *pHS;
  uint8_t coin_line;
  char c = 0;
  char atcmd[80];
  uint16_t len = 0;
  uint16_t i;
  uint8_t pps;
  uint8_t digit;
  uint16_t digit_duration;

  if (pet_watchdog) {
    wdt_reset();  /* Pet watchdog timer. */
  }

  while (1) {
    while (c != '\r') {
      if (Serial.available() > 0) {
        /* Read character from the serial port. */
        c = Serial.read();

        if ((c == 0x08) || (c == 0x7F)) {
            len--;
            atcmd[len] = 0;
              Serial.write(0x7F);
        } else {
            atcmd[len] = (char)toupper(c);
            len++;
            Serial.write(c);
        }
      }
    }
    atcmd[len - 1 ] = 0;
    Serial.print("\r");
    c = 0;
    len = 0;

    if (atcmd[0] == 'A' && atcmd[1] == 'T') {
      if (atcmd[3] >= '1' && atcmd[3] < (COIN_LINE_MAX + '1')) {
        coin_line = atcmd[3] - '1';
      } else if (atcmd[3] != 0) {
        Serial.println("ERROR");
        continue;
      }

      DEBUG_INFO("Timer_tick: %lu (last: %lu), ioc_int: %lu, Current Line: %d, hook state: %d -> %d (%d delayed), dial in progress: %d, last dialed_digit: %d",
              timer_tick,
              hs_context[coin_line].last_tick,
              ioc_count,
              coin_line + 1,
              hs_context[coin_line].prev_hook_state,
              hs_context[coin_line].hook_state,
              hs_context[coin_line].hook_state_delayed,
              hs_context[coin_line].dial_in_progress,
              hs_context[coin_line].digits.dialed_digit[(hs_context[coin_line].digits.wptr - 1) & (DIGIT_LIST_ENTRIES_MAX - 1)]);

      switch (atcmd[2]) {
      case 'D': /* Dump current state. */
        digit = hs_context[coin_line].digits.dialed_digit[(hs_context[coin_line].digits.wptr - 1) & (DIGIT_LIST_ENTRIES_MAX - 1)];
        if (digit > 1) {
          /* Calculate PPS */
          digit_duration = hs_context[coin_line].digits.digit_duration;
          pps = (uint8_t)(((digit - 1) * 1000) / (digit_duration / 10));
        }
        DEBUG_ERROR(outstr, sizeof(outstr), "Timer_tick: %lu, Current Line: %d, hook state: %d -> %d, dial in progress: %d, last dialed_digit: %d, %u.%upps",
                 timer_tick,
                 coin_line + 1,
                 hs_context[coin_line].prev_hook_state,
                 hs_context[coin_line].hook_state,
                 hs_context[coin_line].dial_in_progress,
                 digit,
                 pps / 10, pps % 10);

        for (i = 0; i < COIN_LINE_MAX; i++) {
          pHS = &hs_context[i];
#ifdef DEBUG_PULSES
          while(pHS->rptr != pHS->wptr) {
            DEBUG_ERROR("%d: [%u ms] 0x%02x", hs_context[i].rptr,
                    pHS->pulse_list[pHS->rptr].pulse_duration,
                    pHS->pulse_list[pHS->rptr].hook_state);
            pHS->rptr++;
            pHS->rptr &= (PULSE_LIST_ENTRIES_MAX - 1);
          }

          if (pHS->digits.rptr == pHS->digits.wptr) {
            continue;
          }
#endif /* DEBUG_PULSES */
          DEBUG_ERROR("Line %d dialed digits: ", i + 1);

          while (pHS->digits.rptr != pHS->digits.wptr) {
            DEBUG_ERROR("%d, ", pHS->digits.dialed_digit[pHS->digits.rptr]);
            pHS->digits.rptr++;
            pHS->digits.rptr &= (DIGIT_LIST_ENTRIES_MAX - 1); /* Wrap the pointer */
          }
        }
        Serial.println("OK");
        break;
      case 'H':
        set_line_hold_cmd(coin_line, HOLD);
        Serial.println("OK");
        break;
      case 'U':
        set_line_hold_cmd(coin_line, RELEASE);
        Serial.println("OK");
        break;
      case 'C':
        collect_coin(coin_line, COLLECT_COINS);
        Serial.println("OK");
        break;
      case 'R':
        collect_coin(coin_line, REFUND_COINS);
        Serial.println("OK");
        break;
      case 'I':
        DEBUG_ERROR("Initial Rate: %d", test_coin(coin_line, INITIAL_RATE));
        break;
      case 'V':
        print_version();
        Serial.println("OK");
        break;
      case 'S':
        DEBUG_ERROR("Stuck Coin: %d", test_coin(coin_line, STUCK_COIN));
        break;
      case 'T':
        DEBUG_ERROR("Starting test, RESET to exit....");
        while (1) {
          process_coin_lines();
        }
        break;
      case 'Q':
        DEBUG_ERROR("Hook State: %d", hs_context[coin_line].hook_state);
        break;
      case 'L':
        DEBUG_ERROR("%d", coin_line + 1);
        break;
      case 'E':
        for (i = 0; i < 100 ; i++) {
          DEBUG_ERROR("%d: ", i);
          collect_coin(coin_line, REFUND_COINS);
          delay_ms(1000);
        }
        Serial.println("OK");
        break;
#ifdef RELAY_DEBUG
      case 'O':
        DEBUG_ERROR("DISPOSITION_ON");
        DISPOSITION_ON;
        break;
      case 'P':
        DEBUG_ERROR("DISPOSITION_OFF");
        DISPOSITION_OFF;
        break;
      case 'X': /* Activate Coin Control relay */
        DEBUG_ERROR("COIN CONTROL ON");
        do_coin_ctrl(coin_line, true);
        break;
      case 'Y': /* Release Coin Control relay */
        DEBUG_ERROR("COIN CONTROL OFF");
        do_coin_ctrl(coin_line, false);
        break;
#endif /* RELAY_DEBUG */
      case 'Z': /* Reset */
        coinctrl_reset();
        coin_line = 0;  // Set default coin_line
        /* Fall through */
      case 0:
        Serial.println("OK");
        break;
      case '?':
        DEBUG_ERROR(menu);
        Serial.println("OK");
        break;
      default:
        Serial.println("ERROR");
        break;
      }
    }
  }
}

void process_coin_lines(void)
{
  uint8_t coin_line;
  hook_switch_context_t *pHS;
  uint8_t prev_hook_state, hook_state;

  for (coin_line = 0; coin_line < COIN_LINE_MAX; coin_line++) {
    pHS = &hs_context[coin_line];

    /* Do not process the hook switch state while dialing is in progress. */
    if (pHS->dial_in_progress == 1) continue;

    hook_state = pHS->hook_state_delayed;
    prev_hook_state = pHS->prev_hook_state;
    if (hook_state != prev_hook_state) {
      DEBUG_ERROR("Hook state for line %d changed from %d to %d.",
               coin_line + 1,
               prev_hook_state,
               hook_state);

      switch(hook_state) {
      case ON_HOOK:
        if (prev_hook_state == OFF_HOOK_F) {
          DEBUG_ERROR("Refund coin, line %d.", coin_line + 1);
          collect_coin(coin_line, REFUND_COINS);
        } else if (prev_hook_state == OFF_HOOK_R) {
          DEBUG_ERROR("Collect coin, line %d", coin_line + 1);
          collect_coin(coin_line, COLLECT_COINS);
        }
        break;
      case OFF_HOOK_R:
        if (prev_hook_state == OFF_HOOK_F) {
          DEBUG_ERROR("Collect coin2, line %d", coin_line + 1);
          collect_coin(coin_line, COLLECT_COINS);
        }
      }
      pHS->prev_hook_state = pHS->hook_state_delayed;
    }
  }
}

/* Use the 1ms timer tick to delay for the specified number of milliseconds. */
static void delay_ms(uint16_t ms)
{
  uint32_t end_time;

  end_time = timer_tick + ms;

  while (timer_tick < end_time);
}


/* The TCA0 Timer Tick Interrupt must be higher-priority than the IOC ISR. */
ISR(TCA0_OVF_vect) {
  hook_switch_context_t *pHS;
  uint8_t coin_line;
  uint32_t time_delta;

  TCA0.SINGLE.INTFLAGS  = TCA_SINGLE_OVF_bm; /* Clear interrupt flags */
  timer_tick += 1;

  millis2 = millis1;
  millis1 = millis();

  if ((timer_tick % 500) == 0) {
    bool led_state = VPORTA.OUT & STATUS_LED_B;
    if (led_state) {
      LED_ON();
    } else {
      LED_OFF();
    }
  }

  for (coin_line = 0; coin_line < COIN_LINE_MAX; coin_line++) {
    pHS = &hs_context[coin_line];

    /* Calculate the time since the last pulse. */
    time_delta = timer_tick - pHS->last_tick;

    /* If more than 100ms has passed since the last hook state interrupt,
     * we may need to add the current_digit to the dialed_digits FIFO.
     */
    if (time_delta > 100) {
      if (pHS->digits.current_digit != 0) {
        pHS->digits.dialed_digit[pHS->digits.wptr] = pHS->digits.current_digit;
        pHS->digits.wptr++;
        pHS->digits.wptr &= (DIGIT_LIST_ENTRIES_MAX - 1); /* Wrap the pointer */
        pHS->digits.current_digit = 0;
        pHS->dial_in_progress = 0;
      }
      pHS->hook_state_delayed = pHS->hook_state;
    }
  }
}

/* Hook State ISR */
ISR(PORTD_PORT_vect) {
  uint32_t time_delta;
  hook_switch_context_t *pHS;
  uint8_t hook_state;
  uint8_t coin_line;
  uint8_t coin_line_hook_state;
  uint8_t prev_coin_line_hook_state;
  static uint8_t prev_hook_state = 0;
  static uint32_t on_hook_start_time[COIN_LINE_MAX] = { 0 };
  uint16_t on_hook_pulse_duration;
  static uint32_t off_hook_start_time[COIN_LINE_MAX] = { 0 };
  uint16_t off_hook_pulse_duration;

  byte flags = PORTD.INTFLAGS;
  PORTD.INTFLAGS = flags; //clear flags

  ioc_count++;

  hook_state  = ~VPORTD.IN;

  for (coin_line = 0; coin_line < COIN_LINE_MAX; coin_line++) {
    pHS = &hs_context[coin_line];

    coin_line_hook_state = (hook_state >> (coin_line << 1)) & 0x03;
    prev_coin_line_hook_state = (prev_hook_state >> (coin_line << 1)) & 0x03;

    if (pHS->coin_op_in_progress == 1) {
      continue;
    }
    if (prev_coin_line_hook_state == coin_line_hook_state) {
      continue;
    }

    time_delta = timer_tick - pHS->last_tick;
    pHS->last_tick = timer_tick;

    DEBUG_ERROR("Line %d, hook_state=%d", coin_line + 1, coin_line_hook_state);

    if (coin_line_hook_state == ON_HOOK) {
      on_hook_start_time[coin_line] = timer_tick;
      on_hook_pulse_duration = 0;
      off_hook_pulse_duration = (uint16_t)(timer_tick - off_hook_start_time[coin_line]);
#ifdef DEBUG_PULSES
      pHS->pulse_list[pHS->wptr].pulse_duration = off_hook_pulse_duration;
#endif /* DEBUG_PULSES */
    } else { /* OFF_HOOK */
      off_hook_start_time[coin_line] = timer_tick;
      off_hook_pulse_duration = 0;
      on_hook_pulse_duration = (uint16_t)(timer_tick - on_hook_start_time[coin_line]);
#ifdef DEBUG_PULSES
      pHS->pulse_list[pHS->wptr].pulse_duration = on_hook_pulse_duration;
#endif /* DEBUG_PULSES */
    }
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

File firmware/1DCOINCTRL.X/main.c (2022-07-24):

/**
  Generated Main Source File

  Company:
    Microchip Technology Inc.

  File Name:
    main.c

  Summary:
    This is the main file generated using PIC10 / PIC12 / PIC16 / PIC18 MCUs

  Description:
    This header file provides implementations for driver APIs for all modules selected in the GUI.
    Generation Information :
        Product Revision  :  PIC10 / PIC12 / PIC16 / PIC18 MCUs - 1.81.8
        Device            :  PIC18F47Q84
        Driver Version    :  2.00
*/

/*
    (c) 2018 Microchip Technology Inc. and its subsidiaries. 
    
    Subject to your compliance with these terms, you may use Microchip software and any 
    derivatives exclusively with Microchip products. It is your responsibility to comply with third party 
    license terms applicable to your use of third party software (including open source software) that 
    may accompany Microchip software.
    
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
    IN NO EVENT WILL MICROCHIP BE LIABLE FOR ANY INDIRECT, SPECIAL, PUNITIVE, 
    INCIDENTAL OR CONSEQUENTIAL LOSS, DAMAGE, COST OR EXPENSE OF ANY KIND 
    WHATSOEVER RELATED TO THE SOFTWARE, HOWEVER CAUSED, EVEN IF MICROCHIP 
    HAS BEEN ADVISED OF THE POSSIBILITY OR THE DAMAGES ARE FORESEEABLE. TO 
    THE FULLEST EXTENT ALLOWED BY LAW, MICROCHIP'S TOTAL LIABILITY ON ALL 
    CLAIMS IN ANY WAY RELATED TO THIS SOFTWARE WILL NOT EXCEED THE AMOUNT 
    OF FEES, IF ANY, THAT YOU HAVE PAID DIRECTLY TO MICROCHIP FOR THIS 
    SOFTWARE.
*/

#include "mcc_generated_files/mcc.h"

extern uint8_t coinctrl_main(void);

/*
                         Main application
 */
void main(void)
{
    // Initialize the device
    SYSTEM_Initialize();

    // If using interrupts in PIC18 High/Low Priority Mode you need to enable the Global High and Low Interrupts
    // If using interrupts in PIC Mid-Range Compatibility Mode you need to enable the Global Interrupts
    // Use the following macros to:

    // Enable high priority global interrupts
    //INTERRUPT_GlobalInterruptHighEnable();

    // Enable low priority global interrupts.
    //INTERRUPT_GlobalInterruptLowEnable();

    // Disable high priority global interrupts
    //INTERRUPT_GlobalInterruptHighDisable();

    // Disable low priority global interrupts.
    //INTERRUPT_GlobalInterruptLowDisable();

    coinctrl_main();
    printf("DIED!!!!!!!!!!!!!\n\r\n");
    while (1)
    {
        // Add your application code
    }
}
/**
 End of File
*/

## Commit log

2015-01-11 Update README.md to reflect that WE 32A and TeleService 4032C chassis are working with this design."
2015-01-11 Do not put the line on hold unless it is off hook. Putting the line on hold during coin/test operations when it is not already off-hook can lead to Asterisk interpreting the hold/unhold as a switch h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
2015-07-07 Add expect scripts to interface with coin control hardware
    The 1D coin control hardware is connected to a Raspberry Pi via a
    serial port. The Raspberry Pi runs the ser2sock daemon to make the
    serial port available via telnet.
    These expect scripts run on the Asterisk server and talk via telnet
    to ser2sock running on the Raspberry Pi.
    https://github.com/nutechsoftware/ser2sock
2019-11-30 Update 1700/2200Hz coin tone detection for tip of Asterisk-13 branch.
2020-06-14 Update schematic for Issue 1 PCB.
2020-06-14 Update README.md for Issue 1 PCB.
2020-06-14 Add KiCAD files for Issue 1 PCB.
    WARNING: Do not fab this board as-is, the footprints for the 8P8C
    connectors are incorrect!
    [1d_coinctrl_r2-B_Cu.gbr, 1d_coinctrl_r2-B_Mask.gbr, 1d_coinctrl_r2-B_SilkS.gbr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]
2020-06-29 Issue 2 schmatic and Layout
    Added polarity reversal detection to monitor answer supervision.
    [1d_coinctrl_r2-B_Cu.gbr, 1d_coinctrl_r2-B_Mask.gbr, 1d_coinctrl_r2-B_SilkS.gbr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]
2020-07-04 Update firmware for Issue 2.
    The Issue 2 PCB adds support for polarity-reversal detection
    on all four coin lines. This is useful for answer supervision
    detection.
    Hook status inputs are aggregated via an MCP-23008 i2c GPIO
    expander. The MCP-23008 generates an interrupt if any GPIO
    pin changes state, and the PIC microcontroller updates the
    hook state based on this interrupt via external interrupt 2.
    * Change timer0 tick from 10ms to 1ms.
    * Update PIC GPIO pins for Issue 2 PCB.
    * Add support for MCP 23008 i2c GPIO
    * Add support for GPIO interrupts on INT2.
    * Update current hook status via ISR.
    * Remove unnecessary delays.
2020-07-05 Add photo of the Issue 2 PCB.
2020-07-12 Change INT2 interrupt from active high to active low.
2022-07-24 Update for KiCAD 6.06
    [1d_coinctrl_r2.kicad_pcb, 1d_coinctrl_r2.kicad_sch, 1d_coinctrl_r2.sch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]
2022-07-24 Major firmware overhaul.
    * Update for MPLAB X v6.00
    * Swap PIC18F4550 for the newer PIC18F47Q84, removing USB.
    * Remove the MCP23008 i2c I/O expander, use "Interrupt on Change"
    pins directly.
    [main.c]
2022-08-06 Resolve Issue #1: typographical error on board
    [1d_coinctrl_r2-B_Cu.gbr, 1d_coinctrl_r2-B_Mask.gbr, 1d_coinctrl_r2-B_Paste.gbr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]
2022-08-07 Issue 3:
    * Remove barrel jack, replace with 4-position terminal block with
    provision for +/- 130VDC input in case the user already has an
    appropriate power supply and does not want the on-board
    DC-DC converter. Note: 130V DC-DC converter PS2, relay
    K8, C14, D10, and R16 must be omitted during assembly.
    * Add bi-color LEDs for line status.
    Green=Off-hook, normal polarity.
    Red=Off-hook, reverse polarity.
    Off=on-hook.
    * Add header for FTDI USB UART, if user does not RS-232 UART levels.
    To use the FTDI header, do not populate U1 and other components on
    pp. 3 of the schematic.
    * Remove i2c I/O expander and use PIC GPIOs directly.
    [1d_coinctrl_r2-B_Cu.gbr, 1d_coinctrl_r2-B_Mask.gbr, 1d_coinctrl_r2-B_Paste.gbr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]
2024-04-07 Issue 4: Switch from PIC to AVR128DA28 MCU.
    * The AVR128DA28 is supported by the Arduino IDE.
    * Simpler UPDI programming.
    * Update to KiCAD 8.0.1
    * Fix footprint outline for IA1224S DC-DC converter.
    * Add initial Arduino firmware for AVR128DA28 MCU.
    * Move Earth Ground hole.
    * Add jumpers for UART and UPDI configuration.
    * Add 3D-printable end caps for Hammond enclosure.
    * Geographical reannotate PCB.
    [1d_coinctrl-B_Cu.gbr, 1d_coinctrl-B_Mask.gbr, 1d_coinctrl-B_Silkscreen.gbr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]

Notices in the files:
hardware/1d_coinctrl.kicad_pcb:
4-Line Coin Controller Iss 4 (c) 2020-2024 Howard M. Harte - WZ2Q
